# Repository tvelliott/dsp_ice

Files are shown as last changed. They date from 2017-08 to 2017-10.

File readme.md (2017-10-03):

<html>
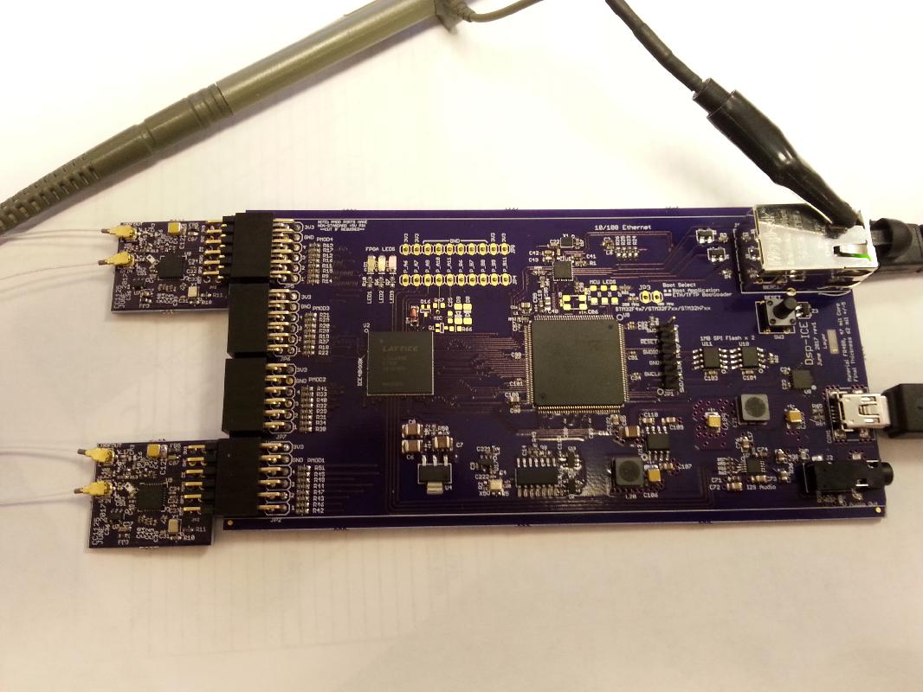
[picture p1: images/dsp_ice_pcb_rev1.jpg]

<BR>
<BR><B>DSP_ICE</B>
<BR>
<B>Project Description</B>
<p>DSP_ICE is an ICE40-8K FPGA dev system that has been developed using gcc and
Project Icestorm toolchains.  The hardware has been fully tested except for the
PDM microphone.  Firmware/HDL examples are provided to test the hardware,
including an 8-channel, multi-waveform audio synthesizer and peak amplitude,
frequency measurement via CMSIS DSP FFT functions utilizing the LTC1420 ADC
expansion module.
</p>
<BR>
<B>Why Develop Another ICE40 Dev Board?</B>
<p>
DSP ICE was developed because other boards didn't have all the features desired.
The ultimate goal is to develop an SDR with swappable analog/RF front-ends.
Desired features that drove the development were:
<BR>1) 10/100 Ethernet
<BR>2) 8K ICE 40 device that could be done with 5mil spaced, 4-layer pcb
<BR>3) I2S audio output
<BR>4) STM32F4 device that is foot-print compatible with F7 and H7 series for future
<BR>5) 16-bit FSMC memory-bus interface between the MCU and FPGA
<BR>6) Low-noise power supplies with plenty of current for expansion modules
<BR>7) Plenty of expansion I/O pins designed to utilize upper limits on frequency with ICE40
</p>

<H3><a href="https://raw.githubusercontent.com/tvelliott/dsp_ice/master/firmware/audio_synth_test/dsp_ice_audio_synth_test.mp3">8-channel audio synth test.mp3</a> audio output from example audio-synth implemented in Verilog</H3> 

<BR>
<BR>
<B>Features:</B>
<BR>
<BR>STM32F417 MCU  (upgradable with drop-in for F7 and H7 series up to 400 MHz)
<BR>ICE40HX8K-CT256 FPGA (largest ICE40 device available)
<BR>16-Bit FSMC interface between MCU <-> FPGA.  Interface clock is running @ 80 MHz
<BR>10-100 Mbps Ethernet interface  (firmware includes iperf3 server for testing bandwidth)
<BR>ST-Link programming header  (can use STM32F4-Discovery as a programming device)
<BR>I2S Audio interface  (firmware includes example of 8-channel audio synth with sawtooth, pulse, noise waveforms and a song playback via I2S)
<BR>4 PMOD-Like ports  (include 5V and 3.3V and 8 I/O pins x 4)
<BR>USB FTDI-based serial interface  (update 8/13/2017 firmware to test the uart interface has been added)
<BR>40 MHz TCXO crystal driving both FPGA and MCU  (MCU clock div/2)

<BR>
<BR>
<B>Verilog Source Is Here</B>
<BR>
<a href="https://github.com/tvelliott/dsp_ice/tree/master/firmware/fpga/src">/firmware/fpga/src</a>
<BR>

<BR>
<B>DSP ICE MCU 16-bit Memory-Mapped FPGA registers</B>
<BR>
<pre>
0x60000000   spi1_ctrl
0x60000002   spi1_data_in
0x60000004   spi1_data_out
0x60000006   spi1_cs_ctrl

0x60000008   spi2_ctrl
0x6000000a   spi2_data_in
0x6000000c   spi2_data_out
0x6000000e   spi2_cs_ctrl

0x60000010   adc_data  (LTC1420 hw module, read-only, bit0 is OF) 

0x60001000   audio_ctrl
0x60001002   left_sample
0x60001004   right_sample
0x60001006   tone1_freq
0x60001008   tone2_freq
0x6000100a   tone3_freq
0x6000100c   tone4_freq
0x6000100e   tone5_freq
0x60001010   tone6_freq
0x60001012   tone7_freq
0x60001014   tone8_freq
0x60001016   waveform_ctrl

0x6000f000   16-bit random number (ro)
</pre>

<B>PCB Design</B>
<BR>4 layers
<BR>Designed for OSH Park 4 layer service.  (5 mil spacing)
<BR>Have assembled 4 boards without any connectivity issues on the 256-pin BGA

<B>Left To Do</B>
<BR>The PDM michrophone has not been tested yet due to trouble getting the part.  
<BR>Digikey has the part in stock, but Cirrus Logic will not allow them to sell 
<BR>it to certain individuals including the author of this project. There were
<BR>no further explanations from Cirrus Logic.
<BR>
<BR>
<B>Building The Firmware</B>
<PRE>
Instructions (tested on Debian 8 system)

1) download GNU ARM Embedded Toolchain from here:

<a href="https://launchpad.net/gcc-arm-embedded"> https://launchpad.net/gcc-arm-embedded </a>

The test firmare was compiled with version:
gcc-arm-none-eabi-5_4-2016q3-20160926-linux.tar.bz2

2) *edit the makedefs_fp and change PRE_PREFIX to point to the absolute path of
the toolchain directory *optionally,  move the uncompressed toolchain folder to
the project folder and rename to gnu_arm_toolchain

3) From the project directory, In order to re-build the FPGA binary image, type
'sh build_fpga_image.sh'  (requires that Project Icestorm tools are installed)

  yosys  (synthesis tool)  <a href="http://www.clifford.at/icestorm/"> http://www.clifford.at/icestorm/</a>
  ice-tools  (tools for maniuplating text/binaries and programming dev boards) 
  arache-pnr  (place-and-route)  <a href="https://github.com/cseed/arachne-pnr"> https://github.com/cseed/arachne-pnr </a>

  Note:  The fpga binary configuration image will be compressed and converted
to a header file for inclusion to the MCU firmware image:  fpga_image.h The
compressed image in fpga_image.h will be included in fpga.c on the next mcu
firmware build  (step 4) The MCU uncompresses and transfers the fpga config
image during startup.

4) From the project directory, type 'make clean' followed by  'make' The
resulting binary will be copied to /tmp folder and also the build_image folder
in the current project directory Note: the prototypes in protos can be
re-generated with 'make genprotos' if cfunctions is installed.

5) An ST-Link programmer can be used to load the resulting binary
(main_image_0x8000000.bin) to address 0x8000000

   A $15 STM32F4 Discovery board with the jumpers set to "ST Link"  (pulled
off) and a straight-thru, 6-pin 0.1" pitch cable will work.

   Follow instructions for compiling OpenOCD  <a href="http://openocd.org/"> http://openocd.org/</a>

   start the debugger:  'sudo src/openocd -s tcl -f tcl/board/stm32f4discovery.cfg'

   'telnet localhost 4444'
    > reset halt
    > flash write_image erase build_image/main_image_0x8000000.bin 0x8000000

6) Test the hardware.
   telnet 192.168.1.240   (default ip address.  edit this in config.c)
   
Trying 192.168.1.240...
Connected to 192.168.1.240.
Escape character is '^]'.

Connected To STM32F417 Running @ 168 MHz
DSP_Ice 192.168.1.240:~$ help

Available commands:

testmem
testsnd
testflash1
testflash2
testadc
reset
exit

DSP_Ice 192.168.1.240:~$ testadc
<B>Example measurement of 500 KHz sine wave, 100mVpp utilize LTC1420 ADC HW module</B>
<B>This example utilizes the CMSIS DSP Co-Processor functions of the MCU for FFT calcs.</B>
<B>Using DMA to transfer ADC results from FPGA BRAM would dramatically improve sample rate</B>
peak signal 502675.781 Hz,  0.107 Volts p-p, elapsed time 3.51 ms  
<a href="https://github.com/tvelliott/dsp_ice/blob/master/hw_modules/ltc1420_adc/fft_plot_500khz_100mVpp.gif">[see fft plot 500khz, 100mV p-p]</a> 
<a href="https://github.com/tvelliott/dsp_ice/blob/master/hw_modules/ltc1420_adc/ltc1420_capture_3.5vpp_no_filter_325khz_freqdomain.gif">[see fft plot 325Khz, 3500mV p-p]</a> 
<a href="https://github.com/tvelliott/dsp_ice/blob/master/hw_modules/ltc1420_adc/ltc1420_capture_3.5vpp_no_filter_500khz_timedomain.gif">[see time-domain plot 500khz, 3500mV p-p]</a> 
 
DSP_Ice 192.168.1.240:~$ testmem   (this tests the 16-bit FSMC memmory-mapped, MCU<->FPGA interface)

x100x (FPGA D-REG), 4015677440 bytes r/w random access, current vals: f3e7,f3e7, errors: 0
0x100x (FPGA D-REG), 4015685632 bytes r/w random access, current vals: 69c4,69c4, errors: 0
0x100x (FPGA D-REG), 4015693824 bytes r/w random access, current vals: af9a,af9a, errors: 0
0x100x (FPGA D-REG), 4015702016 bytes r/w random access, current vals: bc6a,bc6a, errors: 0
0x100x (FPGA D-REG), 4015710208 bytes r/w random access, current vals: 8732,8732, errors: 0
0x100x (FPGA D-REG), 4015718400 bytes r/w random access, current vals: 06f4,06f4, errors: 0
0x100x (FPGA D-REG), 4015726592 bytes r/w random access, current vals: 32af,32af, errors: 0
.....

DSP_Ice 192.168.1.240:~$ sh test_iperf.sh

Connecting to host 192.168.1.240, port 5201
[  4] local 192.168.1.3 port 45612 connected to 192.168.1.240 port 5201
[ ID] Interval           Transfer     Bandwidth       Retr  Cwnd
[  4]   0.00-1.00   sec  8.91 MBytes  74.7 Mbits/sec    0   14.3 KBytes       
[  4]   1.00-2.00   sec  8.88 MBytes  74.5 Mbits/sec    0   14.3 KBytes       
[  4]   2.00-3.00   sec  8.86 MBytes  74.3 Mbits/sec    0   14.3 KBytes       
[  4]   3.00-4.00   sec  8.86 MBytes  74.3 Mbits/sec    0   14.3 KBytes       
[  4]   4.00-5.00   sec  8.88 MBytes  74.5 Mbits/sec    0   14.3 KBytes       
[  4]   5.00-6.00   sec  8.87 MBytes  74.4 Mbits/sec    0   14.3 KBytes       
[  4]   6.00-7.00   sec  8.86 MBytes  74.3 Mbits/sec    0   14.3 KBytes       
[  4]   7.00-8.00   sec  8.86 MBytes  74.3 Mbits/sec    0   14.3 KBytes       
[  4]   8.00-9.00   sec  8.86 MBytes  74.3 Mbits/sec    0   14.3 KBytes       

iperf Done.

....
DSP_Ice 192.168.1.240:~$ testsnd   (song playback via 8-channel audio synth implemented on fpga)

change instrument: ch: 0,  instr: 29, mask: 5555
chan: 0, freq: 554
change instrument: ch: 1,  instr: 37, mask: 5555
chan: 1, freq: 92
change instrument: ch: 2,  instr: 16, mask: 5575
chan: 2, freq: 233
change instrument: ch: 3,  instr: 29, mask: 5575
chan: 3, freq: 370
change instrument: ch: 4,  instr: 16, mask: 5775
chan: 4, freq: 131
change instrument: ch: 5,  instr: 16, mask: 5f75
chan: 5, freq: 131
duration: 91
duration: 91
chan: 0, freq: 494
chan: 3, freq: 330
duration: 91
duration: 91
chan: 2, freq: 208
chan: 0, freq: 554
chan: 3, freq: 370
duration: 91
duration: 91
chan: 0, freq: 494
chan: 3, freq: 330
duration: 91
duration: 91
chan: 0, freq: 554
chan: 3, freq: 370
duration: 91
duration: 91

<B>Images Of LTC1420 HW Module and PCB cad rendering</B>
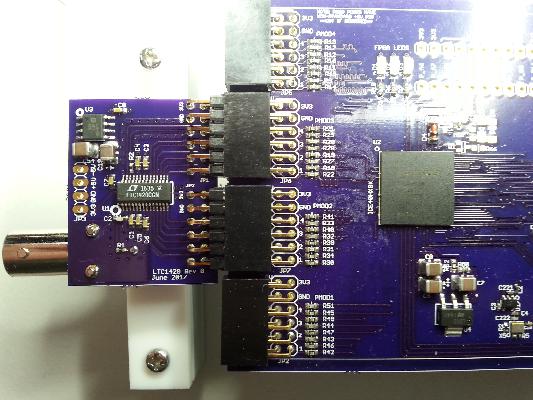
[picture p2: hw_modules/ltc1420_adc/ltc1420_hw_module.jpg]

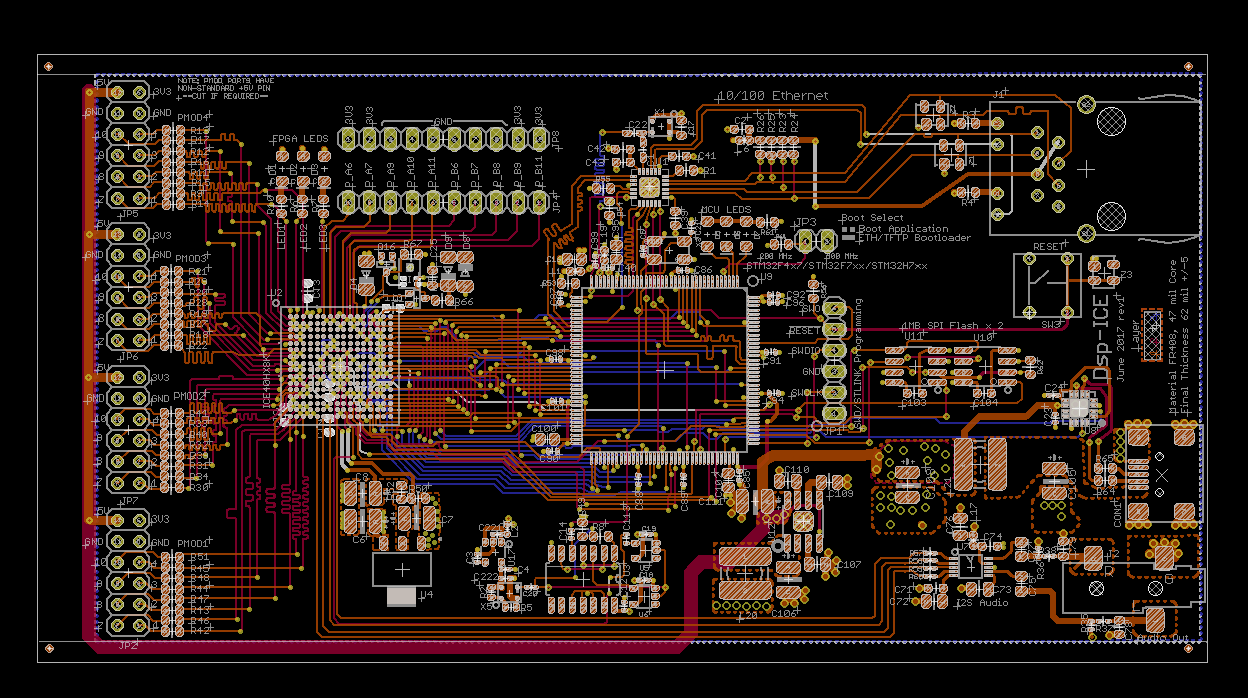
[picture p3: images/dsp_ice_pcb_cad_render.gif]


....
</PRE>

<B>Links To Similar Projects</B>
<BR>
<a href="https://github.com/emeb/iceRadio">https://github.com/emeb/iceRadio</a>
<BR><BR>
<B>Links To Related Resources</B>
<BR>
<BR><a href="https://launchpad.net/gcc-arm-embedded"> https://launchpad.net/gcc-arm-embedded </a>
<BR><a href="http://www.clifford.at/icestorm/"> http://www.clifford.at/icestorm/</a>
<BR><a href="https://github.com/cseed/arachne-pnr"> https://github.com/cseed/arachne-pnr </a>
<BR><a href="http://openocd.org/"> http://openocd.org/</a>

</html>

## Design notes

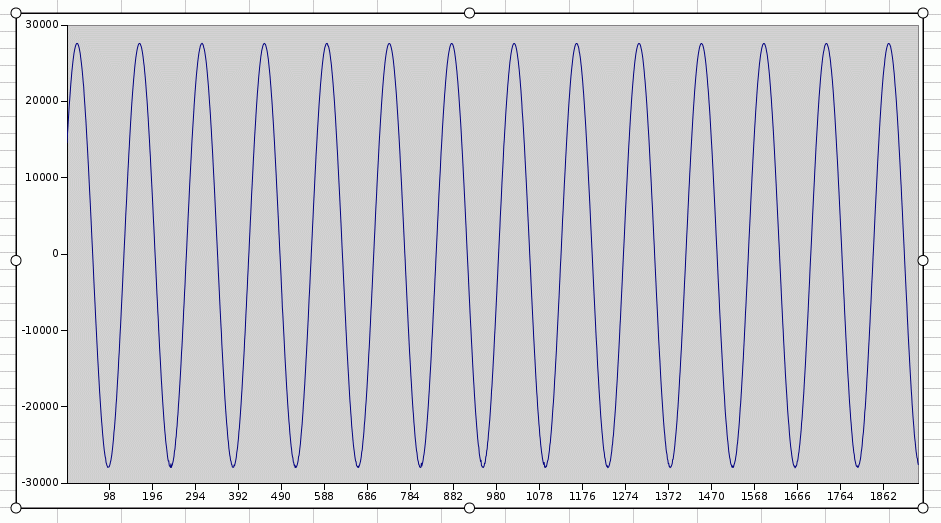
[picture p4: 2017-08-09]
hw_modules/ltc1420_adc/ltc1420_capture_3.5vpp_no_filter_500khz_timedomain.gif

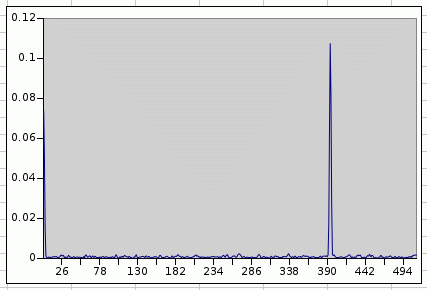
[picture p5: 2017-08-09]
hw_modules/ltc1420_adc/fft_plot_500khz_100mVpp.gif

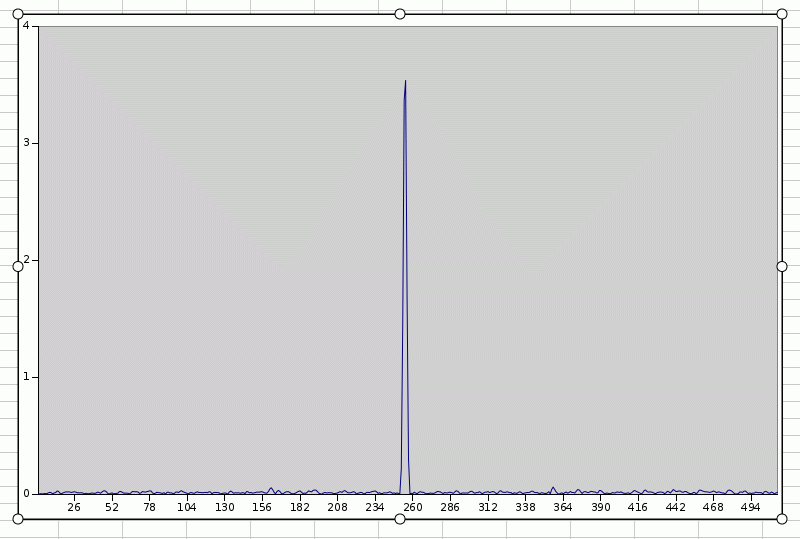
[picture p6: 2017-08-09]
hw_modules/ltc1420_adc/ltc1420_capture_3.5vpp_no_filter_325khz_freqdomain.gif

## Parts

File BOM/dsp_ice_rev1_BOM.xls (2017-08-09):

Qty | Value | MANUFACTURER | MFG PART# | DK PART# | Package | Ref Designator | NOTES | Description
3 |  | Nexperia USA Inc. | BAS85,115 | 1727-2899-1-ND | MINIMELF | D4, D8, D9 |  | Diode Schottky 30V 200mA Surface Mount LLDS; MiniMelf
2 | RED | Kingbright | APT3216LSECK/J3-PRV | 754-1940-1-ND | 1206 | D1, D5 |  | Red 625nm LED Indication - Discrete 1.8V 1206 (3216 Metric)
2 | GREEN | Kingbright | APT3216LZGCK | 754-1944-1-ND | 1206 | D2, D6 |  | Green 525nm LED Indication - Discrete 2.65V 1206 (3216 Metric)
2 | YELLOW | Kingbright | APT3216LSYCK/J3-PRV | 754-1942-1-ND | 1206 | D3, D7 |  | Yellow 590nm LED Indication - Discrete 1.85V 1206 (3216 Metric)
1 |  | Wurth Electronics Inc | 61300611121 | 732-5319-ND | 1X06 | JP1 |  | 6 Positions Header, Unshrouded Connector 0.100" (2.54mm) Through Hole Gold
4 |  | Sullins Connector Solutions | PPPC062LJBN-RC | S5559-ND | 2X06 | JP2, JP5, JP6, JP7 | PMOD CONNECTOR | 12 Position Header Connector 0.100" (2.54mm) Through Hole, Right Angle Gold
1 |  | Taiyo Yuden | BK1005HM102-T | 587-1835-1-ND | 0402 | L2 |  | FERRITE BEAD 1 KOHM 0402 1LN
4 |  | TDK Corporation | MMZ1608S102ATA00 | 445-1550-1-ND | 0603 | L1, L6, L17, L19 |  | FERRITE BEAD 1 KOHM 0603 1LN
1 | .01uF | Murata Electronics North America | GRM155R71H103KA88D | 490-4516-1-ND | 0402 | C3 |  | 10000pF ±10% 50V Ceramic Capacitor X7R 0402 (1005 Metric)
9 | 0.1uF | Yageo | CC0603ZRY5V9BB104 | 311-1343-1-ND | 0603 | C2, C9, C17, C39, C41, C71, C74, C103, C104 |  | 0.1µF -20%, +80% 50V Ceramic Capacitor Y5V (F) 0603 (1608 Metric
14 | 0.1uF | Murata Electronics North America | GRM155R71C104KA88J | 490-6328-1-ND | 0402 | C40, C85, C86, C87, C88, C89, C90, C91, C92, C94, C96, C98, C99, C101 |  | 0.1µF ±10% 16V Ceramic Capacitor X7R 0402 (1005 Metric)
4 | 1.0uF | Taiyo Yuden | JMK105BJ105KV-F | 587-1231-1-ND | 0402 | C4, C221, C23, C24 |  | 1µF ±10% 6.3V Ceramic Capacitor X5R 0402 (1005 Metric)
39 | 10 | Yageo | RC0603FR-0710RL | 311-10.0HRCT-ND | 0603 | R9, R11, R12, R13, R14, R15, R16, R17, R18, R19, R20, R21, R22, R27, R28, R29, R30, R31, R32, R33, R34, R39, R40, R41, R42, R43, R44, R45, R46, R47, R48, R51, R52, R57, R58, R59, R60, R64, R65 |  | 10 Ohm ±1% 0.1W, 1/10W Chip Resistor 0603 (1608 Metric) Moisture Resistant Thick Film
2 | 100pF | Johanson Technology Inc. | 251R14S101JV4T | 712-1310-1-ND | 0603 | C1, C22 |  | 100pF ±5% 250V Ceramic Capacitor C0G, NP0 0603 (1608 Metric)
2 | 10k | Vishay Dale | CRCW040210K0FKED | 541-10.0KLCT-ND | 0402 | R35, R36 |  | 10k Ohm ±1% 0.063W, 1/16W Chip Resistor 0402 (1005 Metric) Automotive AEC-Q200 Thick Film
2 | 10uF | Murata Electronics North America | GRM21BR60J106ME19L | 490-1718-1-ND | 0805 | C72, C73 |  | 10µF ±20% 6.3V Ceramic Capacitor X5R 0805 (2012 Metric)
7 | 12.1k | Yageo | RC0603FR-0712K1L | 311-12.1KHRCT-ND | 0603 | R1, R53, R54, R55,R56, R62, R63 |  | 12.1k Ohm ±1% 0.1W, 1/10W Chip Resistor 0603 (1608 Metric) Moisture Resistant Thick Film
1 | 120 | Yageo | RC0603JR-07120RL | 311-120GRCT-ND | 0603 | R50 |  | 120 Ohm ±5% 0.1W, 1/10W Chip Resistor 0603 (1608 Metric) Moisture Resistant Thick Film
1 |  | TE Connectivity AMP Connectors | 1734035-2 | A31727CT-ND |  | CON1 |  | USB - mini B USB 2.0 Receptacle Connector 5 Position Surface Mount, Right Angle
1 | 18pF | AVX Corporation | 04025A180JAT2A | 478-1073-1-ND | 0402 | C222 |  | 18pF ±5% 50V Ceramic Capacitor C0G, NP0 0402 (1005 Metric)
6 | 1uF | Murata Electronics North America | GRM188R61C105KA93D | 490-1536-1-ND | 0603 | C10, C11, C13, C15, C42, C25 |  | 1µF ±10% 16V Ceramic Capacitor X5R 0603 (1608 Metric)
10 | 2.2uF | Murata Electronics North America | GRM21BR70J225KA01L | 490-1698-1-ND | 0805 | C16, C75, C76, C77, C95, C100, C102, C107, C109, C110 |  | 2.2µF ±10% 6.3V Ceramic Capacitor X7R 0805 (2012 Metric)
4 | 22uF | Taiyo Yuden | JMK325BJ226MM-T | 587-1384-1-ND | 1210 | C6, C7, C8, C111 |  | 22µF ±20% 6.3V Ceramic Capacitor X5R 1210 (3225 Metric)
2 | 22uH_744053220 | Wurth Electronics Inc | 744053220 | 732-1047-1-ND | 2323 | L20, L21 |  | 22µH Shielded Wirewound Inductor 1.15A 120 mOhm Max 2323 (5858 Metric)
6 | 270 | Yageo | RC0603JR-07270RL | 311-270GRCT-ND | 0603 | R3, R4, R6, R7, R10, R61 |  | 270 Ohm ±5% 0.1W, 1/10W Chip Resistor 0603 (1608 Metric) Moisture Resistant Thick Film
4 | 4.87K | Vishay Dale | CRCW06034K87FKEA | 541-4.87KHCT-ND | 0603 | R8, R49, R66, R67 |  | 4.87k Ohm ±1% 0.1W, 1/10W Chip Resistor 0603 (1608 Metric) Automotive AEC-Q200 Thick Film
4 | 470 (Tc=50ppm) | Vishay Dale | CRCW0402470RFKED | 541-470LCT-ND | 0402 | R2, R5, R37, R38 |  | 470 Ohm ±1% 0.063W, 1/16W Chip Resistor 0402 (1005 Metric) Automotive AEC-Q200 Thick Film
1 | 470pF | KEMET | C0603C471F5GACTU | 399-7919-1-ND | 0603 | C43 |  | 470pF ±1% 50V Ceramic Capacitor C0G, NP0 0603 (1608 Metric)
3 | 470uF_tant | AVX Corporation | F950G477MBAAQ2 | 478-8384-1-ND | 1210 | C105, C106, C108 |  | 470µF ±20% Conformal Coated Tantalum Capacitors 4V 1210 (3528 Metric) 400 mOhm
6 | 47nF | Murata Electronics North America | GRM155R71E473KA88D | 490-3254-1-ND | 0402 | C12, C14, C18, C19, C20, C113 |  | 0.047µF ±10% 25V Ceramic Capacitor X7R 0402 (1005 Metric)
4 | 49.9 | Vishay Dale | CRCW060349R9FKEA | 541-49.9HCT-ND | 0603 | R23, R24, R25, R26 |  | 49.9 Ohm ±1% 0.1W, 1/10W Chip Resistor 0603 (1608 Metric) Automotive AEC-Q200 Thick Film
2 |  | Texas Instruments | SN74LVC1G04DBVR | 296-11599-1-ND | SOT23-5 | U5, U6 |  | IC SINGLE INVERTER-GATE SOT-23-5
2 | 8200pF | TDK Corporation | C1608C0G1E822J080AA | 445-2668-1-ND | 0603 | C78, C79 |  | 8200pF ±5% 25V Ceramic Capacitor C0G, NP0 0603 (1608 Metric)
1 |  | Analog Devices Inc. | ADP7156ARDZ-3.3-R7 | ADP7156ARDZ-3.3-R7CT-ND | SO8 | U12 |  | Linear Voltage Regulator IC Positive Fixed 1 Output 3.3V 1.2A 8-SOIC Exposed Pad
1 | 50mhz | Abracon LLC | ASDM1-50.000MHZ-LC-T | 535-9801-1-ND | 2.5mm x 2mm | X1 |  | 50Mhz LVCMOS MEMS (Silicon) Oscillator Surface Mount 3.3V 10mA Standby (Power Down)
1 | 40mhz | Abracon LLC | ASVTX-12-A-40.000MHZ-I15-T | 535-11793-1-ND | 2.5mm x 2mm | X5 |  | 40Mhz Clipped Sine Wave VCTCXO Oscillator Surface Mount 3V 2.5mA
1 |  | Cirrus Logic Inc. | CS4344-DZZ | 598-1634-ND | 10-TSSOP | U7 |  | DAC, Audio 24 bit 192k SPI 10-TSSOP
1 |  | Lattice Semiconductor Corporation | ICE40HX8K-CT256 | 220-1575-ND | CABGA256 | U2 |  | IC FPGA 206 I/O 256CABGA
1 |  | Microchip Technology | LAN8742AI-CZ | LAN8742AI-CZ-ND | QFN-24 | U1 |  | 1/1 Transceiver Full Ethernet 24-SQFN (4x4)
1 |  | STMicroelectronics | LD1117S12TR | 497-4240-1-ND | SOT-223 | U4 |  | Linear Voltage Regulator IC Positive Fixed Output 1.2V 800mA SOT-223
2 |  | Cypress Semiconductor Corp | S25FL116K0XMFI041 | 1274-1106-ND | SO8 | U10, U11 |  | IC FLASH 16MBIT 108MHZ 8SOIC
1 |  | Stewart Connector | SI-50170-F | 380-1103-ND | SI-50170 | J1 |  | 1 Port RJ45 Magjack Connector Through Hole 10/100 Base-T, AutoMDIX
1 |  | CUI Inc | SJ-3523-SMT-TR | CP-3523SJCT-ND | 3523 | J2 |  | 3.50mm (0.141", 1/8", Mini Plug) - Headphone Phone Jack Stereo Connector Solder
1 |  | ON Semiconductor | MC74AC74DR2G | MC74AC74DR2GOSCT-ND | SO14 | U3 |  | IC D-TYPE POS TRG DUAL 14SOIC
3 |  | Semtech Corporation | SR3.3.TCT | SR3.3CT-ND | SR2.8.TCT_1PRIMARY | Z1, Z2, Z3 |  | TVS DIODE 3.3VWM 15VC SOT143
1 |  | STMicroelectronics | STM32F765ZGT6 | 497-16632-ND | TQFP-144 | U9 |  | ARM® Cortex®-M7 STM32 F7 Microcontroller IC 32-Bit 216Mhz 1MB (1M x 8) FLASH, 512KB RAM, 144-LQFP (20x20)
1 |  | Texas Instruments | TPS79930DDCR | 296-39500-1-ND | SOT23-6 | U17 |  | Linear Voltage Regulator IC Positive Fixed Output 3V 200mA SOT-23-5
1 |  | FTDI, Future Technology Devices International Ltd | FT230XQ-R | 768-1130-1-ND | 16-QFN | U8 |  | USB Bridge, USB to UART USB 2.0 UART Interface 16-QFN (4x4)
1 |  | Cirrus Logic Inc. | CS7250B-CAZR | 598-2449-1-ND | BOTTOM PORT | U13 |  | 35Hz ~ 13kHz Digital, PDM Microphone MEMS (Silicon) 1.8V Omnidirectional (-36dB ±1dB @ 94dB SPL)
2 |  | Diodes Incorporated | 2N7002W-7-F | 2N7002W-FDICT-ND | MINIMELF | Q1,Q16 |  | N-Channel 60V 115mA (Ta) 200mW (Ta) Surface Mount SOT-323
DNP |  | JP4, JP8
 |  | X3, C5, C21
Document History
elliott | 2017-05-15 | creation | rev0
elliott | 2017-June-27 | add R57, R58, R59, R60 | rev1
 |  | add R53,R54,R55,R56 | rev1
 |  | change package on C105, C108 | rev1
 |  | add D5, D6, D7 | rev1
 |  | add R61 | rev1
 |  | add X3, C5, C21 DNP | rev1
 |  | add R62 | rev1
 |  | add U8 | rev1
 |  | add R65 | rev1
 |  | add C24 | rev1
 |  | add C23 | rev1
 |  | add R64 | rev1
 |  | add R63 | rev1
 |  | add SW3 | rev1
 |  | add Z3 | rev1
 |  | add U13 | rev1
 |  | add Q1 | rev1
 |  | add Q16 | rev1
 |  | add R67 | rev1
 |  | add R66 | rev1
 |  | add D8 | rev1
 |  | add D9 | rev1
 |  | add C25 | rev1

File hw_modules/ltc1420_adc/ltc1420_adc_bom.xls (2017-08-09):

Qty | Value | MANUFACTURER | MFG PART# | DK PART# | Package | Ref Designator | NOTES | Description
2 |  | Sullins Connector Solutions | PRPC006DBAN-M71RC | S2111EC-06-ND | 2X06 | JP1, JP2 |  | 12 Positions Header, Breakaway Connector 0.100" (2.54mm) Through Hole, Right Angle Gold
1 |  | Molex | 731000105 | WM5524-ND | BNC | J1 |  | BNC Connector Receptacle, Female Socket 50 Ohm Through Hole, Right Angle Solder
7 | 1uF | Murata Electronics North America | GRM188R61C105KA93D | 490-1536-1-ND | 0603 | C1, C3, C4, C5, C6, C7, C8 |  | 1µF ±10% 16V Ceramic Capacitor X5R 0603 (1608 Metric)
2 | 22uF | Taiyo Yuden | JMK325BJ226MM-T | 587-1384-1-ND | 1210K | C19, C54 |  | 22µF ±20% 6.3V Ceramic Capacitor X5R 1210 (3225 Metric)
2 | 30 | Yageo | RC0402JR-0730RL | 311-30JRCT-ND | R0402 | R1, R2 |  | 30 Ohm ±5% 0.063W, 1/16W Chip Resistor 0402 (1005 Metric) Moisture Resistant Thick Film
1 | 470pF | Murata Electronics North America | GRM1885C2A471JA01D | 490-1367-1-ND | C0603 | C2 |  | 470pF ±5% 100V Ceramic Capacitor C0G, NP0 0603 (1608 Metric)
1 | ADM660 | Analog Devices Inc. | ADM660ARZ-REEL7 | ADM660ARZ-REEL7CT-ND | SO8 | U3 |  | Charge Pump Switching Regulator IC Positive or Negative Fixed -Vin, 2Vin 1 Output 100mA 8-SOIC (0.154", 3.90mm Width)
1 | LTC1420CGNPBF | Linear Technology | LTC1420CGN#PBF | LTC1420CGN#PBF-ND | SSOP-28_GN | U1 |  | 12 Bit Analog to Digital Converter 1 Input 1 Pipelined 28-SSOP
 | DNP | JP3
 | HISTORY
 | t.elliott | 2017-06-28 | document creation.

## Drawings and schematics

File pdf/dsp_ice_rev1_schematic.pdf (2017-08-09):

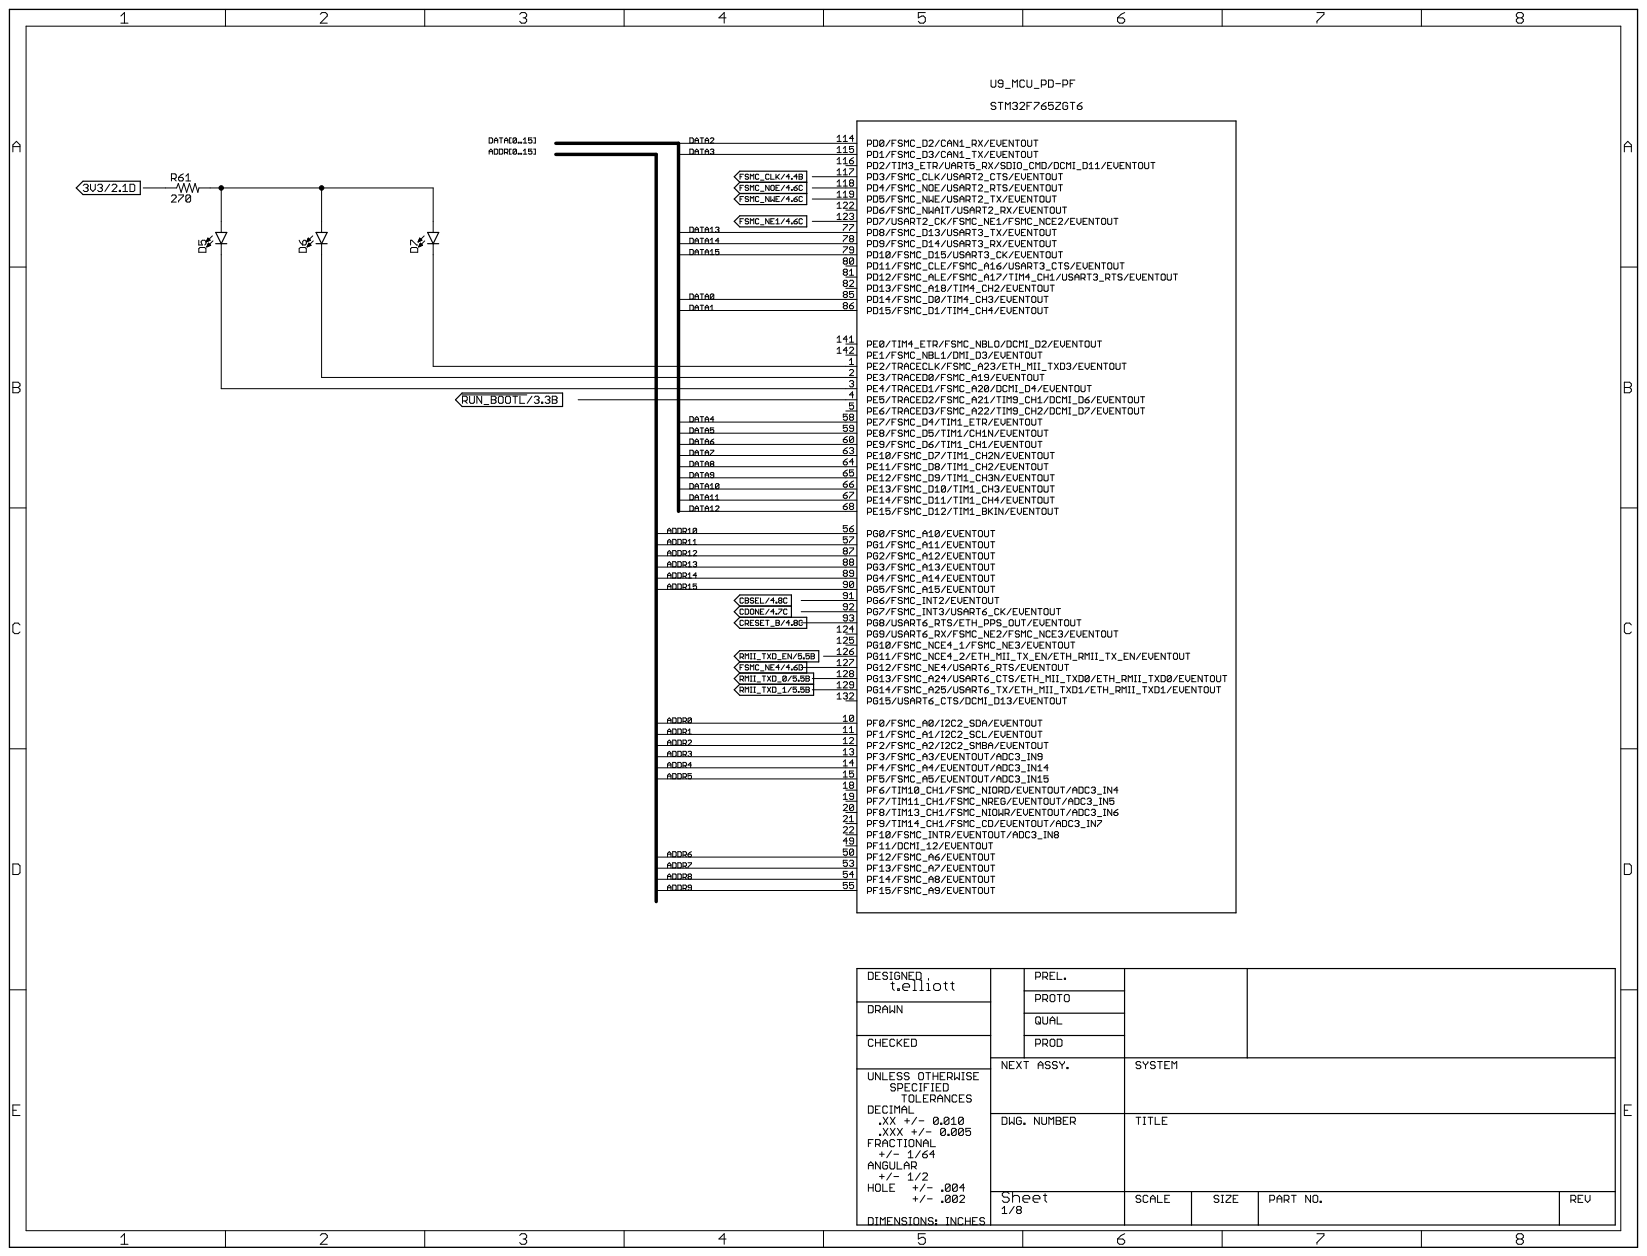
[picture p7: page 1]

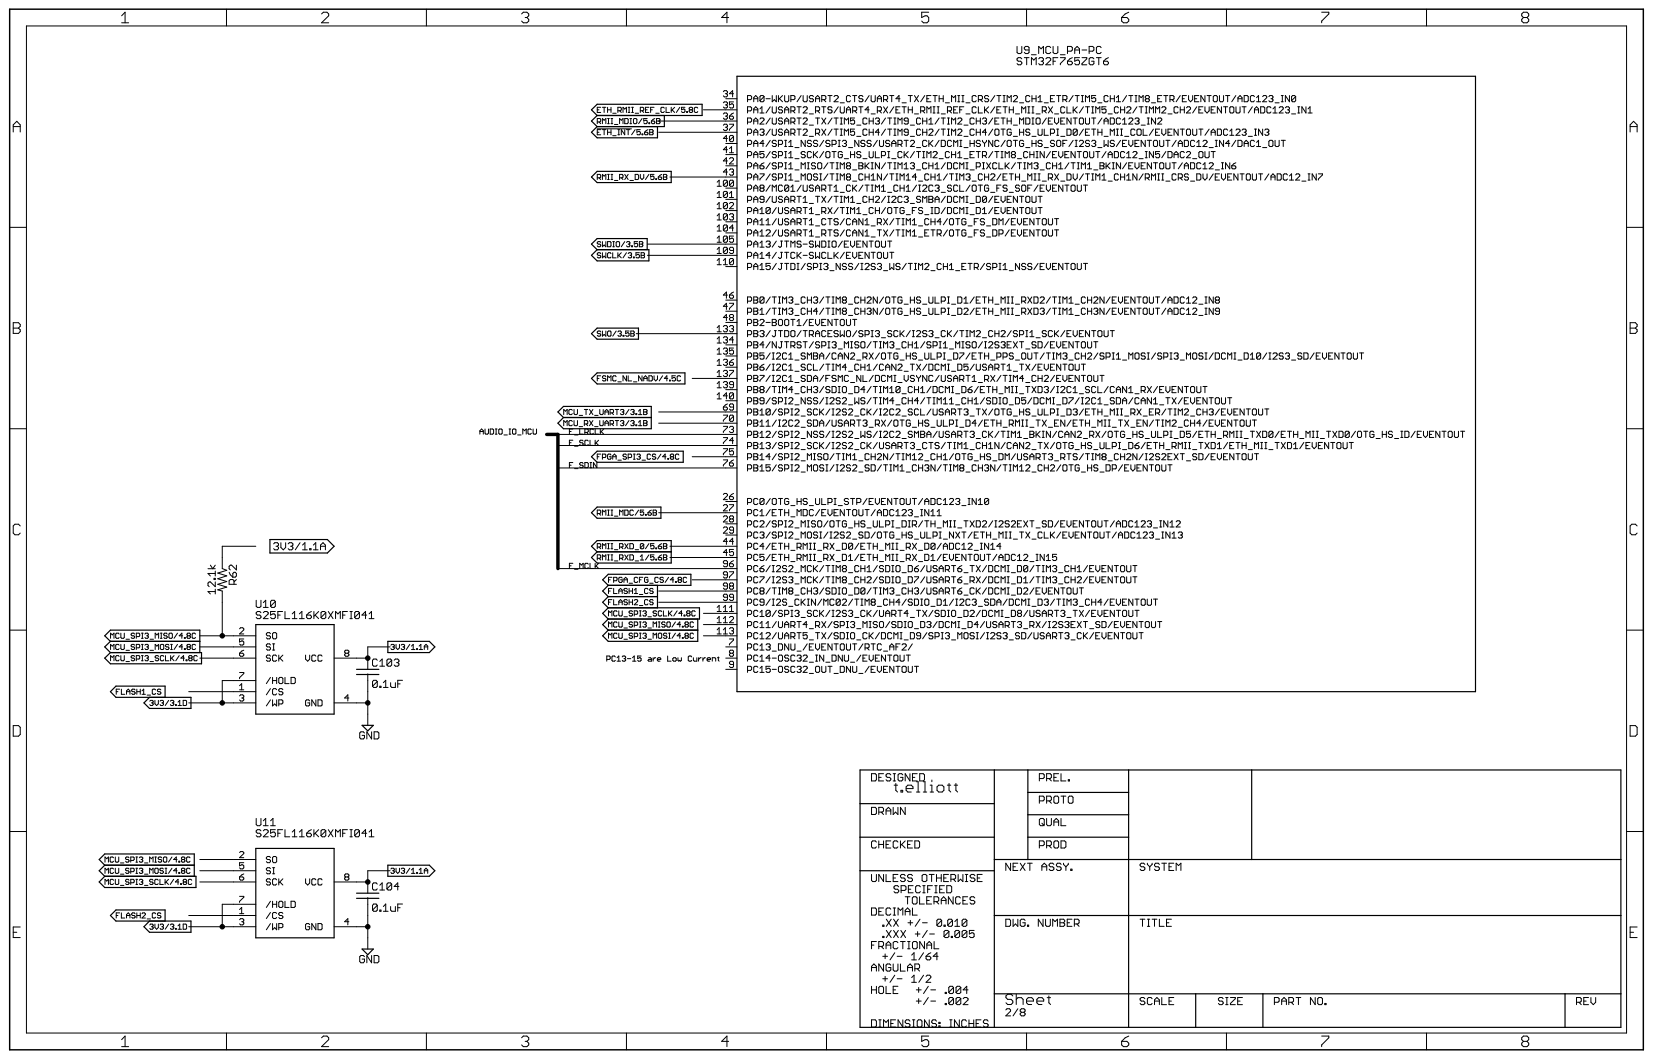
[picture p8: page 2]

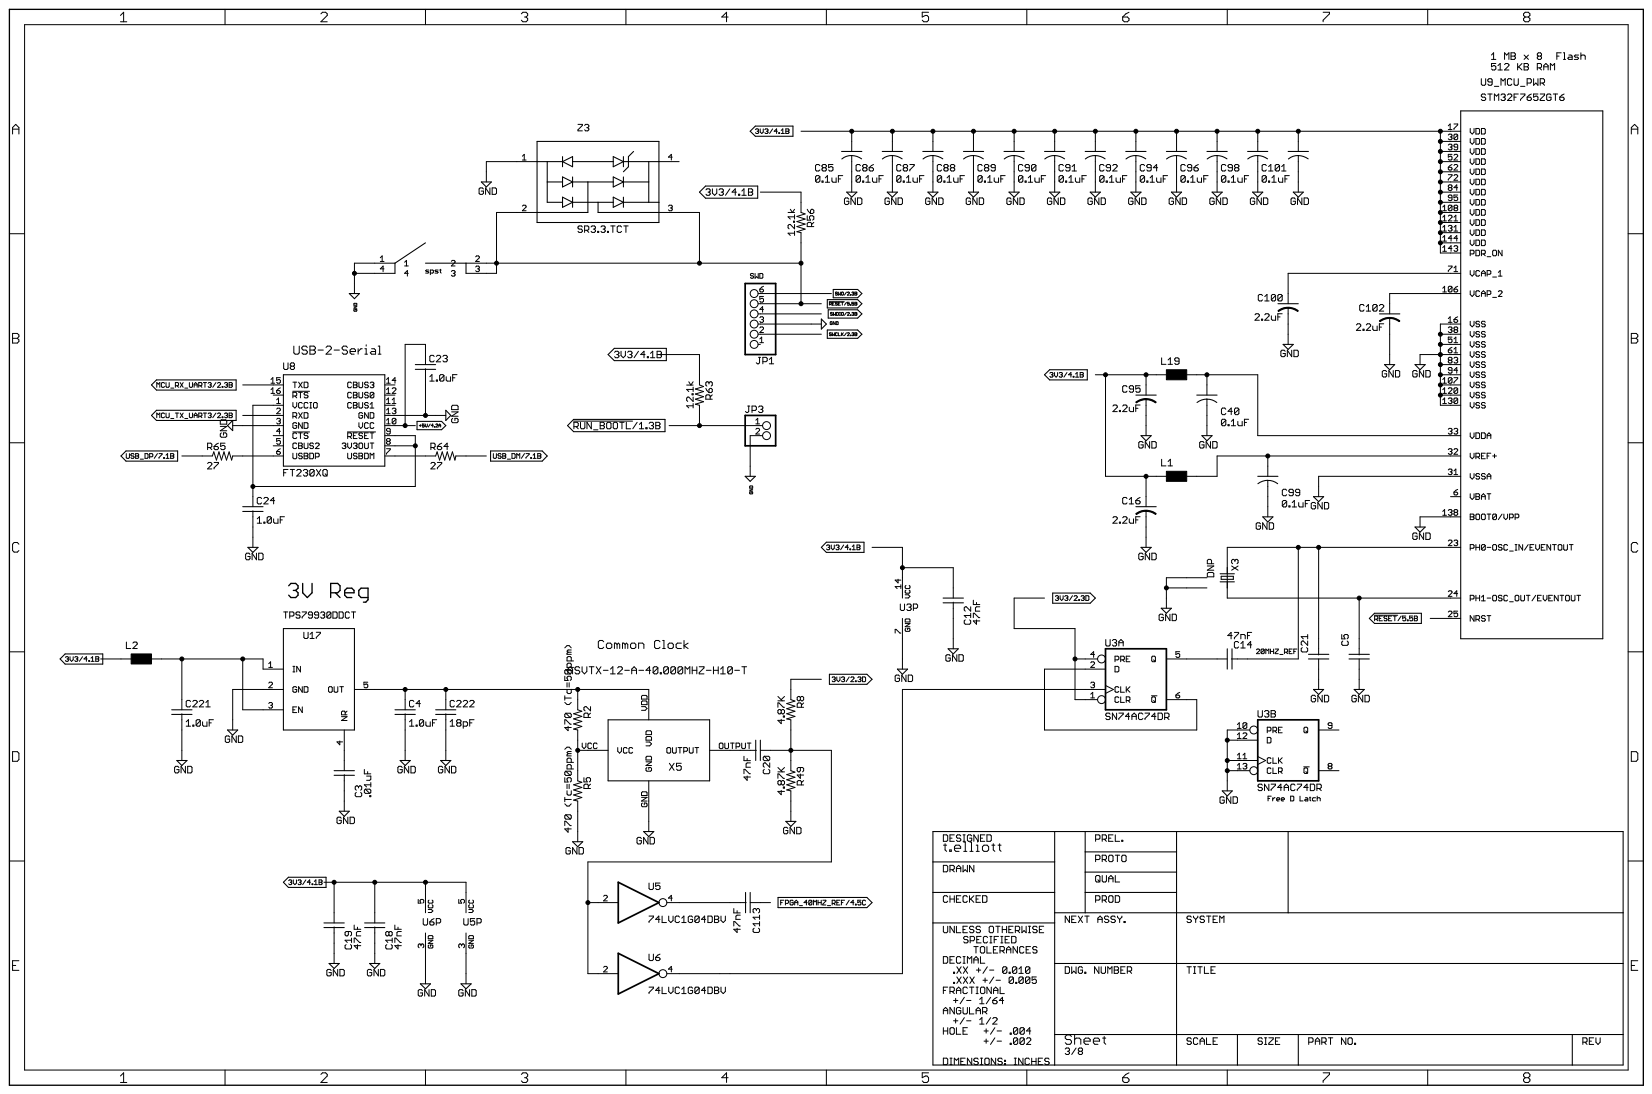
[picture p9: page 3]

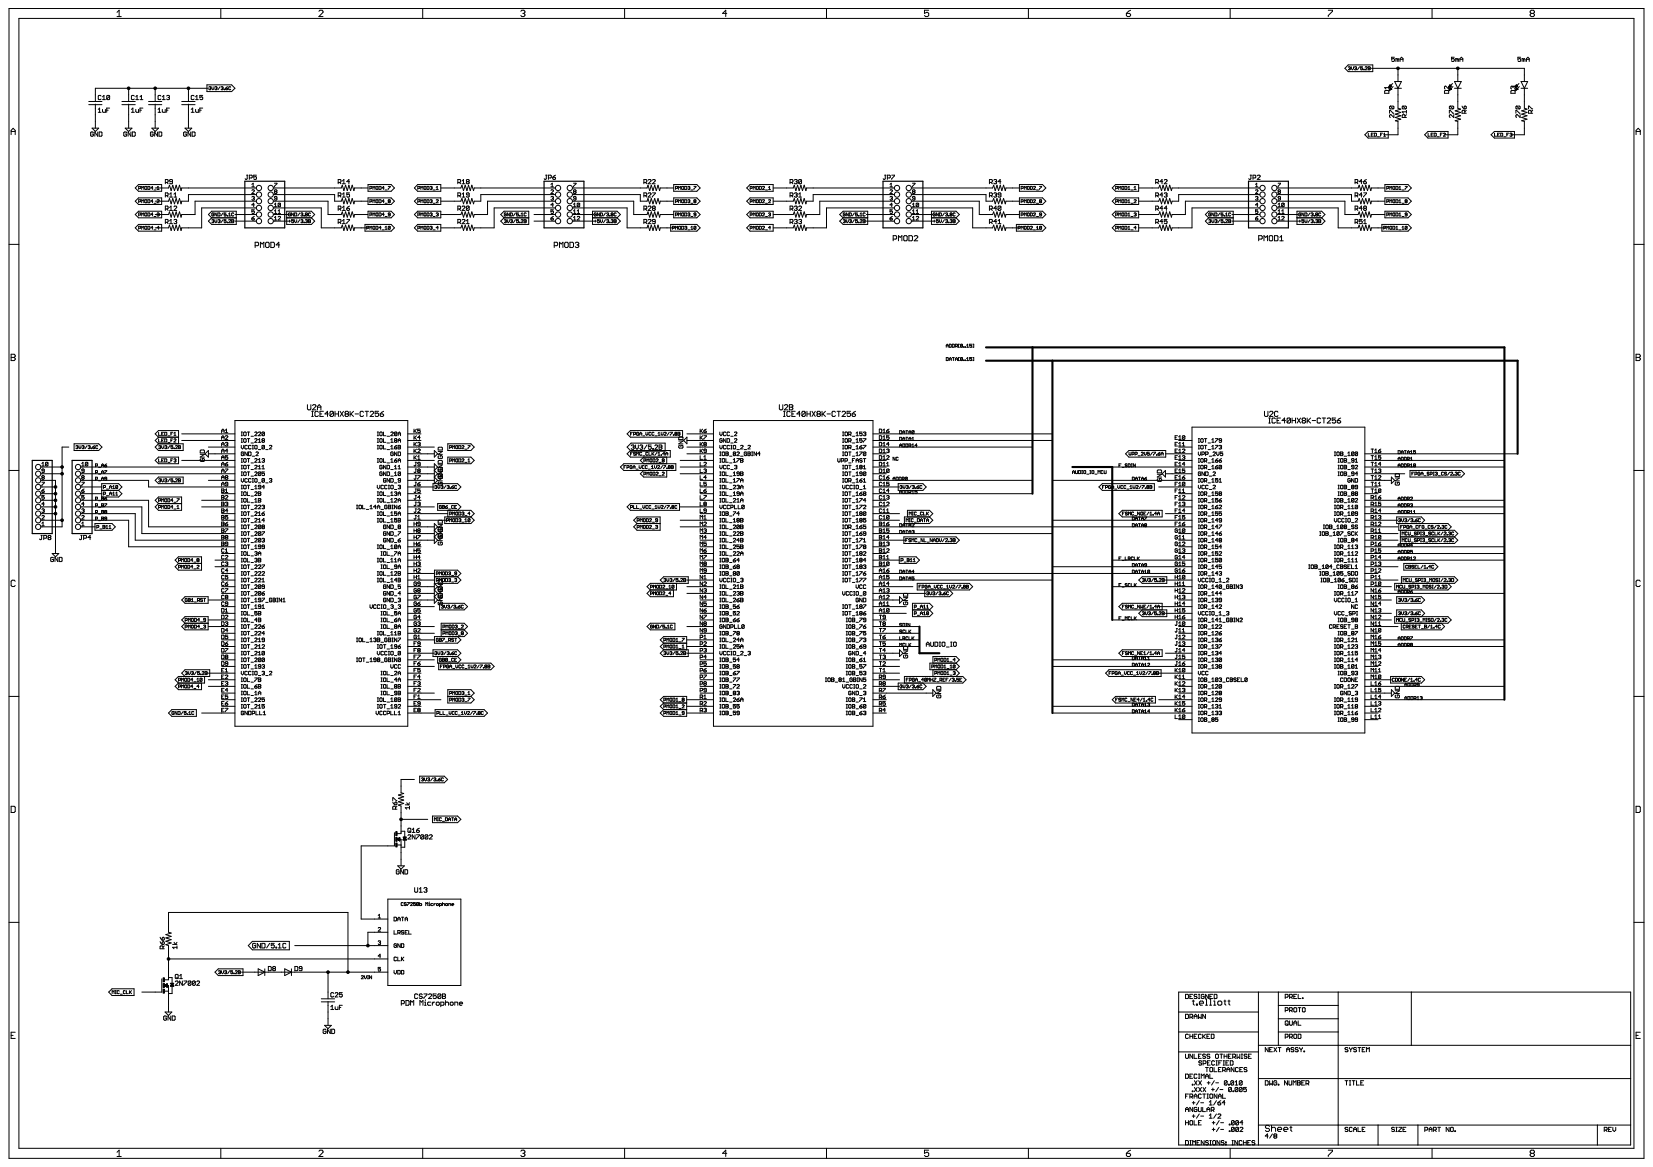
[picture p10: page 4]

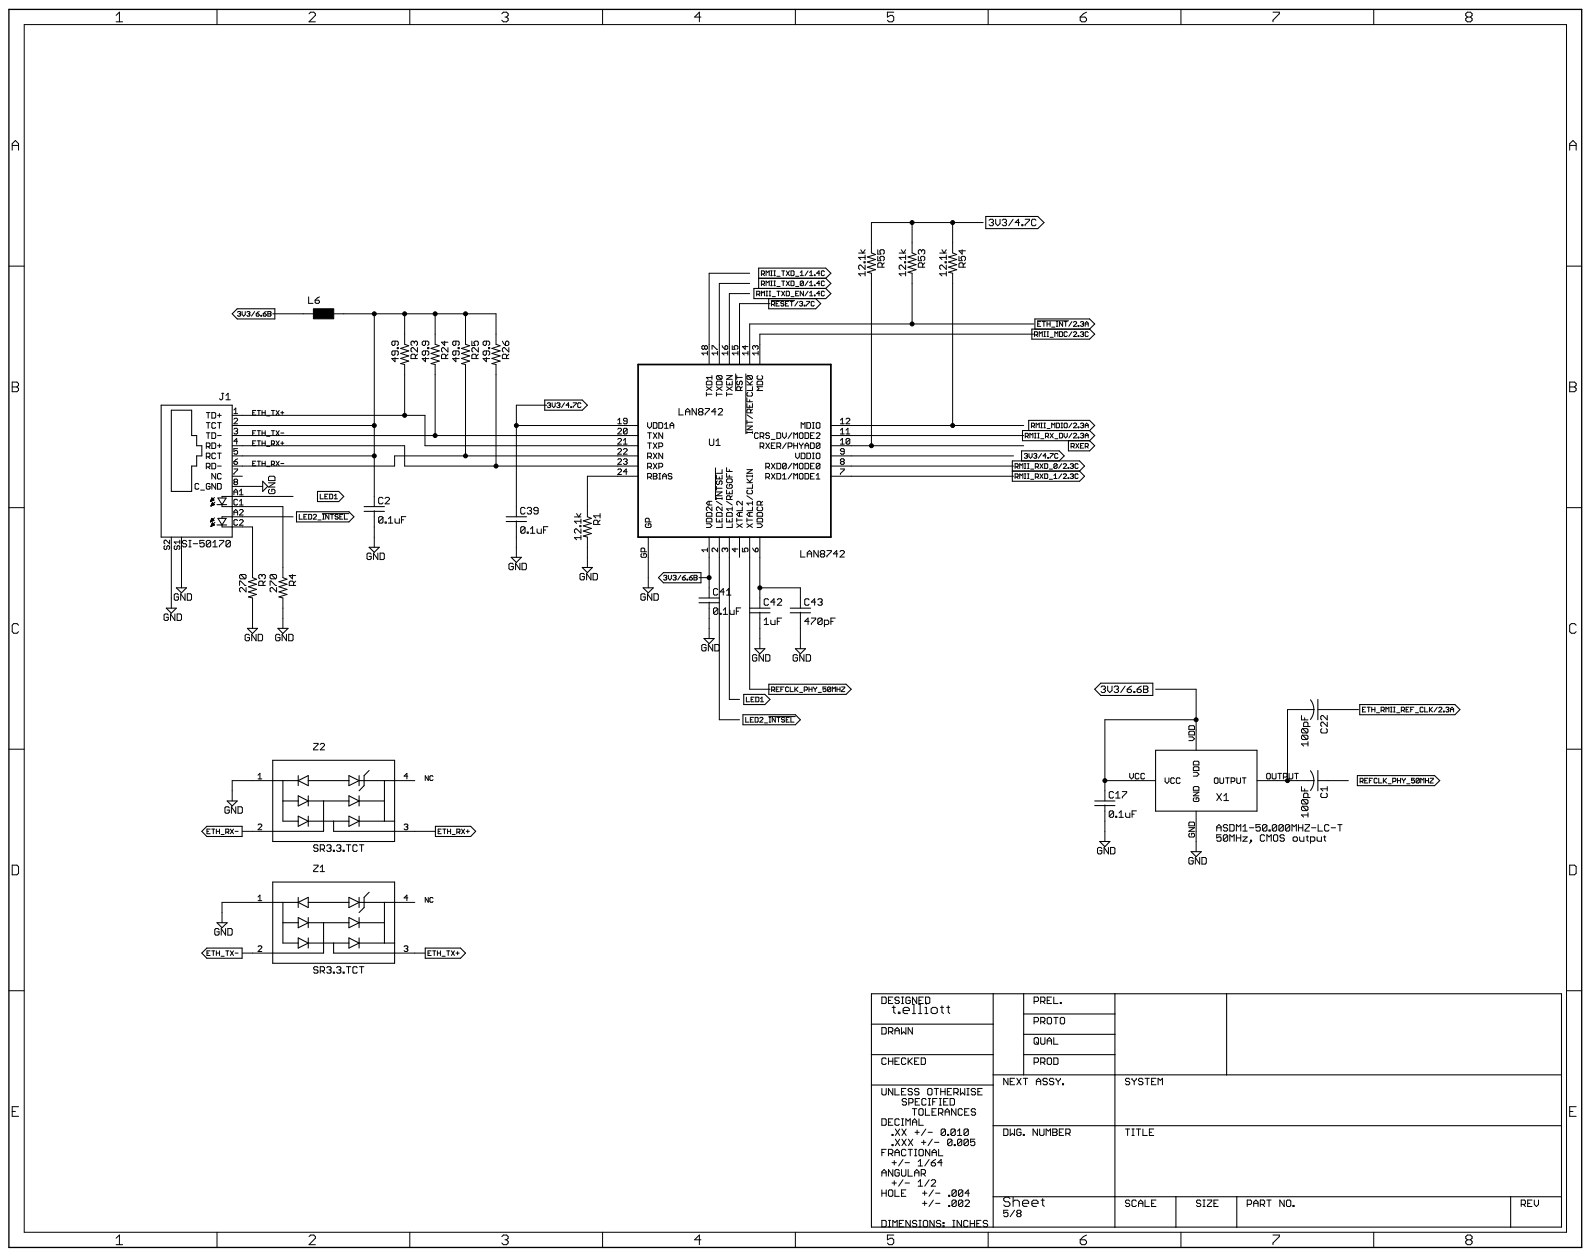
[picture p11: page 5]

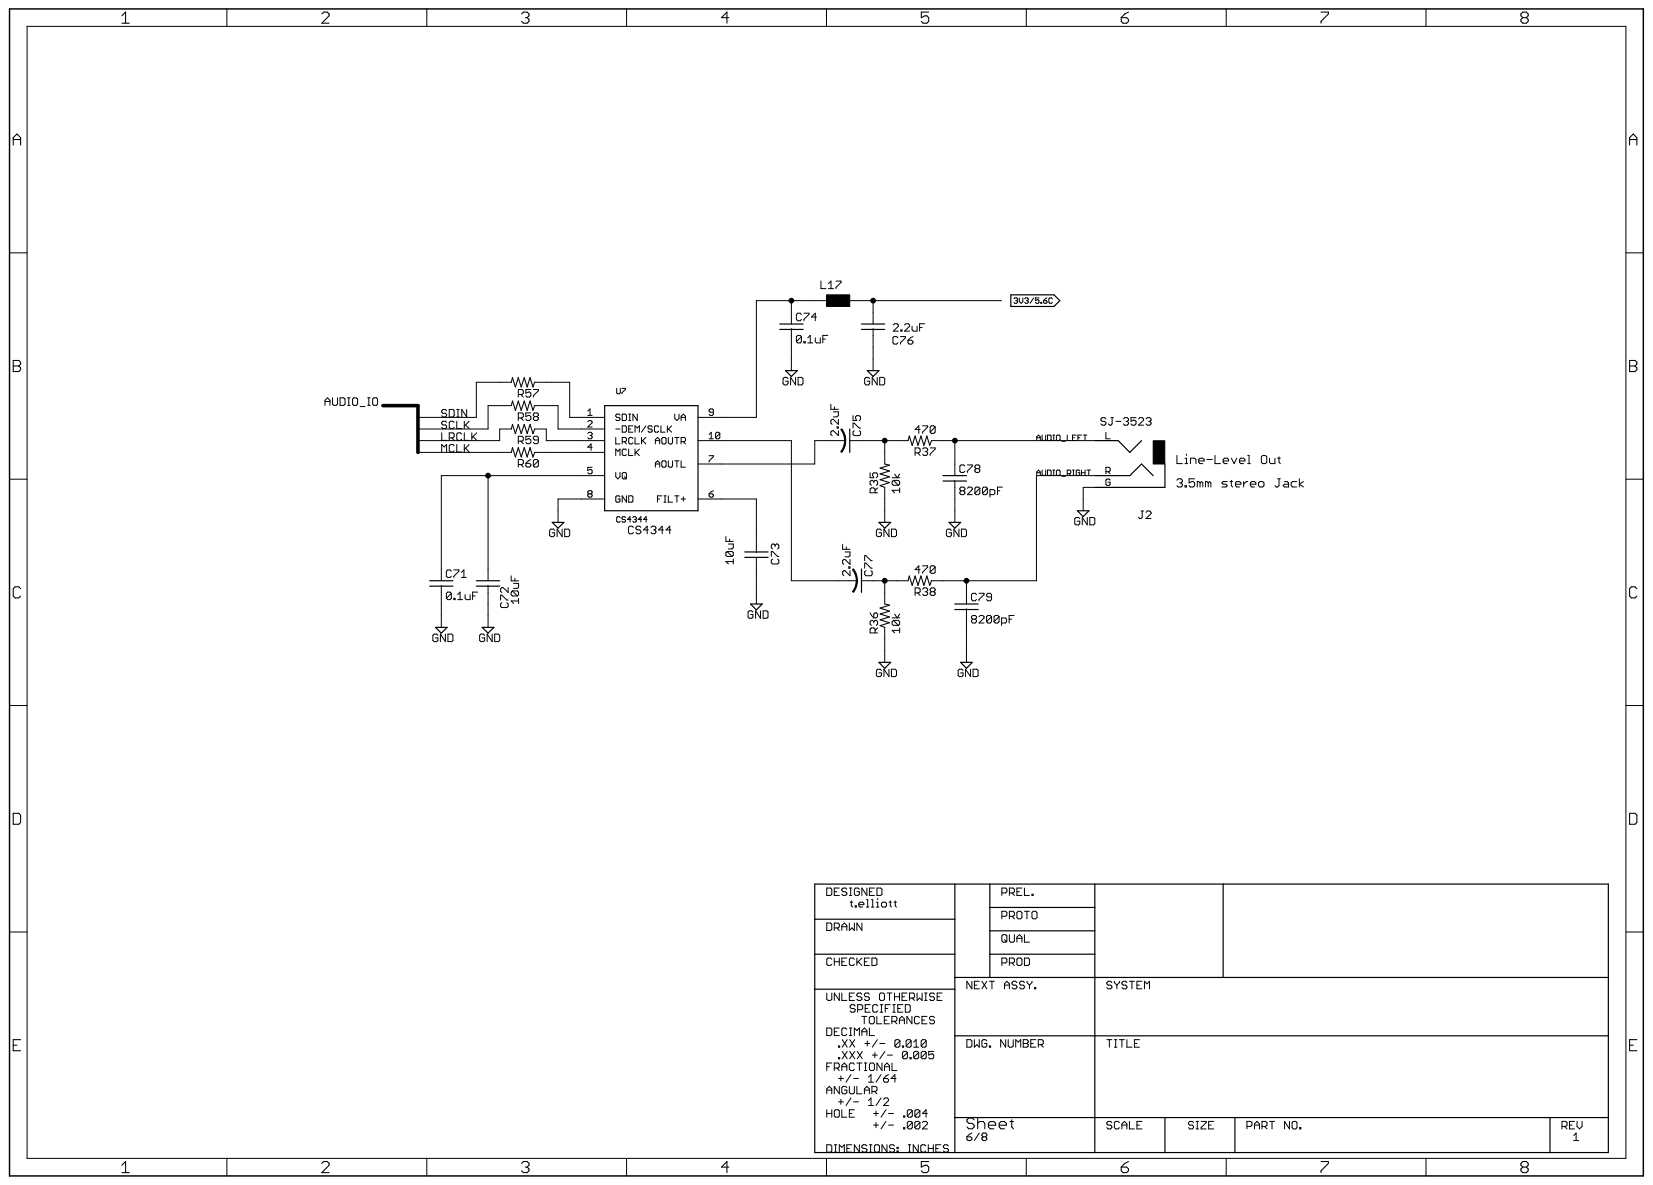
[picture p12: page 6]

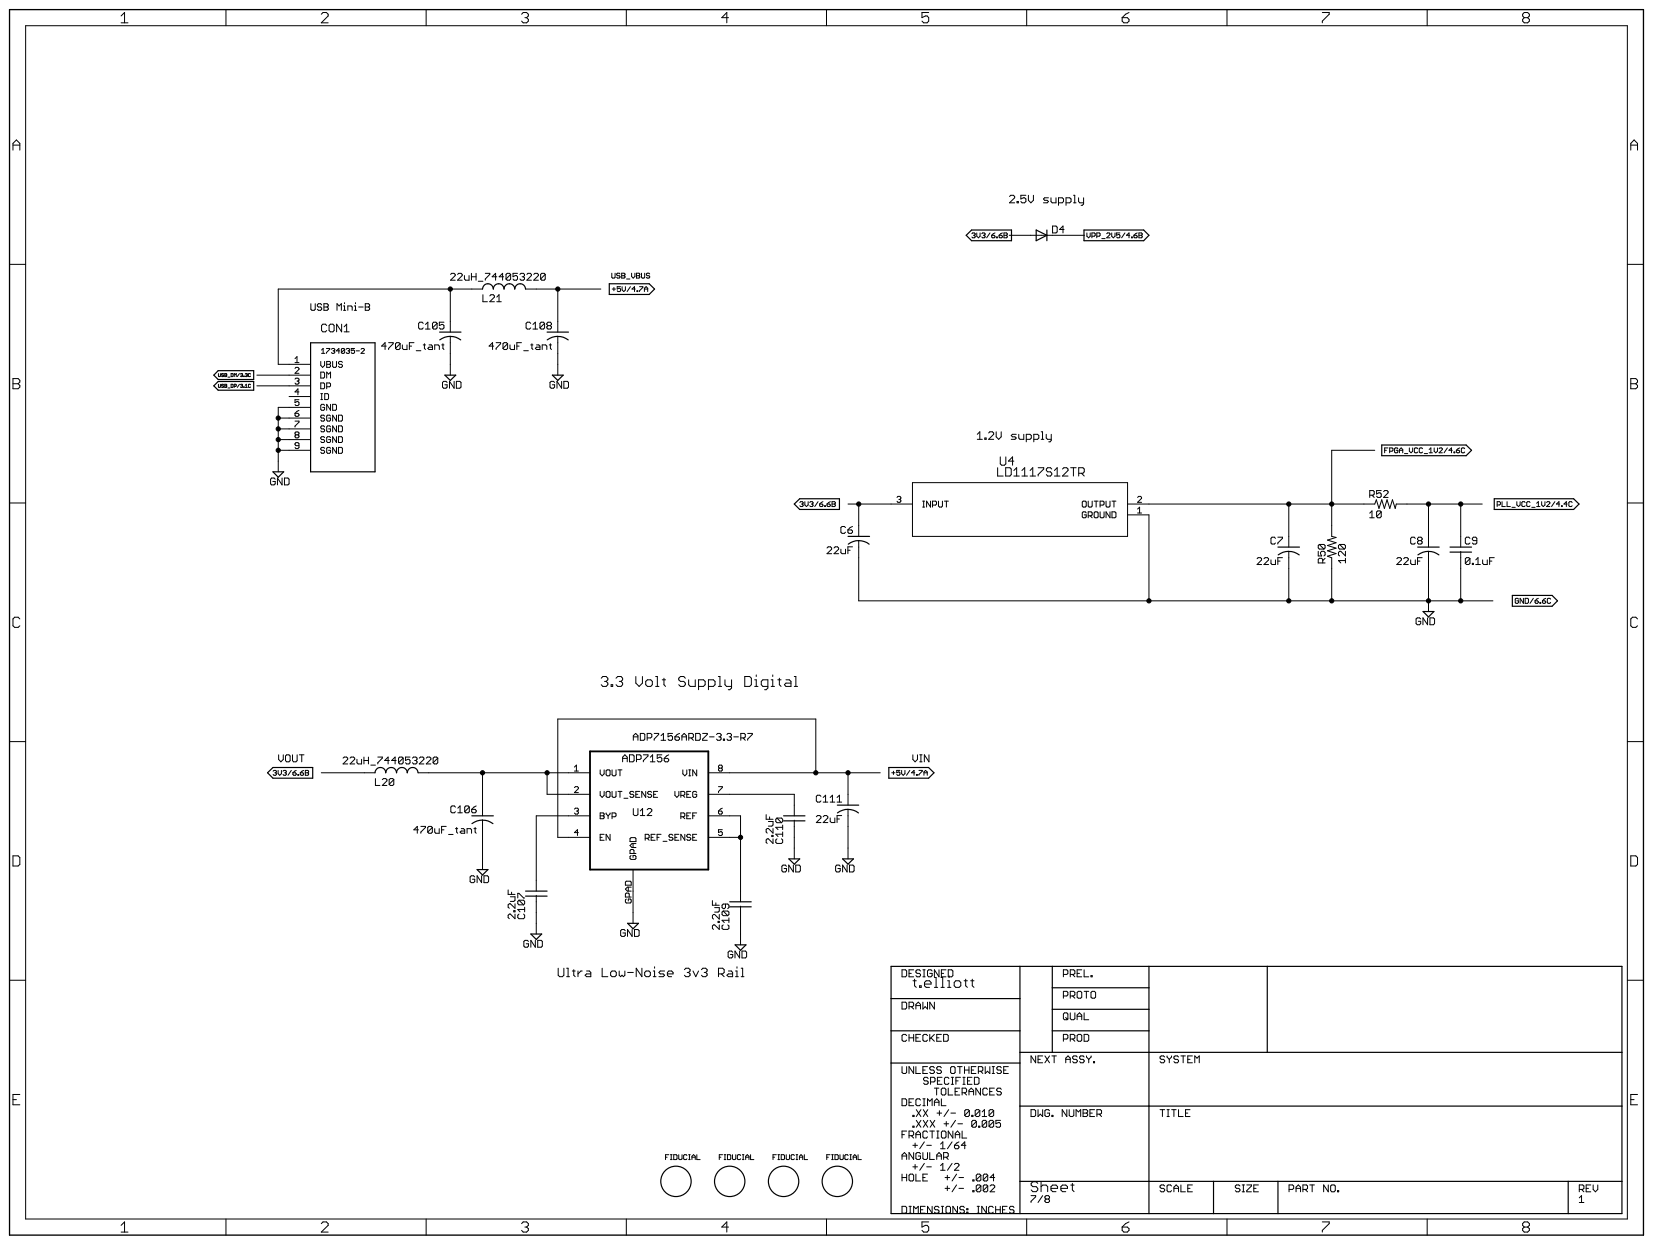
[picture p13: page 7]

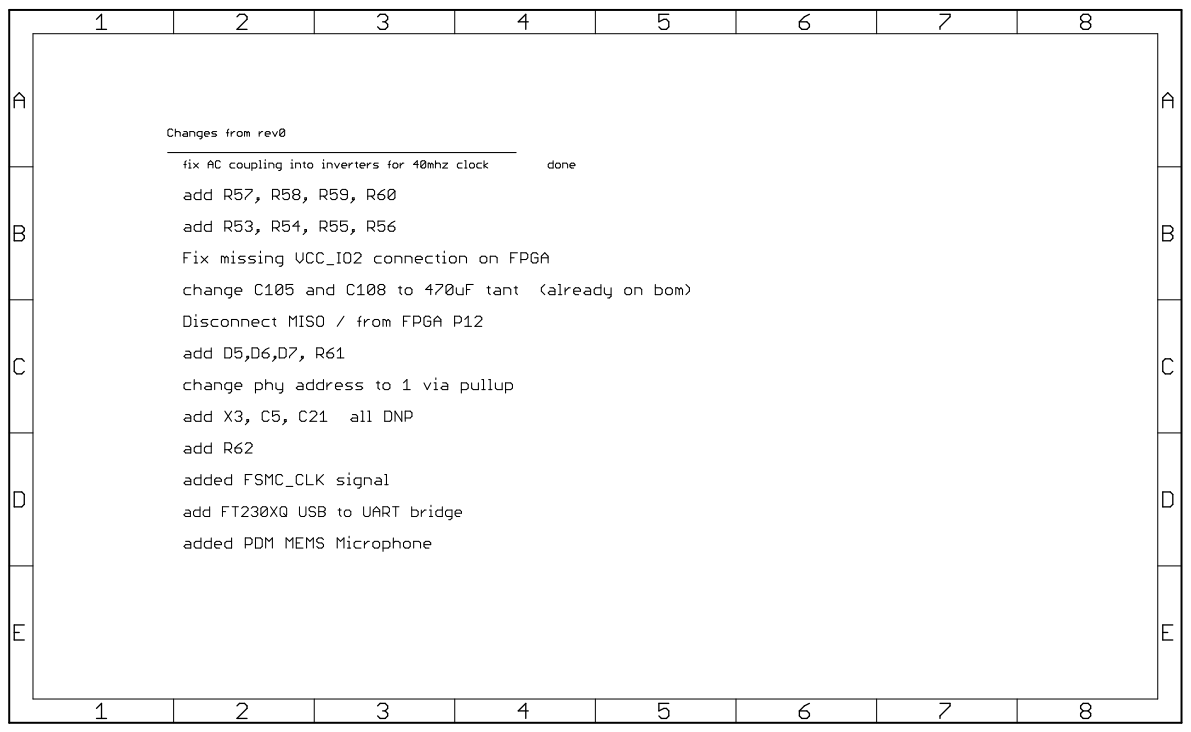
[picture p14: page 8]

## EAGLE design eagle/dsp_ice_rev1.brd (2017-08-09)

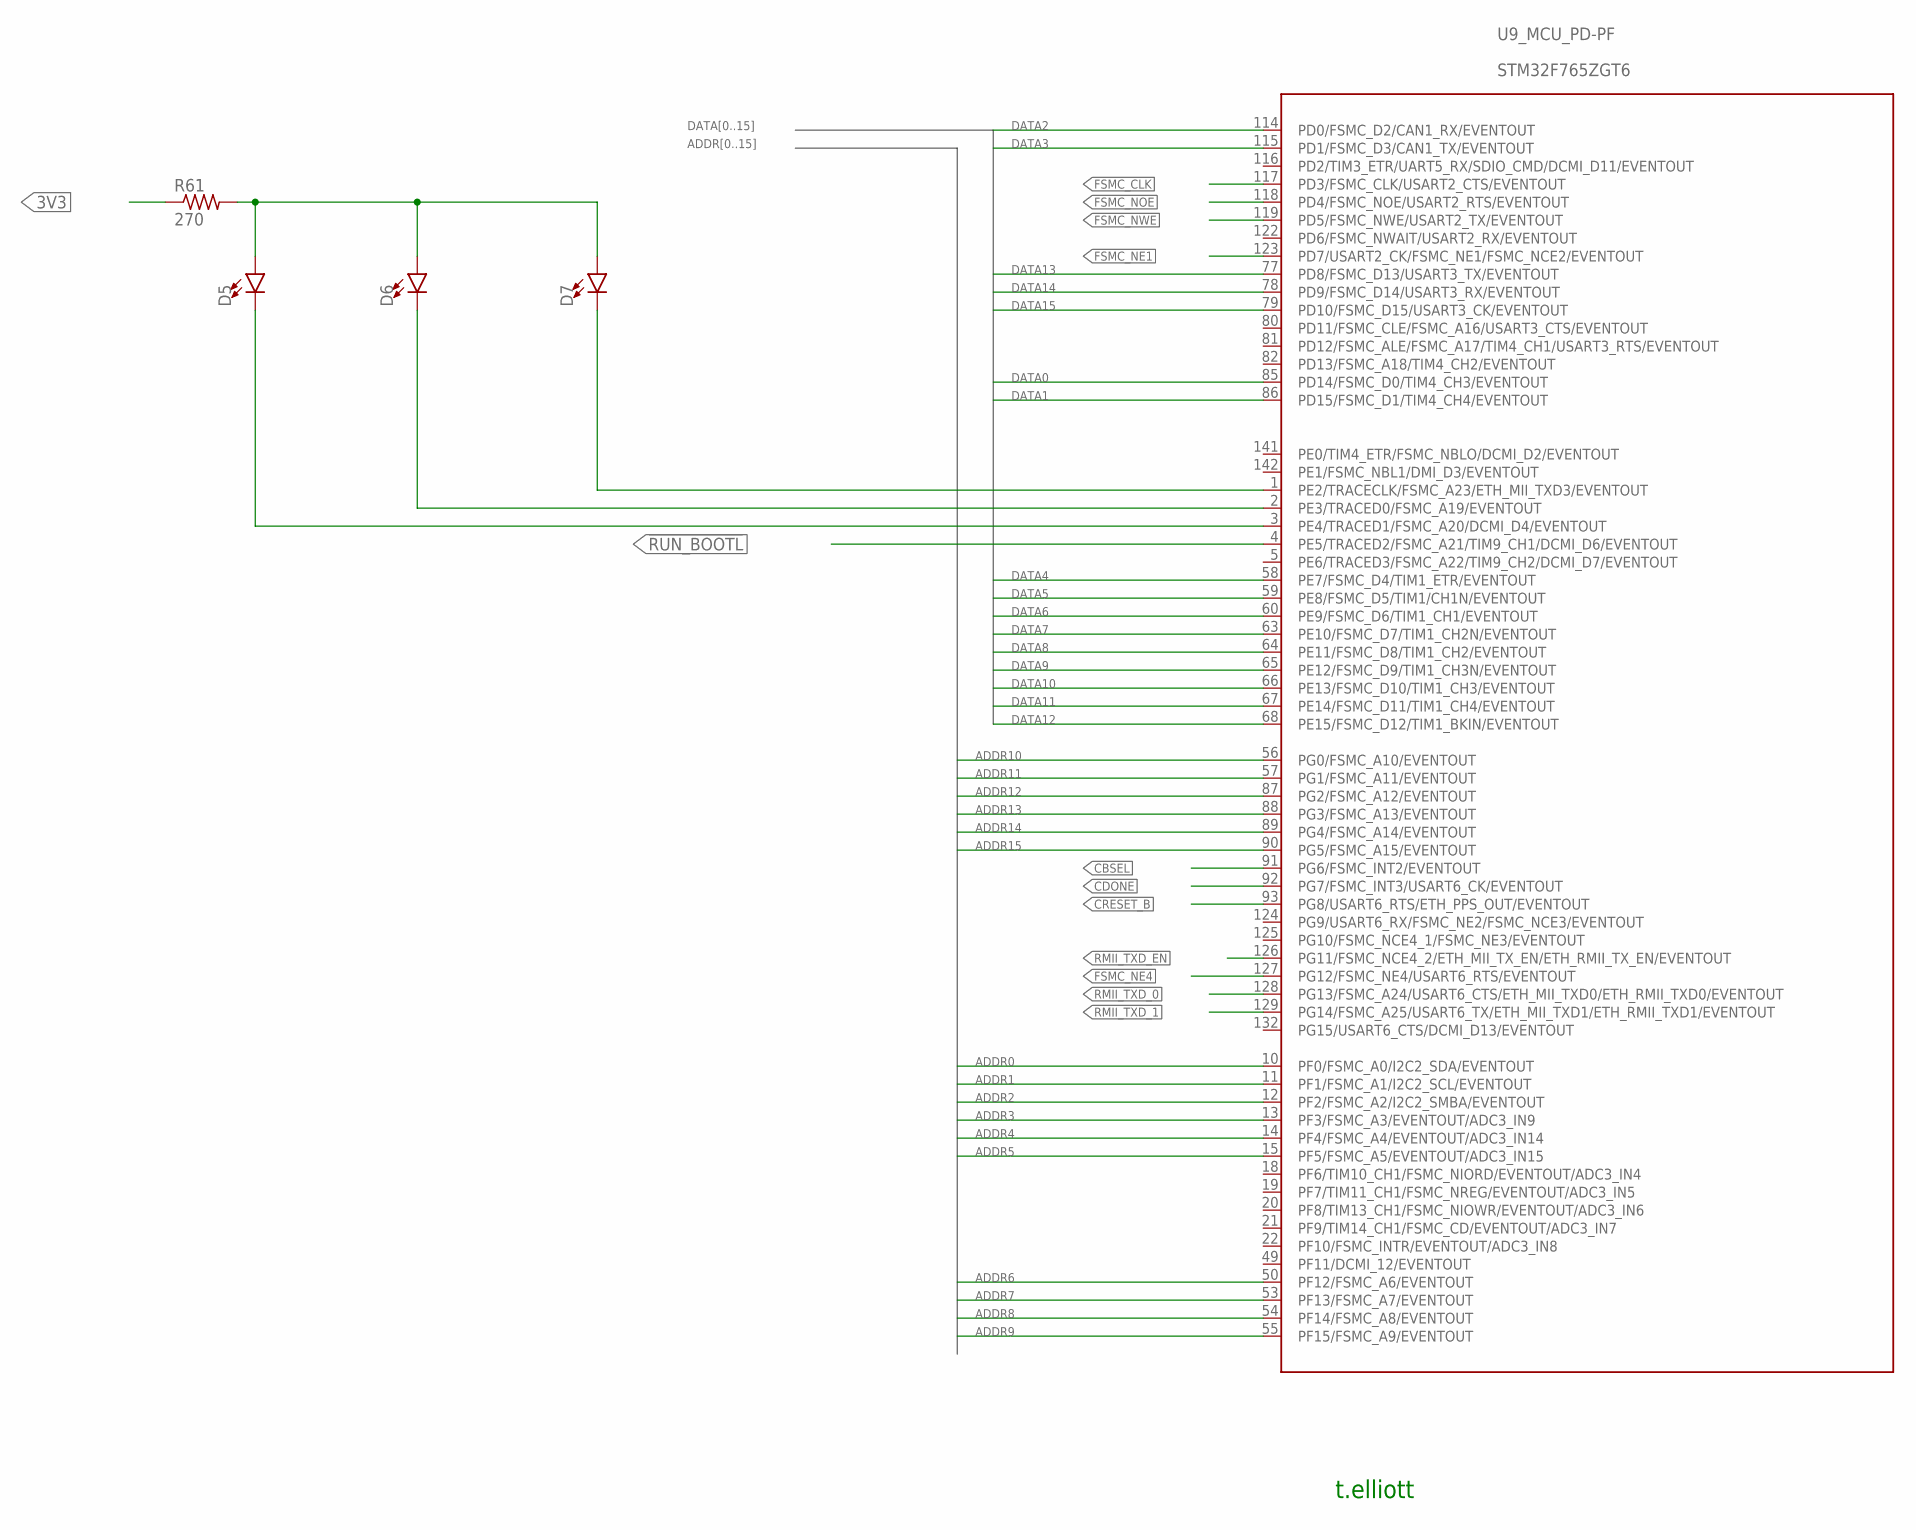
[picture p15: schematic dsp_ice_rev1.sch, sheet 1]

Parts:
D5, D6, D7: LED1206; LED-1206
R61: 270; R0603
U9: STM32F765ZGT6; STM32F407_144

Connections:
3V3: R61.1; also elsewhere on the board
!RUN_BOOTL: U9.4 (PE5/TRACED2/FSMC_A21/TIM9_CH1/DCMI_D6/E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); also elsewhere on the board
ADDR0: U9.10 (PF0/FSMC_A0/I2C2_SDA/EVENTOUT); also elsewhere on the board
ADDR1: U9.11 (PF1/FSMC_A1/I2C2_SCL/EVENTOUT); also elsewhere on the board
ADDR2: U9.12 (PF2/FSMC_A2/I2C2_SMBA/EVENTOUT); also elsewhere on the board
ADDR3: U9.13 (PF3/FSMC_A3/EVENTOUT/ADC3_IN9); also elsewhere on the board
ADDR4: U9.14 (PF4/FSMC_A4/EVENTOUT/ADC3_IN14); also elsewhere on the board
ADDR5: U9.15 (PF5/FSMC_A5/EVENTOUT/ADC3_IN15); also elsewhere on the board
ADDR6: U9.50 (PF12/FSMC_A6/EVENTOUT); also elsewhere on the board
ADDR7: U9.53 (PF13/FSMC_A7/EVENTOUT); also elsewhere on the board
ADDR8: U9.54 (PF14/FSMC_A8/EVENTOUT); also elsewhere on the board
ADDR9: U9.55 (PF15/FSMC_A9/EVENTOUT); also elsewhere on the board
ADDR10: U9.56 (PG0/FSMC_A10/EVENTOUT); also elsewhere on the board
ADDR11: U9.57 (PG1/FSMC_A11/EVENTOUT); also elsewhere on the board
ADDR12: U9.87 (PG2/FSMC_A12/EVENTOUT); also elsewhere on the board
ADDR13: U9.88 (PG3/FSMC_A13/EVENTOUT); also elsewhere on the board
ADDR14: U9.89 (PG4/FSMC_A14/EVENTOUT); also elsewhere on the board
ADDR15: U9.90 (PG5/FSMC_A15/EVENTOUT); also elsewhere on the board
CBSEL: U9.91 (PG6/FSMC_INT2/EVENTOUT); also elsewhere on the board
CDONE: U9.92 (PG7/FSMC_INT3/USART6_CK/EVENTOUT); also elsewhere on the board
CRESET_B: U9.93 (PG8/USART6_RTS/ETH_PPS_OUT/EVENTOUT); also elsewhere on the board
DATA0: U9.85 (PD14/FSMC_D0/TIM4_CH3/EVENTOUT); also elsewhere on the board
DATA1: U9.86 (PD15/FSMC_D1/TIM4_CH4/EVENTOUT); also elsewhere on the board
DATA2: U9.114 (PD0/FSMC_D2/CAN1_RX/EVENTOUT); also elsewhere on the board
DATA3: U9.115 (PD1/FSMC_D3/CAN1_TX/EVENTOUT); also elsewhere on the board
DATA4: U9.58 (PE7/FSMC_D4/TIM1_ETR/EVENTOUT); also elsewhere on the board
DATA5: U9.59 (PE8/FSMC_D5/TIM1/CH1N/EVENTOUT); also elsewhere on the board
DATA6: U9.60 (PE9/FSMC_D6/TIM1_CH1/EVENTOUT); also elsewhere on the board
DATA7: U9.63 (PE10/FSMC_D7/TIM1_CH2N/EVENTOUT); also elsewhere on the board
DATA8: U9.64 (PE11/FSMC_D8/TIM1_CH2/EVENTOUT); also elsewhere on the board
DATA9: U9.65 (PE12/FSMC_D9/TIM1_CH3N/EVENTOUT); also elsewhere on the board
DATA10: U9.66 (PE13/FSMC_D10/TIM1_CH3/EVENTOUT); also elsewhere on the board
DATA11: U9.67 (PE14/FSMC_D11/TIM1_CH4/EVENTOUT); also elsewhere on the board
DATA12: U9.68 (PE15/FSMC_D12/TIM1_BKIN/EVENTOUT); also elsewhere on the board
DATA13: U9.77 (PD8/FSMC_D13/USART3_TX/EVENTOUT); also elsewhere on the board
DATA14: U9.78 (PD9/FSMC_D14/USART3_RX/EVENTOUT); also elsewhere on the board
DATA15: U9.79 (PD10/FSMC_D15/USART3_CK/EVENTOUT); also elsewhere on the board
FSMC_CLK: U9.117 (PD3/FSMC_CLK/USART2_CTS/EVENTOUT); also elsewhere on the board
FSMC_NE1: U9.123 (PD7/USART2_CK/FSMC_NE1/FSMC_NCE2/EVENTO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); also elsewhere on the board
FSMC_NE4: U9.127 (PG12/FSMC_NE4/USART6_RTS/EVENTOUT); also elsewhere on the board
FSMC_NOE: U9.118 (PD4/FSMC_NOE/USART2_RTS/EVENTOUT); also elsewhere on the board
FSMC_NWE: U9.119 (PD5/FSMC_NWE/USART2_TX/EVENTOUT); also elsewhere on the board
unnamed: D5.A, D6.A, D7.A, R61.2
unnamed: D7.C, U9.1 (PE2/TRACECLK/FSMC_A23/ETH_MII_TXD3/EVEN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)
unnamed: D6.C, U9.2 (PE3/TRACED0/FSMC_A19/EVENTOUT)
unnamed: D5.C, U9.3 (PE4/TRACED1/FSMC_A20/DCMI_D4/EVENTOUT)
RMII_TXD_0: U9.128 (PG13/FSMC_A24/USART6_CTS/ETH_MII_TXD0/E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); also elsewhere on the board
RMII_TXD_1: U9.129 (PG14/FSMC_A25/USART6_TX/ETH_MII_TXD1/ET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); also elsewhere on the board
RMII_TXD_EN: U9.126 (PG11/FSMC_NCE4_2/ETH_MII_TX_EN/ETH_RMII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); also elsewhere on the board

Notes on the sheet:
t.elliott

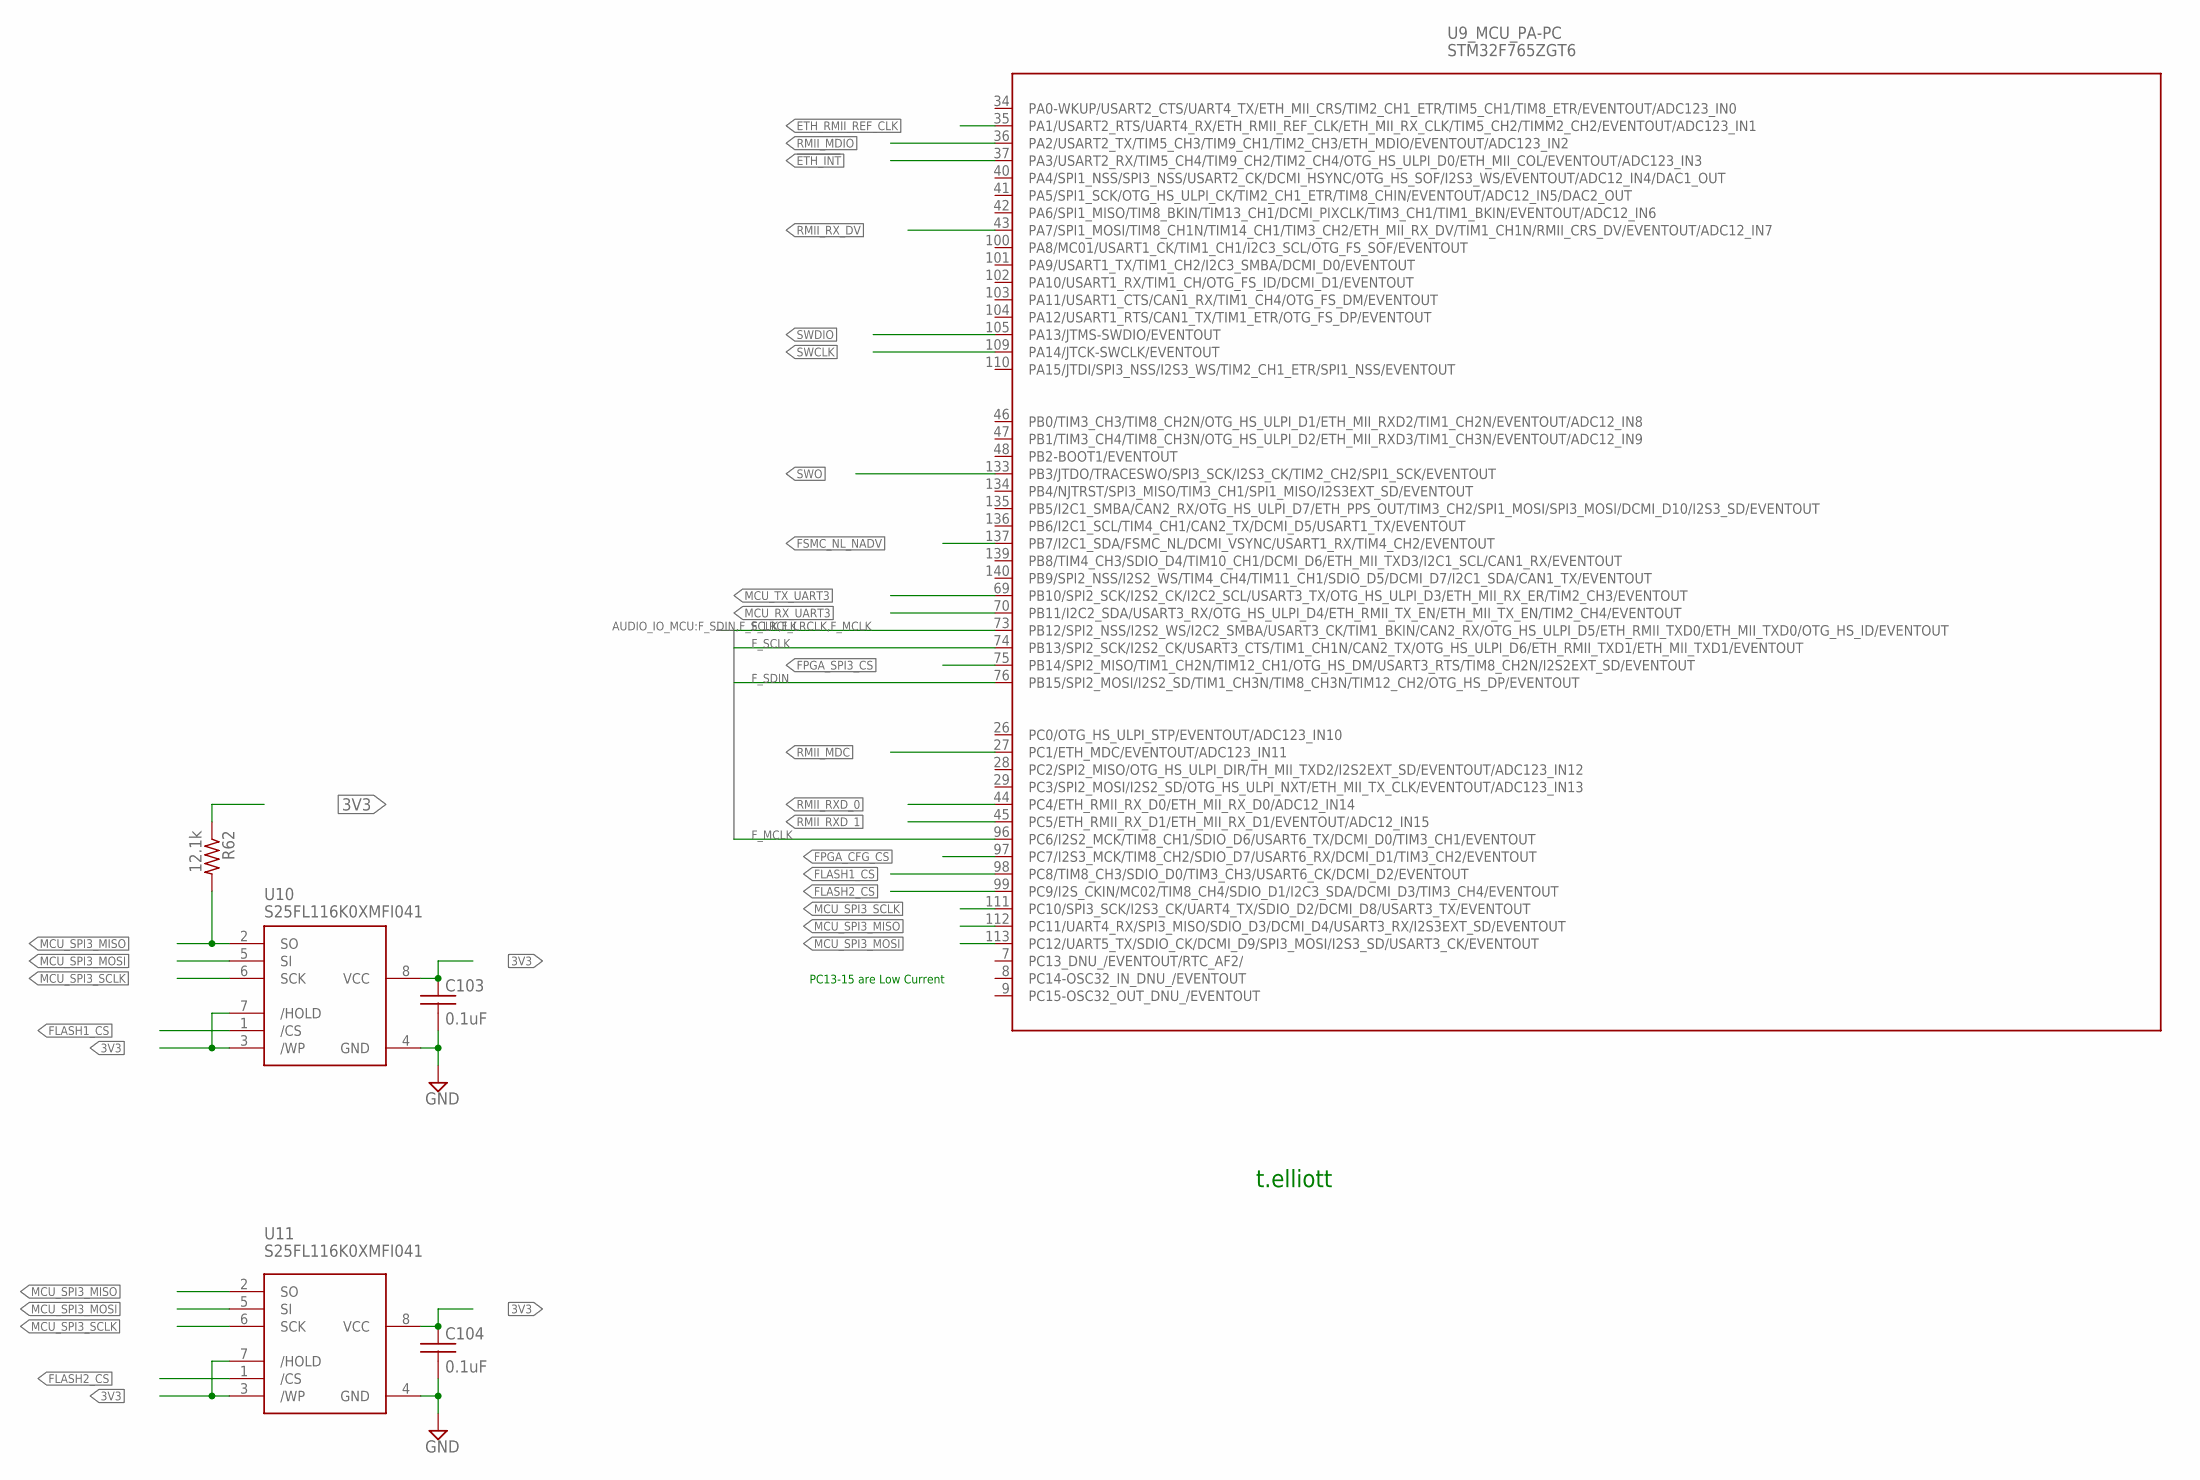
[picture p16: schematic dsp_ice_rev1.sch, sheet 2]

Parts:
C103, C104: 0.1uF; C0603
R62: 12.1k; R0603
U9: STM32F765ZGT6; STM32F407_144
U10, U11: S25FL116K0XMFI041; SO8

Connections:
3V3: C103.1, C104.1, R62.1, U10.3 (/WP), U10.7 (/HOLD), U10.8 (VCC), U11.3 (/WP), U11.7 (/HOLD), U11.8 (VCC); also elsewhere on the board
!ETH_INT: U9.37 (PA3/USART2_RX/TIM5_CH4/TIM9_CH2/TIM2_CH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); also elsewhere on the board
ETH_RMII_REF_CLK: U9.35 (PA1/USART2_RTS/UART4_RX/ETH_RMII_REF_CL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); also elsewhere on the board
FLASH1_CS: U9.98 (PC8/TIM8_CH3/SDIO_D0/TIM3_CH3/USART6_CK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), U10.1 (/CS)
FLASH2_CS: U9.99 (PC9/I2S_CKIN/MC02/TIM8_CH4/SDIO_D1/I2C3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), U11.1 (/CS)
FPGA_CFG_CS: U9.97 (PC7/I2S3_MCK/TIM8_CH2/SDIO_D7/USART6_RX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); also elsewhere on the board
FPGA_SPI3_CS: U9.75 (PB14/SPI2_MISO/TIM1_CH2N/TIM12_CH1/OTG_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); also elsewhere on the board
FSMC_NL_NADV: U9.137 (PB7/I2C1_SDA/FSMC_NL/DCMI_VSYNC/USART1_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); also elsewhere on the board
F_LRCLK: U9.73 (PB12/SPI2_NSS/I2S2_WS/I2C2_SMBA/USART3_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); also elsewhere on the board
F_MCLK: U9.96 (PC6/I2S2_MCK/TIM8_CH1/SDIO_D6/USART6_TX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); also elsewhere on the board
F_SCLK: U9.74 (PB13/SPI2_SCK/I2S2_CK/USART3_CTS/TIM1_C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); also elsewhere on the board
F_SDIN: U9.76 (PB15/SPI2_MOSI/I2S2_SD/TIM1_CH3N/TIM8_C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); also elsewhere on the board
GND: C103.2, C104.2, U10.4 (GND), U11.4 (GND); also elsewhere on the board
MCU_RX_UART3: U9.70 (PB11/I2C2_SDA/USART3_RX/OTG_HS_ULPI_D4/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); also elsewhere on the board
MCU_SPI3_MISO: R62.2, U9.112 (PC11/UART4_RX/SPI3_MISO/SDIO_D3/DCMI_D4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), U10.2 (SO), U11.2 (SO); also elsewhere on the board
MCU_SPI3_MOSI: U9.113 (PC12/UART5_TX/SDIO_CK/DCMI_D9/SPI3_MOSI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), U10.5 (SI), U11.5 (SI); also elsewhere on the board
MCU_SPI3_SCLK: U9.111 (PC10/SPI3_SCK/I2S3_CK/UART4_TX/SDIO_D2/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), U10.6 (SCK), U11.6 (SCK); also elsewhere on the board
MCU_TX_UART3: U9.69 (PB10/SPI2_SCK/I2S2_CK/I2C2_SCL/USART3_T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); also elsewhere on the board
RMII_MDC: U9.27 (PC1/ETH_MDC/EVENTOUT/ADC123_IN11); also elsewhere on the board
RMII_MDIO: U9.36 (PA2/USART2_TX/TIM5_CH3/TIM9_CH1/TIM2_CH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); also elsewhere on the board
RMII_RXD_0: U9.44 (PC4/ETH_RMII_RX_D0/ETH_MII_RX_D0/ADC12_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); also elsewhere on the board
RMII_RXD_1: U9.45 (PC5/ETH_RMII_RX_D1/ETH_MII_RX_D1/EVENTO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); also elsewhere on the board
RMII_RX_DV: U9.43 (PA7/SPI1_MOSI/TIM8_CH1N/TIM14_CH1/TIM3_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); also elsewhere on the board
SWCLK: U9.109 (PA14/JTCK-SWCLK/EVENTOUT); also elsewhere on the board
SWDIO: U9.105 (PA13/JTMS-SWDIO/EVENTOUT); also elsewhere on the board
SWO: U9.133 (PB3/JTDO/TRACESWO/SPI3_SCK/I2S3_CK/TIM2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); also elsewhere on the board

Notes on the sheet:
PC13-15 are Low Current
t.elliott

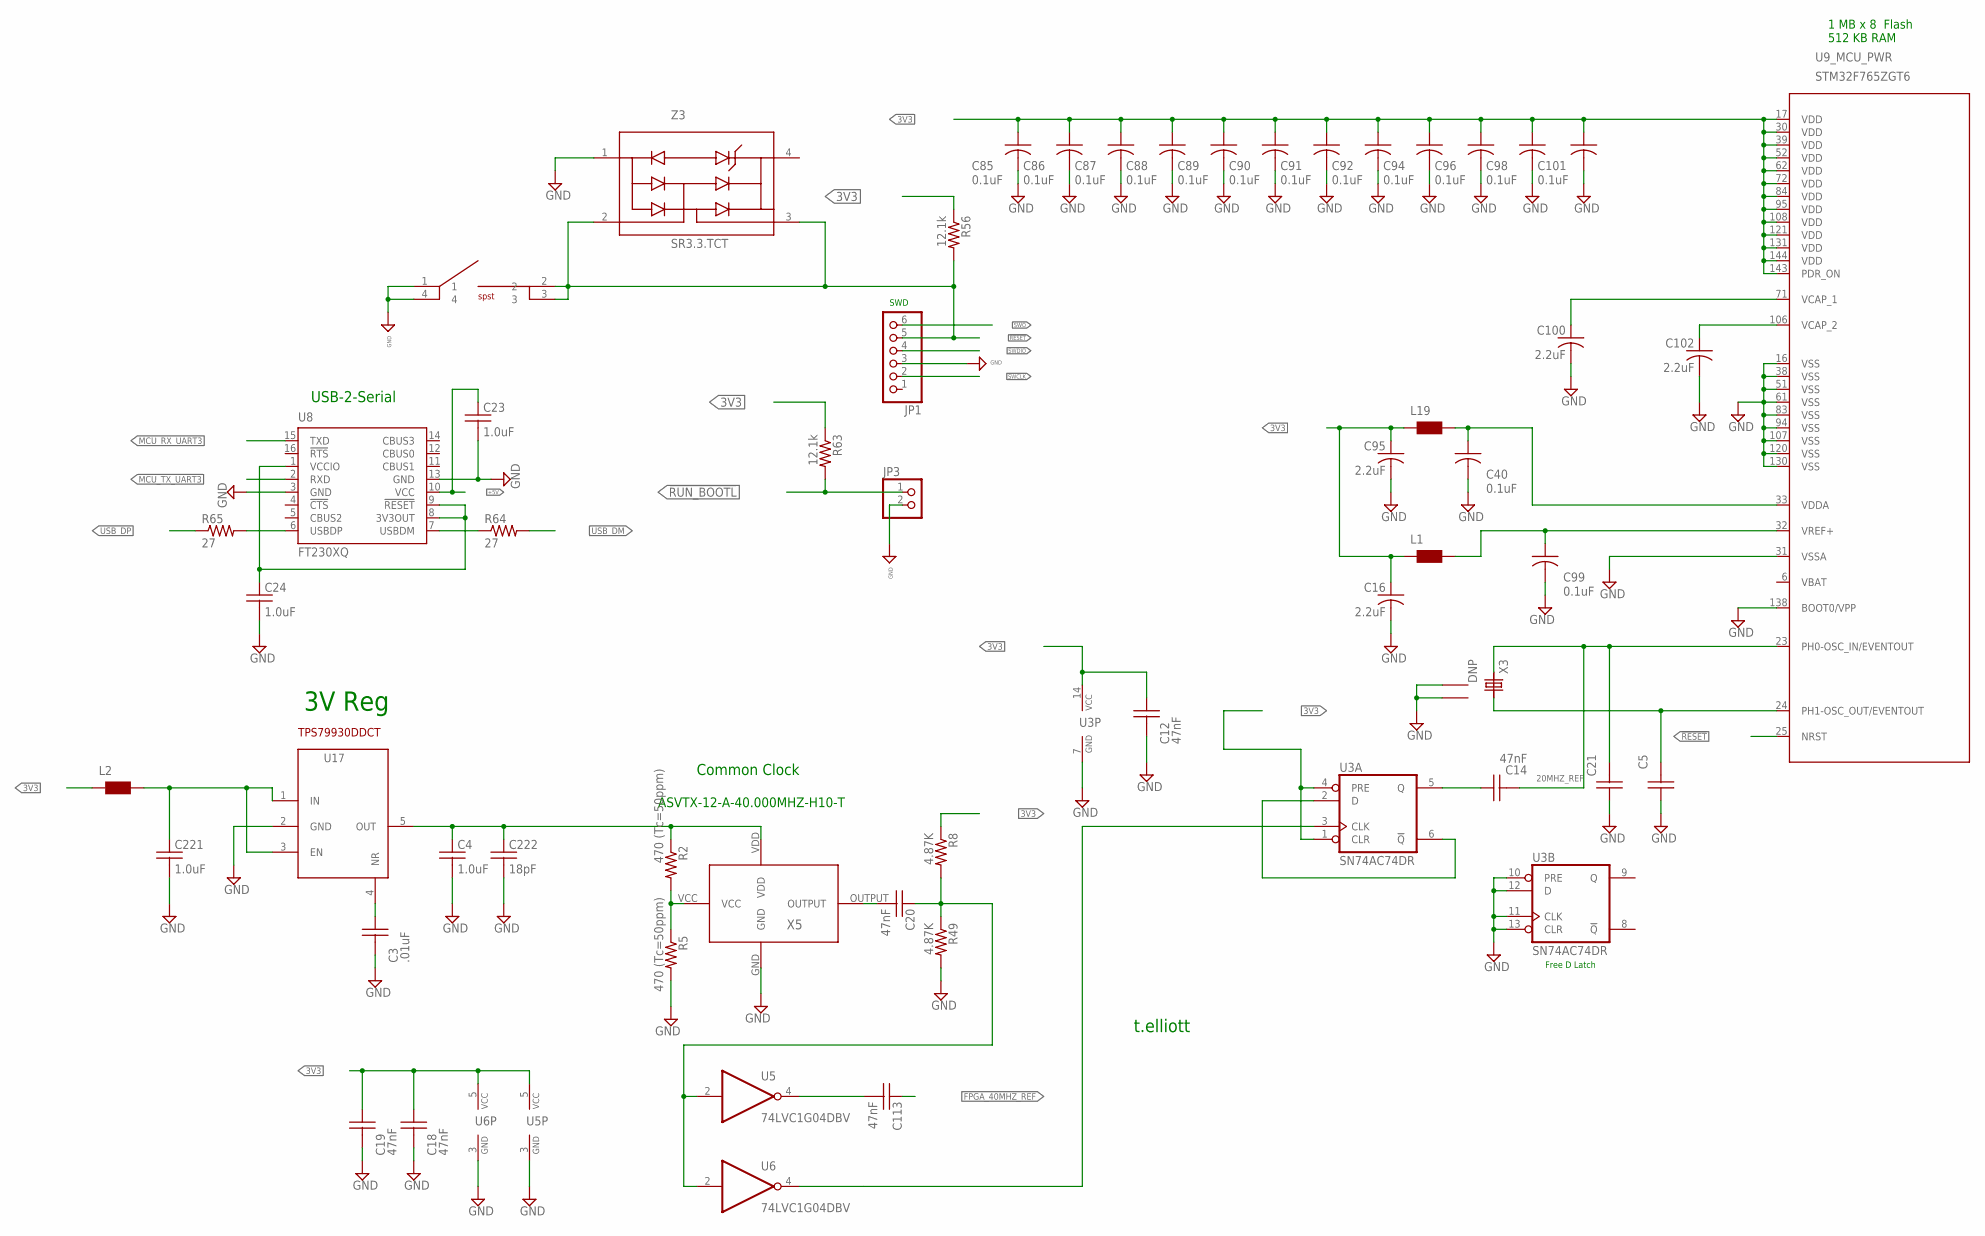
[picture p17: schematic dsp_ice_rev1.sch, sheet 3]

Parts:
C3: .01uF; C0402
C4, C23, C24, C221: 1.0uF; C0402
C5, C21: C-USC0402; C0402
C12, C14, C18, C19, C20, C113: 47nF; C0402
C16, C95, C100, C102: 2.2uF; C0805
C40, C85, C86, C87, C88, C89, C90, C91, C92, C94, C96, C98, C99, C101: 0.1uF; 0402
C222: 18pF; C0402
JP1: PINHD-1X6; 1X06
JP3: PINHD-1X2; 1X02
L1, L19: WE-CBF_0603; 0603
L2: WE-CBF_0402; 0402
R2, R5: 470 (Tc=50ppm); R0402
R8, R49: 4.87K; R0603
R56, R63: 12.1k; R0603
R64, R65: 27; R0603
SW3: HOKURIKU_KSM06_6X6MM_SWITCH1; TACTILE_6X6MM
U3: SN74AC74DR; SO14
U5, U6: 74LVC1G04DBV; SOT23-5
U8: FT230XQ; QFN16
U9: STM32F765ZGT6; STM32F407_144
U17: TPS799X; SOT23-6
X3: DNP; ECS-250-20-30B-DU_CRYSTAL
X5: ASVTX-12-A-40.000MHZ-H10-T; CRYSTAL_2.5_2MM
Z3: SR3.3.TCT; SR2.8.TCT_1PRIMARY

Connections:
3V: C4.1, C222.1, R2.1, U17.5 (OUT), X5.VDD
3V3: C12.1, C16.1, C18.1, C19.1, C85.1 (A), C86.1 (A), C87.1 (A), C88.1 (A), C89.1 (A), C90.1 (A), C91.1 (A), C92.1 (A), C94.1 (A), C95.1, C96.1 (A), C98.1 (A), C101.1 (A), L1.1, L2.1, L19.1, R8.1, R56.1, R63.1, U3.1 (CLR), U3.4 (PRE), U3.14 (VCC), U5.5 (VCC), U6.5 (VCC), U9.17 (VDD), U9.30 (VDD), U9.39 (VDD), U9.52 (VDD), U9.62 (VDD), U9.72 (VDD), U9.84 (VDD), U9.95 (VDD), U9.108 (VDD), U9.121 (VDD), U9.131 (VDD), U9.143 (PDR_ON), U9.144 (VDD); also elsewhere on the board
3V_ANALOG: C99.1 (A), L1.2, U9.32 (VREF+)
20MHZ_REF: C14.2, C21.2, U9.23 (PH0-OSC_IN/EVENTOUT), X3.1
!RESET: JP1.5, R56.2, SW3.2, SW3.3, U9.25 (NRST), Z3.2 (I/O), Z3.3 (I/O); also elsewhere on the board
!RUN_BOOTL: JP3.1, R63.2; also elsewhere on the board
+5V: C23.1, U8.10 (VCC); also elsewhere on the board
FPGA_40MHZ_REF: C113.1; also elsewhere on the board
GND: C3.2, C4.2, C5.1, C12.2, C16.2, C18.2, C19.2, C21.1, C23.2, C24.2, C40.2 (C), C85.2 (C), C86.2 (C), C87.2 (C), C88.2 (C), C89.2 (C), C90.2 (C), C91.2 (C), C92.2 (C), C94.2 (C), C95.2, C96.2 (C), C98.2 (C), C99.2 (C), C100.2, C101.2 (C), C102.2, C221.2, C222.2, JP1.3, JP3.2, R5.2, R49.2, SW3.1, SW3.4, U3.7 (GND), U3.10 (PRE), U3.11 (CLK), U3.12 (D), U3.13 (CLR), U5.3 (GND), U6.3 (GND), U8.3 (GND), U8.13 (GND), U9.16 (VSS), U9.31 (VSSA), U9.38 (VSS), U9.51 (VSS), U9.61 (VSS), U9.83 (VSS), U9.94 (VSS), U9.107 (VSS), U9.120 (VSS), U9.130 (VSS), U9.138 (BOOT0/VPP), U17.2 (GND), X3.GND@1 (1), X3.GND@2 (2), X5.GND, Z3.1 (GND); also elsewhere on the board
MCU_RX_UART3: U8.15 (TXD); also elsewhere on the board
MCU_TX_UART3: U8.2 (RXD); also elsewhere on the board
unnamed: R2.2, R5.1, X5.VCC
unnamed: C221.1, L2.2, U17.1 (IN), U17.3 (EN)
unnamed: U3.2 (D), U3.6 (!Q)
unnamed: C20.2, X5.OUTPUT
unnamed: C113.2, U5.4 (O)
unnamed: U3.3 (CLK), U6.4 (O)
unnamed: C20.1, R8.2, R49.1, U5.2 (I), U6.2 (I)
unnamed: C102.1, U9.106 (VCAP_2)
unnamed: C24.1, U8.1 (VCCIO), U8.8 (3V3OUT), U8.9 (!RESET)
unnamed: C100.1, U9.71 (VCAP_1)
unnamed: C5.2, U9.24 (PH1-OSC_OUT/EVENTOUT), X3.3
unnamed: R64.1, U8.7 (USBDM)
unnamed: R65.2, U8.6 (USBDP)
unnamed: C3.1, U17.4 (NR)
unnamed: C40.1 (A), L19.2, U9.33 (VDDA)
unnamed: C14.1, U3.5 (Q)
SWCLK: JP1.2; also elsewhere on the board
SWDIO: JP1.4; also elsewhere on the board
SWO: JP1.6; also elsewhere on the board
USB_DM: R64.2; also elsewhere on the board
USB_DP: R65.1; also elsewhere on the board

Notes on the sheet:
t.elliott
1 MB x 8 Flash 512 KB RAM
ASVTX-12-A-40.000MHZ-H10-T
3V Reg
SWD
Free D Latch
Common Clock
USB-2-Serial

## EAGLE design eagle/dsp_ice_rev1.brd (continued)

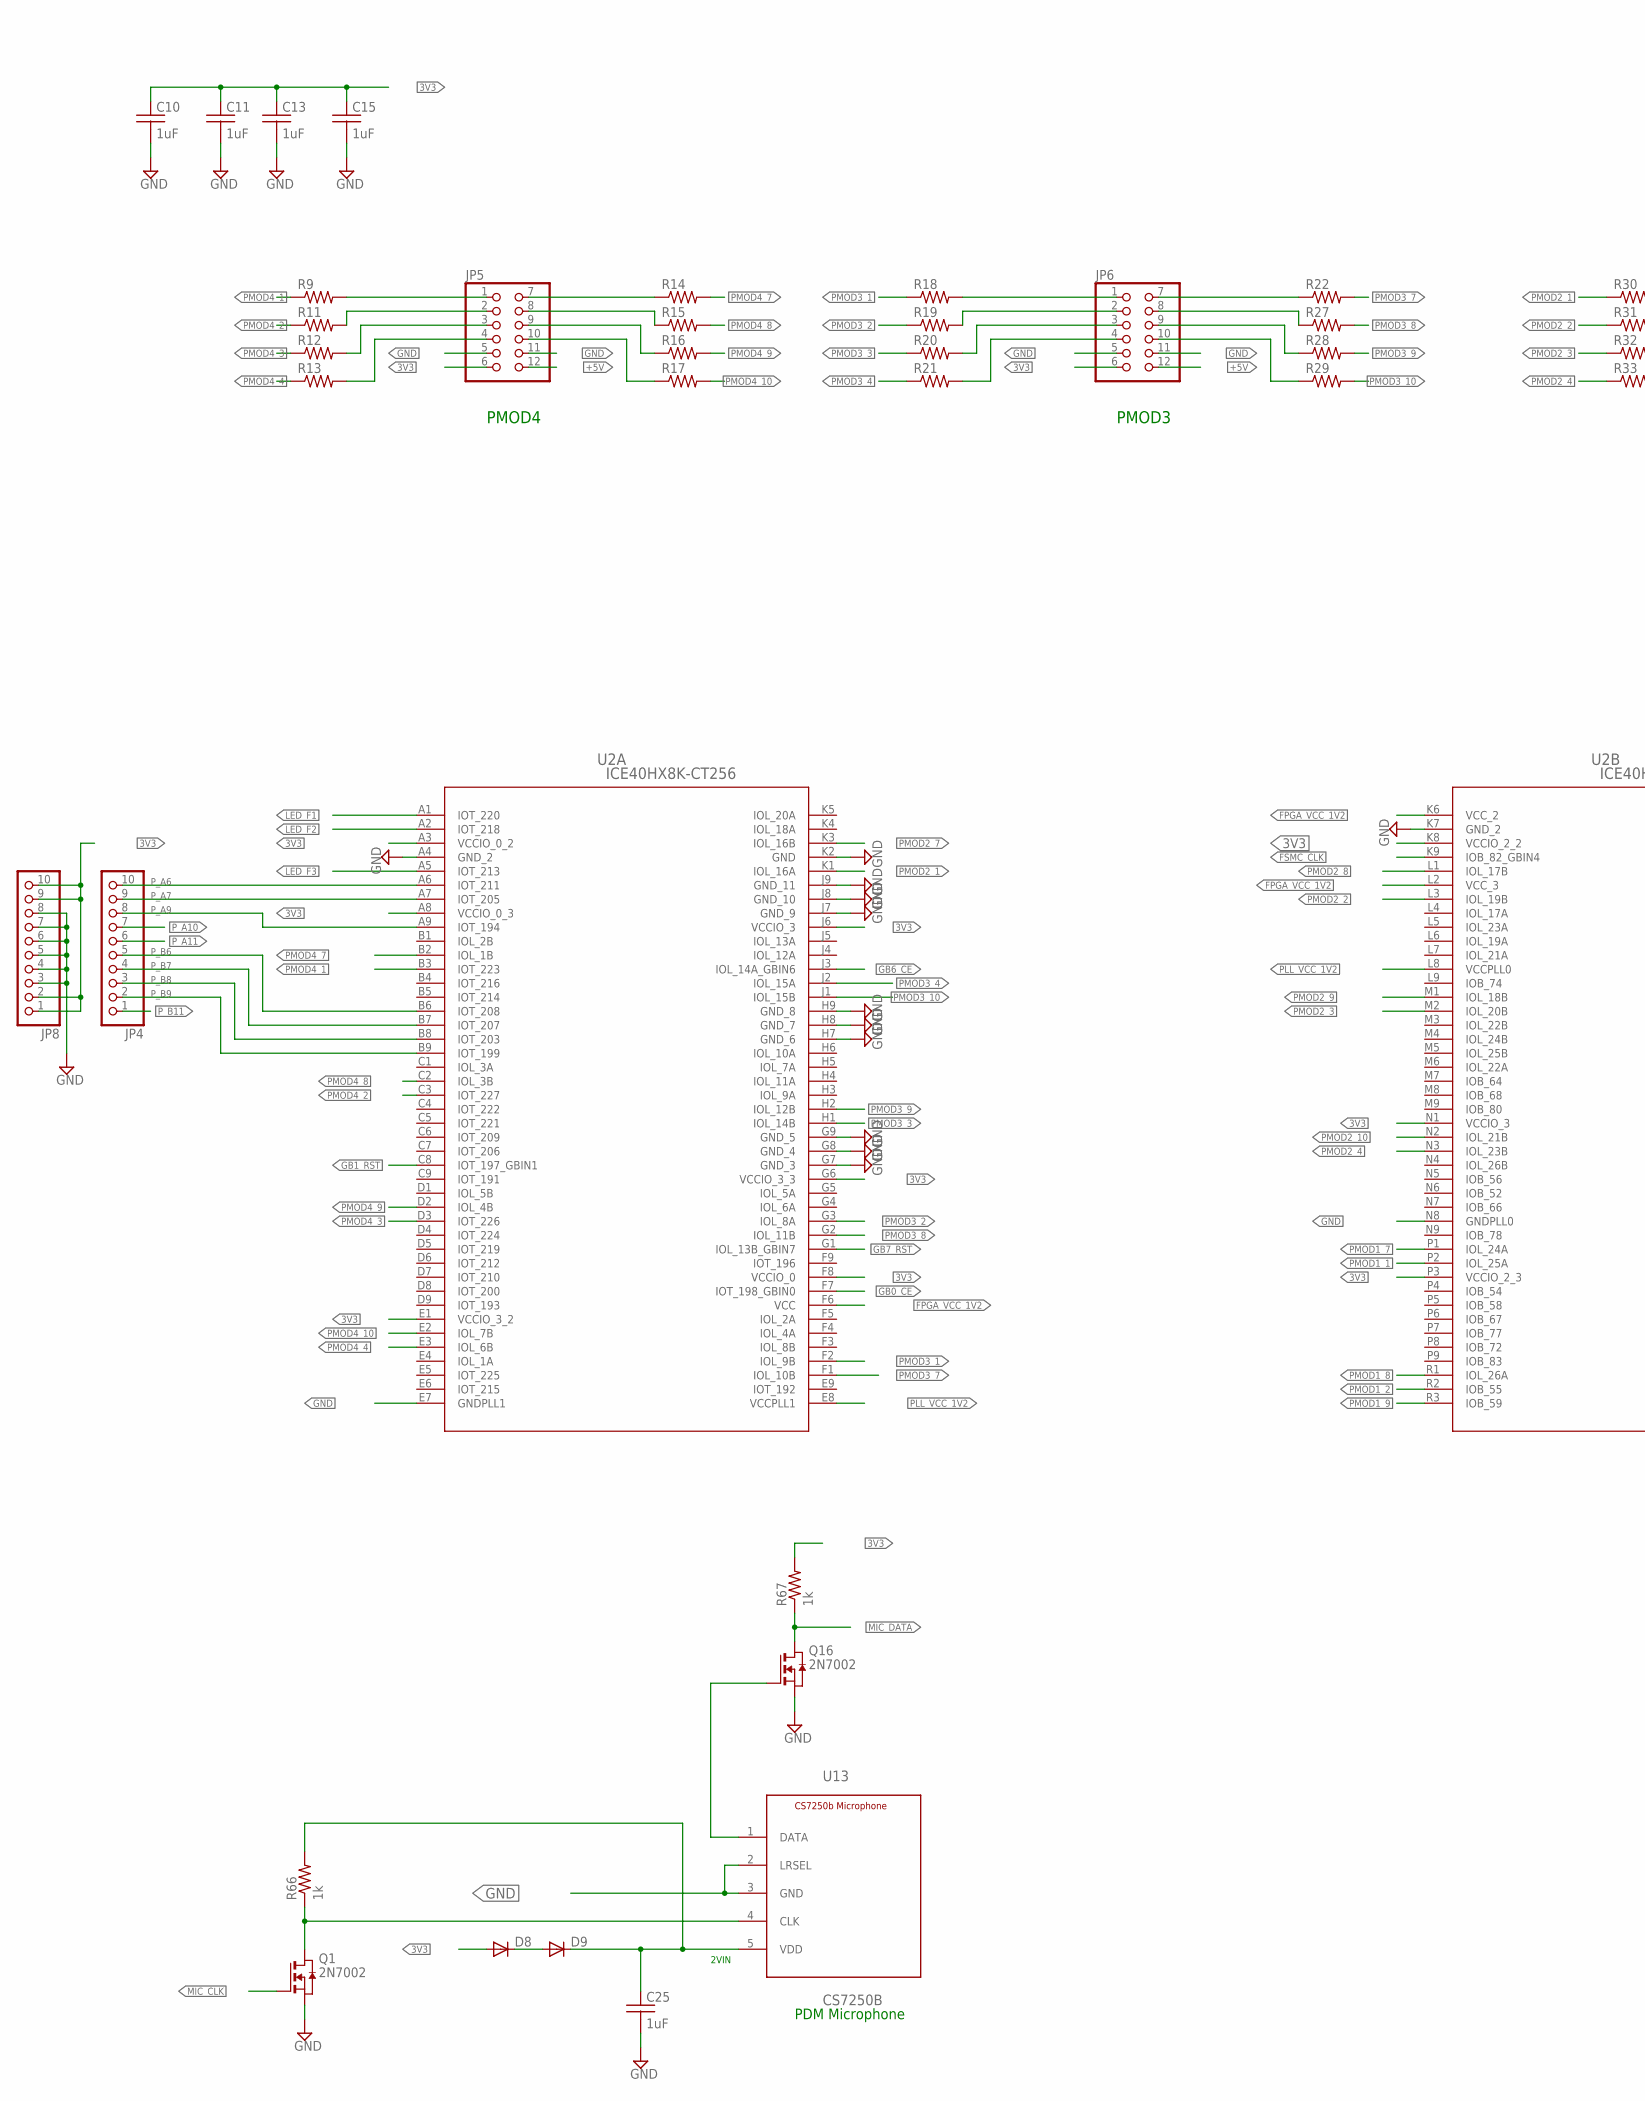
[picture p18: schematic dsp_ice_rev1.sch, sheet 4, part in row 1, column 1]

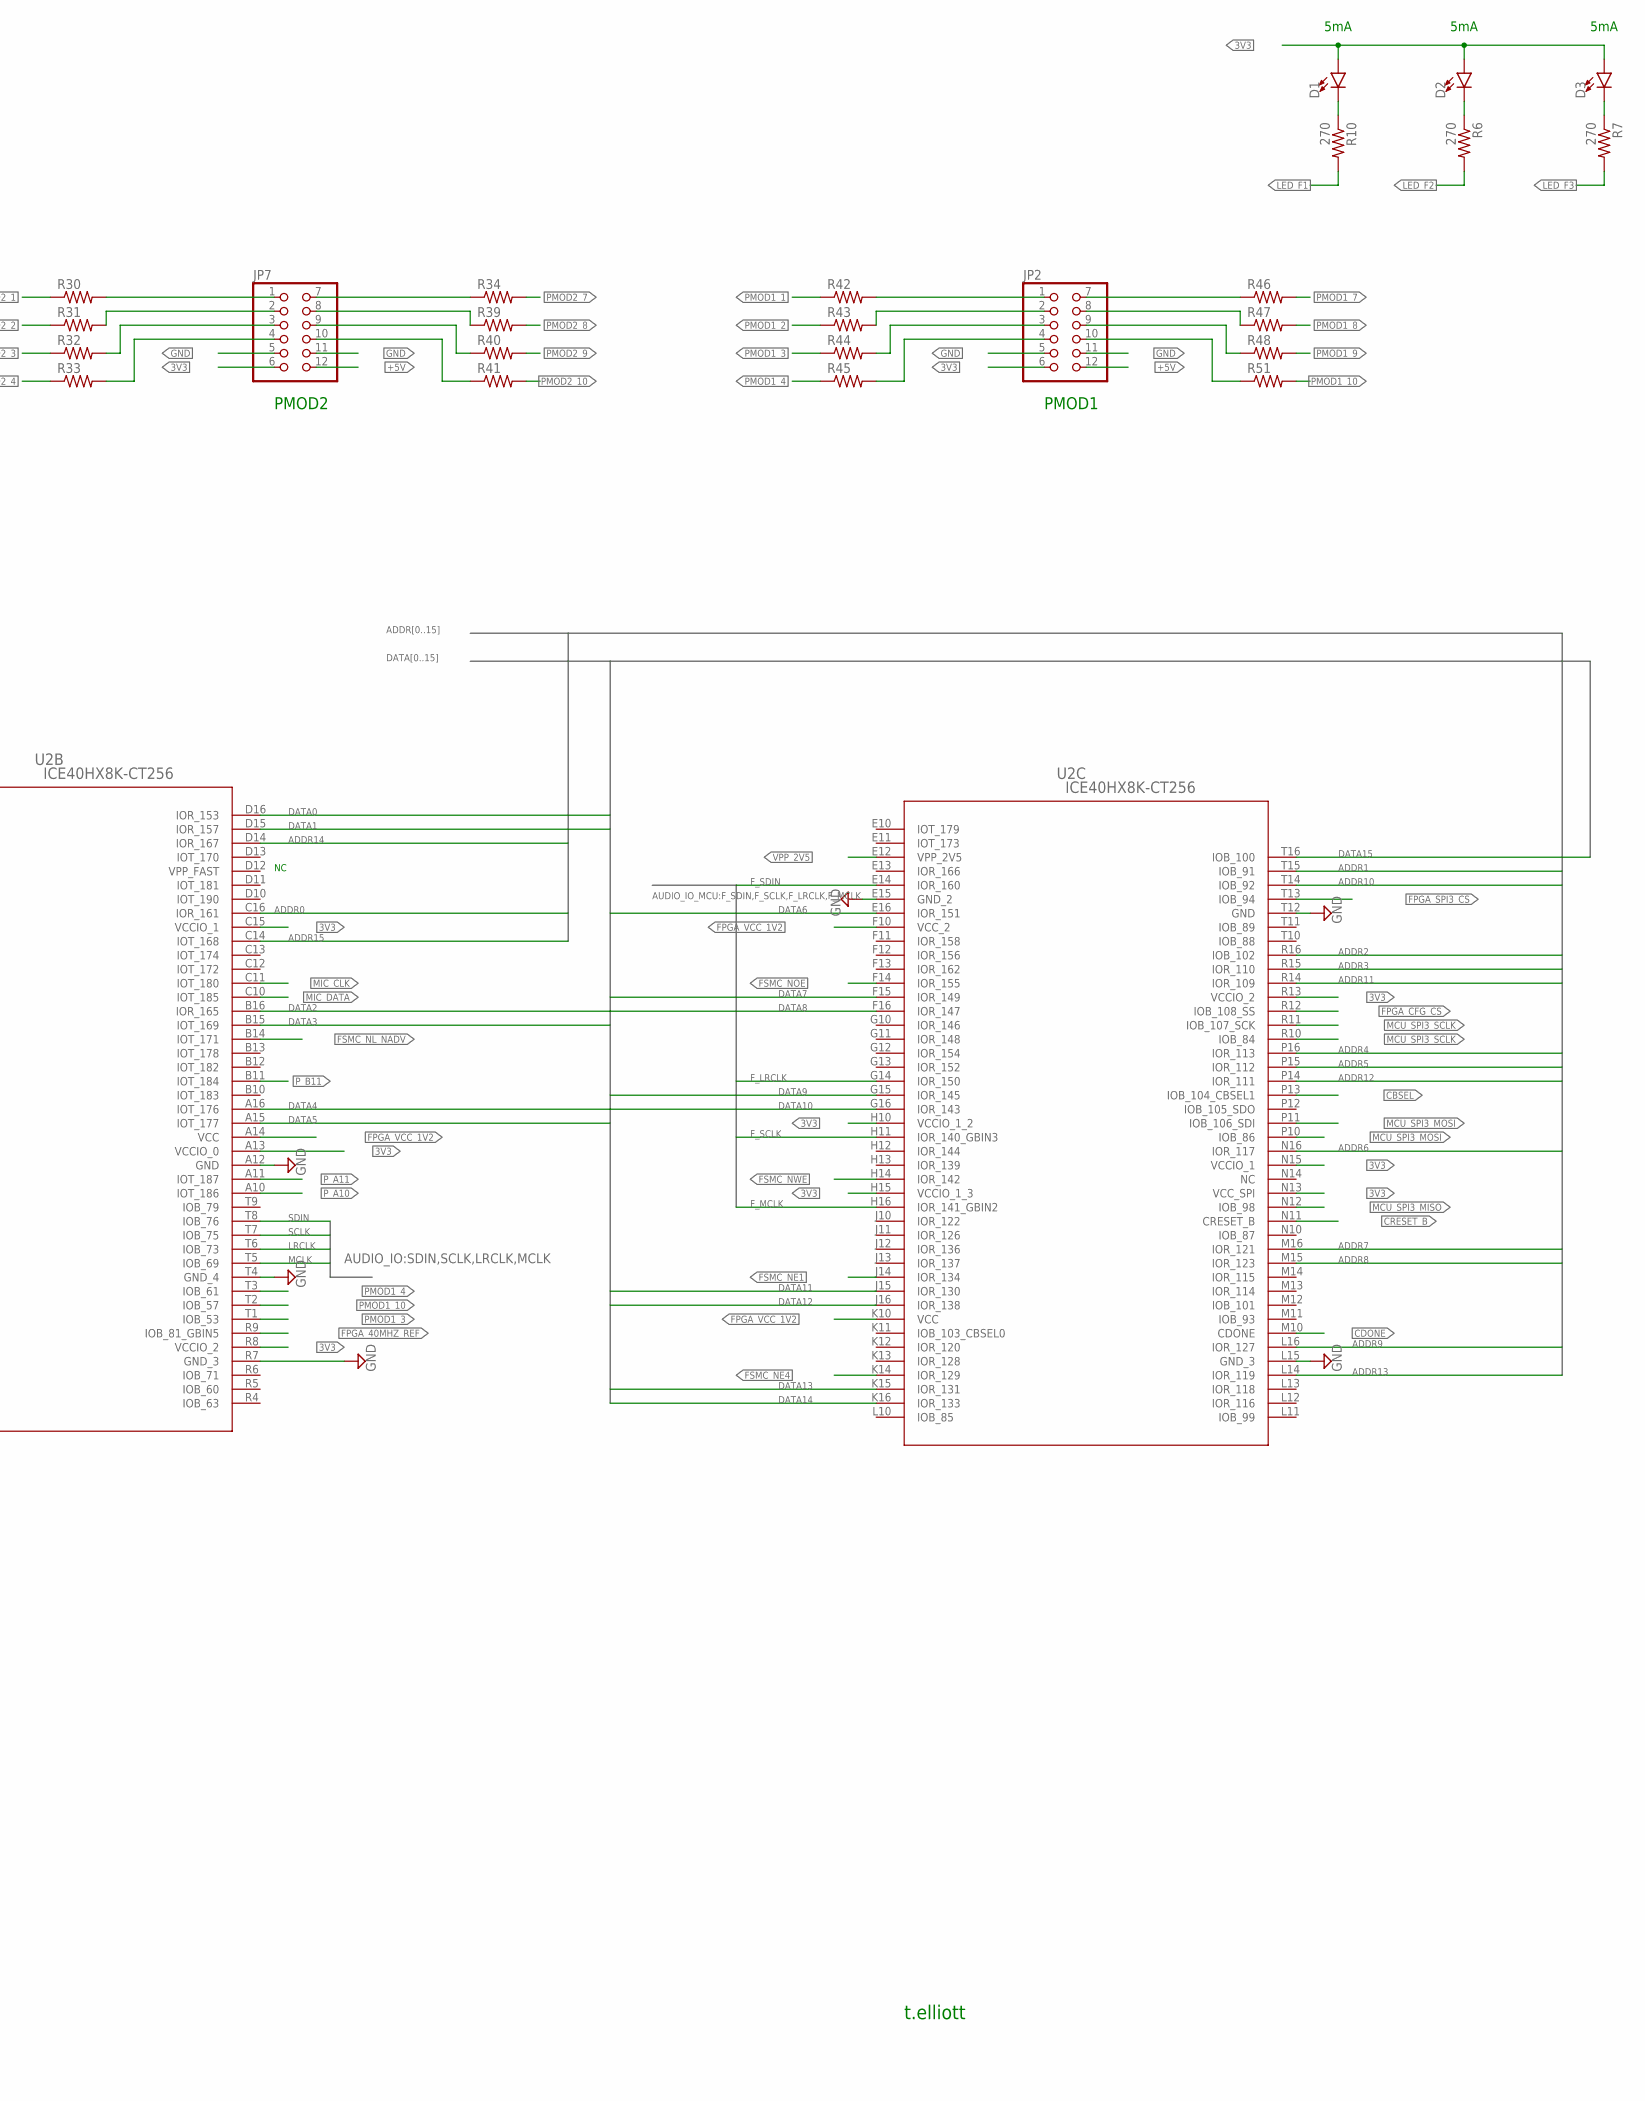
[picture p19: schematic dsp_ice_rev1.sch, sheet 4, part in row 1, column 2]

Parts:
C10, C11, C13, C15, C25: 1uF; C0603
D1, D2, D3: LED1206; LED-1206
D8, D9: DIODE-MINIMELF; MINIMELF
JP2, JP5, JP6, JP7: PINHD-2X6; 2X06
JP4, JP8: PINHD-1X10; 1X10
Q1, Q16: 2N7002; SOT23_2N7002_PACKAGE
R6, R7, R10: 270; R0603
R9, R11, R12, R13, R14, R15, R16, R17, R18, R19, R20, R21, R22, R27, R28, R29, R30, R31, R32, R33, R34, R39, R40, R41, R42, R43, R44, R45, R46, R47, R48, R51: 10; R0603
R66, R67: 1k; R0603
U2: ICE40HX8K-CT256; CABGA256
U13: CS7250B; CS7250B-CAZR

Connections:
3V3: C10.1, C11.1, C13.1, C15.1, D1.A, D2.A, D3.A, D8.A, JP2.6 (11), JP5.6 (11), JP6.6 (11), JP7.6 (11), JP8.1, JP8.2, JP8.9, JP8.10, R67.2, U2.A3 (VCCIO_0_2), U2.A8 (VCCIO_0_3), U2.A13 (VCCIO_0), U2.C15 (VCCIO_1), U2.E1 (VCCIO_3_2), U2.F8 (VCCIO_0), U2.G6 (VCCIO_3_3), U2.H10 (VCCIO_1_2), U2.H15 (VCCIO_1_3), U2.J6 (VCCIO_3), U2.K8 (VCCIO_2_2), U2.N1 (VCCIO_3), U2.N13 (VCC_SPI), U2.N15 (VCCIO_1), U2.P3 (VCCIO_2_3), U2.R8 (VCCIO_2), U2.R13 (VCCIO_2); also elsewhere on the board
+5V: JP2.12, JP5.12, JP6.12, JP7.12; also elsewhere on the board
ADDR0: U2.C16 (IOR_161); also elsewhere on the board
ADDR1: U2.T15 (IOB_91); also elsewhere on the board
ADDR2: U2.R16 (IOB_102); also elsewhere on the board
ADDR3: U2.R15 (IOR_110); also elsewhere on the board
ADDR4: U2.P16 (IOR_113); also elsewhere on the board
ADDR5: U2.P15 (IOR_112); also elsewhere on the board
ADDR6: U2.N16 (IOR_117); also elsewhere on the board
ADDR7: U2.M16 (IOR_121); also elsewhere on the board
ADDR8: U2.M15 (IOR_123); also elsewhere on the board
ADDR9: U2.L16 (IOR_127); also elsewhere on the board
ADDR10: U2.T14 (IOB_92); also elsewhere on the board
ADDR11: U2.R14 (IOR_109); also elsewhere on the board
ADDR12: U2.P14 (IOR_111); also elsewhere on the board
ADDR13: U2.L14 (IOR_119); also elsewhere on the board
ADDR14: U2.D14 (IOR_167); also elsewhere on the board
ADDR15: U2.C14 (IOT_168); also elsewhere on the board
CBSEL: U2.P13 (IOB_104_CBSEL1); also elsewhere on the board
CDONE: U2.M10 (CDONE); also elsewhere on the board
CRESET_B: U2.N11 (CRESET_B); also elsewhere on the board
DATA0: U2.D16 (IOR_153); also elsewhere on the board
DATA1: U2.D15 (IOR_157); also elsewhere on the board
DATA2: U2.B16 (IOR_165); also elsewhere on the board
DATA3: U2.B15 (IOT_169); also elsewhere on the board
DATA4: U2.A16 (IOT_176); also elsewhere on the board
DATA5: U2.A15 (IOT_177); also elsewhere on the board
DATA6: U2.E16 (IOR_151); also elsewhere on the board
DATA7: U2.F15 (IOR_149); also elsewhere on the board
DATA8: U2.F16 (IOR_147); also elsewhere on the board
DATA9: U2.G15 (IOR_145); also elsewhere on the board
DATA10: U2.G16 (IOR_143); also elsewhere on the board
DATA11: U2.J15 (IOR_130); also elsewhere on the board
DATA12: U2.J16 (IOR_138); also elsewhere on the board
DATA13: U2.K15 (IOR_131); also elsewhere on the board
DATA14: U2.K16 (IOR_133); also elsewhere on the board
DATA15: U2.T16 (IOB_100); also elsewhere on the board
FPGA_40MHZ_REF: U2.R9 (IOB_81_GBIN5); also elsewhere on the board
FPGA_CFG_CS: U2.R12 (IOB_108_SS); also elsewhere on the board
FPGA_SPI3_CS: U2.T13 (IOB_94); also elsewhere on the board
FPGA_VCC_1V2: U2.A14 (VCC), U2.F6 (VCC), U2.F10 (VCC_2), U2.K6 (VCC_2), U2.K10 (VCC), U2.L2 (VCC_3); also elsewhere on the board
FSMC_CLK: U2.K9 (IOB_82_GBIN4); also elsewhere on the board
FSMC_NE1: U2.J14 (IOR_134); also elsewhere on the board
FSMC_NE4: U2.K14 (IOR_129); also elsewhere on the board
FSMC_NL_NADV: U2.B14 (IOT_171); also elsewhere on the board
FSMC_NOE: U2.F14 (IOR_155); also elsewhere on the board
FSMC_NWE: U2.H14 (IOR_142); also elsewhere on the board
F_LRCLK: U2.G14 (IOR_150); also elsewhere on the board
F_MCLK: U2.H16 (IOR_141_GBIN2); also elsewhere on the board
F_SCLK: U2.H11 (IOR_140_GBIN3); also elsewhere on the board
F_SDIN: U2.E14 (IOR_160); also elsewhere on the board
GB0_CE: U2.F7 (IOT_198_GBIN0)
GB1_RST: U2.C8 (IOT_197_GBIN1)
GB6_CE: U2.J3 (IOL_14A_GBIN6)
GB7_RST: U2.G1 (IOL_13B_GBIN7)
GND: C10.2, C11.2, C13.2, C15.2, C25.2, JP2.5 (9), JP2.11 (10), JP5.5 (9), JP5.11 (10), JP6.5 (9), JP6.11 (10), JP7.5 (9), JP7.11 (10), JP8.3, JP8.4, JP8.5, JP8.6, JP8.7, JP8.8, Q1.2 (S), Q16.2 (S), U2.A4 (GND_2), U2.A12 (GND), U2.E7 (GNDPLL1), U2.E15 (GND_2), U2.G7 (GND_3), U2.G8 (GND_4), U2.G9 (GND_5), U2.H7 (GND_6), U2.H8 (GND_7), U2.H9 (GND_8), U2.J7 (GND_9), U2.J8 (GND_10), U2.J9 (GND_11), U2.K2 (GND), U2.K7 (GND_2), U2.L15 (GND_3), U2.N8 (GNDPLL0), U2.R7 (GND_3), U2.T4 (GND_4), U2.T12 (GND), U13.2 (LRSEL), U13.3 (GND); also elsewhere on the board
LED_F1: R10.2, U2.A1 (IOT_220)
LED_F2: R6.2, U2.A2 (IOT_218)
LED_F3: R7.2, U2.A5 (IOT_213)
LRCLK: U2.T6 (IOB_73); also elsewhere on the board
MCLK: U2.T5 (IOB_69); also elsewhere on the board
MCU_SPI3_MISO: U2.N12 (IOB_98); also elsewhere on the board
MCU_SPI3_MOSI: U2.P10 (IOB_86), U2.P11 (IOB_106_SDI); also elsewhere on the board
MCU_SPI3_SCLK: U2.R10 (IOB_84), U2.R11 (IOB_107_SCK); also elsewhere on the board
MIC_CLK: Q1.1 (G), U2.C11 (IOT_180)
MIC_DATA: Q16.3 (D), R67.1, U2.C10 (IOT_185)
unnamed: D1.C, R10.1
unnamed: D2.C, R6.1
unnamed: D3.C, R7.1
unnamed: JP5.1, R9.2
unnamed: JP5.2 (3), R11.2
unnamed: JP5.3 (5), R12.2
unnamed: JP5.4 (7), R13.2
unnamed: JP5.10 (8), R17.1
unnamed: JP5.9 (6), R16.1
unnamed: JP5.8 (4), R15.1
unnamed: JP5.7 (2), R14.1
unnamed: JP6.1, R18.2
unnamed: JP6.2 (3), R19.2
unnamed: JP6.3 (5), R20.2
unnamed: JP6.4 (7), R21.2
unnamed: D8.C, D9.A
unnamed: JP6.7 (2), R22.1
unnamed: JP6.8 (4), R27.1
unnamed: JP6.9 (6), R28.1
unnamed: JP6.10 (8), R29.1
unnamed: C25.1, D9.C, R66.2, U13.5 (VDD)
unnamed: Q1.3 (D), R66.1, U13.4 (CLK)
unnamed: Q16.1 (G), U13.1 (DATA)
unnamed: JP7.1, R30.2
unnamed: JP7.2 (3), R31.2
unnamed: JP7.3 (5), R32.2
unnamed: JP7.4 (7), R33.2
unnamed: JP7.7 (2), R34.1
unnamed: JP7.8 (4), R39.1
unnamed: JP7.9 (6), R40.1
unnamed: JP7.10 (8), R41.1
unnamed: JP2.1, R42.2
unnamed: JP2.2 (3), R43.2
unnamed: JP2.3 (5), R44.2
unnamed: JP2.4 (7), R45.2
unnamed: JP2.7 (2), R46.1
unnamed: JP2.8 (4), R47.1
unnamed: JP2.9 (6), R48.1
unnamed: JP2.10 (8), R51.1
PLL_VCC_1V2: U2.E8 (VCCPLL1), U2.L8 (VCCPLL0); also elsewhere on the board
PMOD1_1: R42.1, U2.P2 (IOL_25A)
PMOD1_2: R43.1, U2.R2 (IOB_55)
PMOD1_3: R44.1, U2.T1 (IOB_53)
PMOD1_4: R45.1, U2.T3 (IOB_61)
PMOD1_7: R46.2, U2.P1 (IOL_24A)
PMOD1_8: R47.2, U2.R1 (IOL_26A)
PMOD1_9: R48.2, U2.R3 (IOB_59)
PMOD1_10: R51.2, U2.T2 (IOB_57)
PMOD2_1: R30.1, U2.K1 (IOL_16A)
PMOD2_2: R31.1, U2.L3 (IOL_19B)
PMOD2_3: R32.1, U2.M2 (IOL_20B)
PMOD2_4: R33.1, U2.N3 (IOL_23B)
PMOD2_7: R34.2, U2.K3 (IOL_16B)
PMOD2_8: R39.2, U2.L1 (IOL_17B)
PMOD2_9: R40.2, U2.M1 (IOL_18B)
PMOD2_10: R41.2, U2.N2 (IOL_21B)
PMOD3_1: R18.1, U2.F2 (IOL_9B)
PMOD3_2: R19.1, U2.G3 (IOL_8A)
PMOD3_3: R20.1, U2.H1 (IOL_14B)
PMOD3_4: R21.1, U2.J2 (IOL_15A)
PMOD3_7: R22.2, U2.F1 (IOL_10B)
PMOD3_8: R27.2, U2.G2 (IOL_11B)
PMOD3_9: R28.2, U2.H2 (IOL_12B)
PMOD3_10: R29.2, U2.J1 (IOL_15B)
PMOD4_1: R9.1, U2.B3 (IOT_223)
PMOD4_2: R11.1, U2.C3 (IOT_227)
PMOD4_3: R12.1, U2.D3 (IOT_226)
PMOD4_4: R13.1, U2.E3 (IOL_6B)
PMOD4_7: R14.2, U2.B2 (IOL_1B)
PMOD4_8: R15.2, U2.C2 (IOL_3B)
PMOD4_9: R16.2, U2.D2 (IOL_4B)
PMOD4_10: R17.2, U2.E2 (IOL_7B)
P_A6: JP4.10, U2.A6 (IOT_211)
P_A7: JP4.9, U2.A7 (IOT_205)
P_A9: JP4.8, U2.A9 (IOT_194)
P_A10: JP4.7, U2.A10 (IOT_186)
P_A11: JP4.6, U2.A11 (IOT_187)
P_B6: JP4.5, U2.B6 (IOT_208)
P_B7: JP4.4, U2.B7 (IOT_207)
P_B8: JP4.3, U2.B8 (IOT_203)
P_B9: JP4.2, U2.B9 (IOT_199)
P_B11: JP4.1, U2.B11 (IOT_184)
SCLK: U2.T7 (IOB_75); also elsewhere on the board
SDIN: U2.T8 (IOB_76); also elsewhere on the board
VPP_2V5: U2.E12 (VPP_2V5); also elsewhere on the board
VPP_FAST: U2.D12 (VPP_FAST)

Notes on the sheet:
5mA
PMOD4
PMOD3
PMOD2
PMOD1
t.elliott
PDM Microphone
2VIN

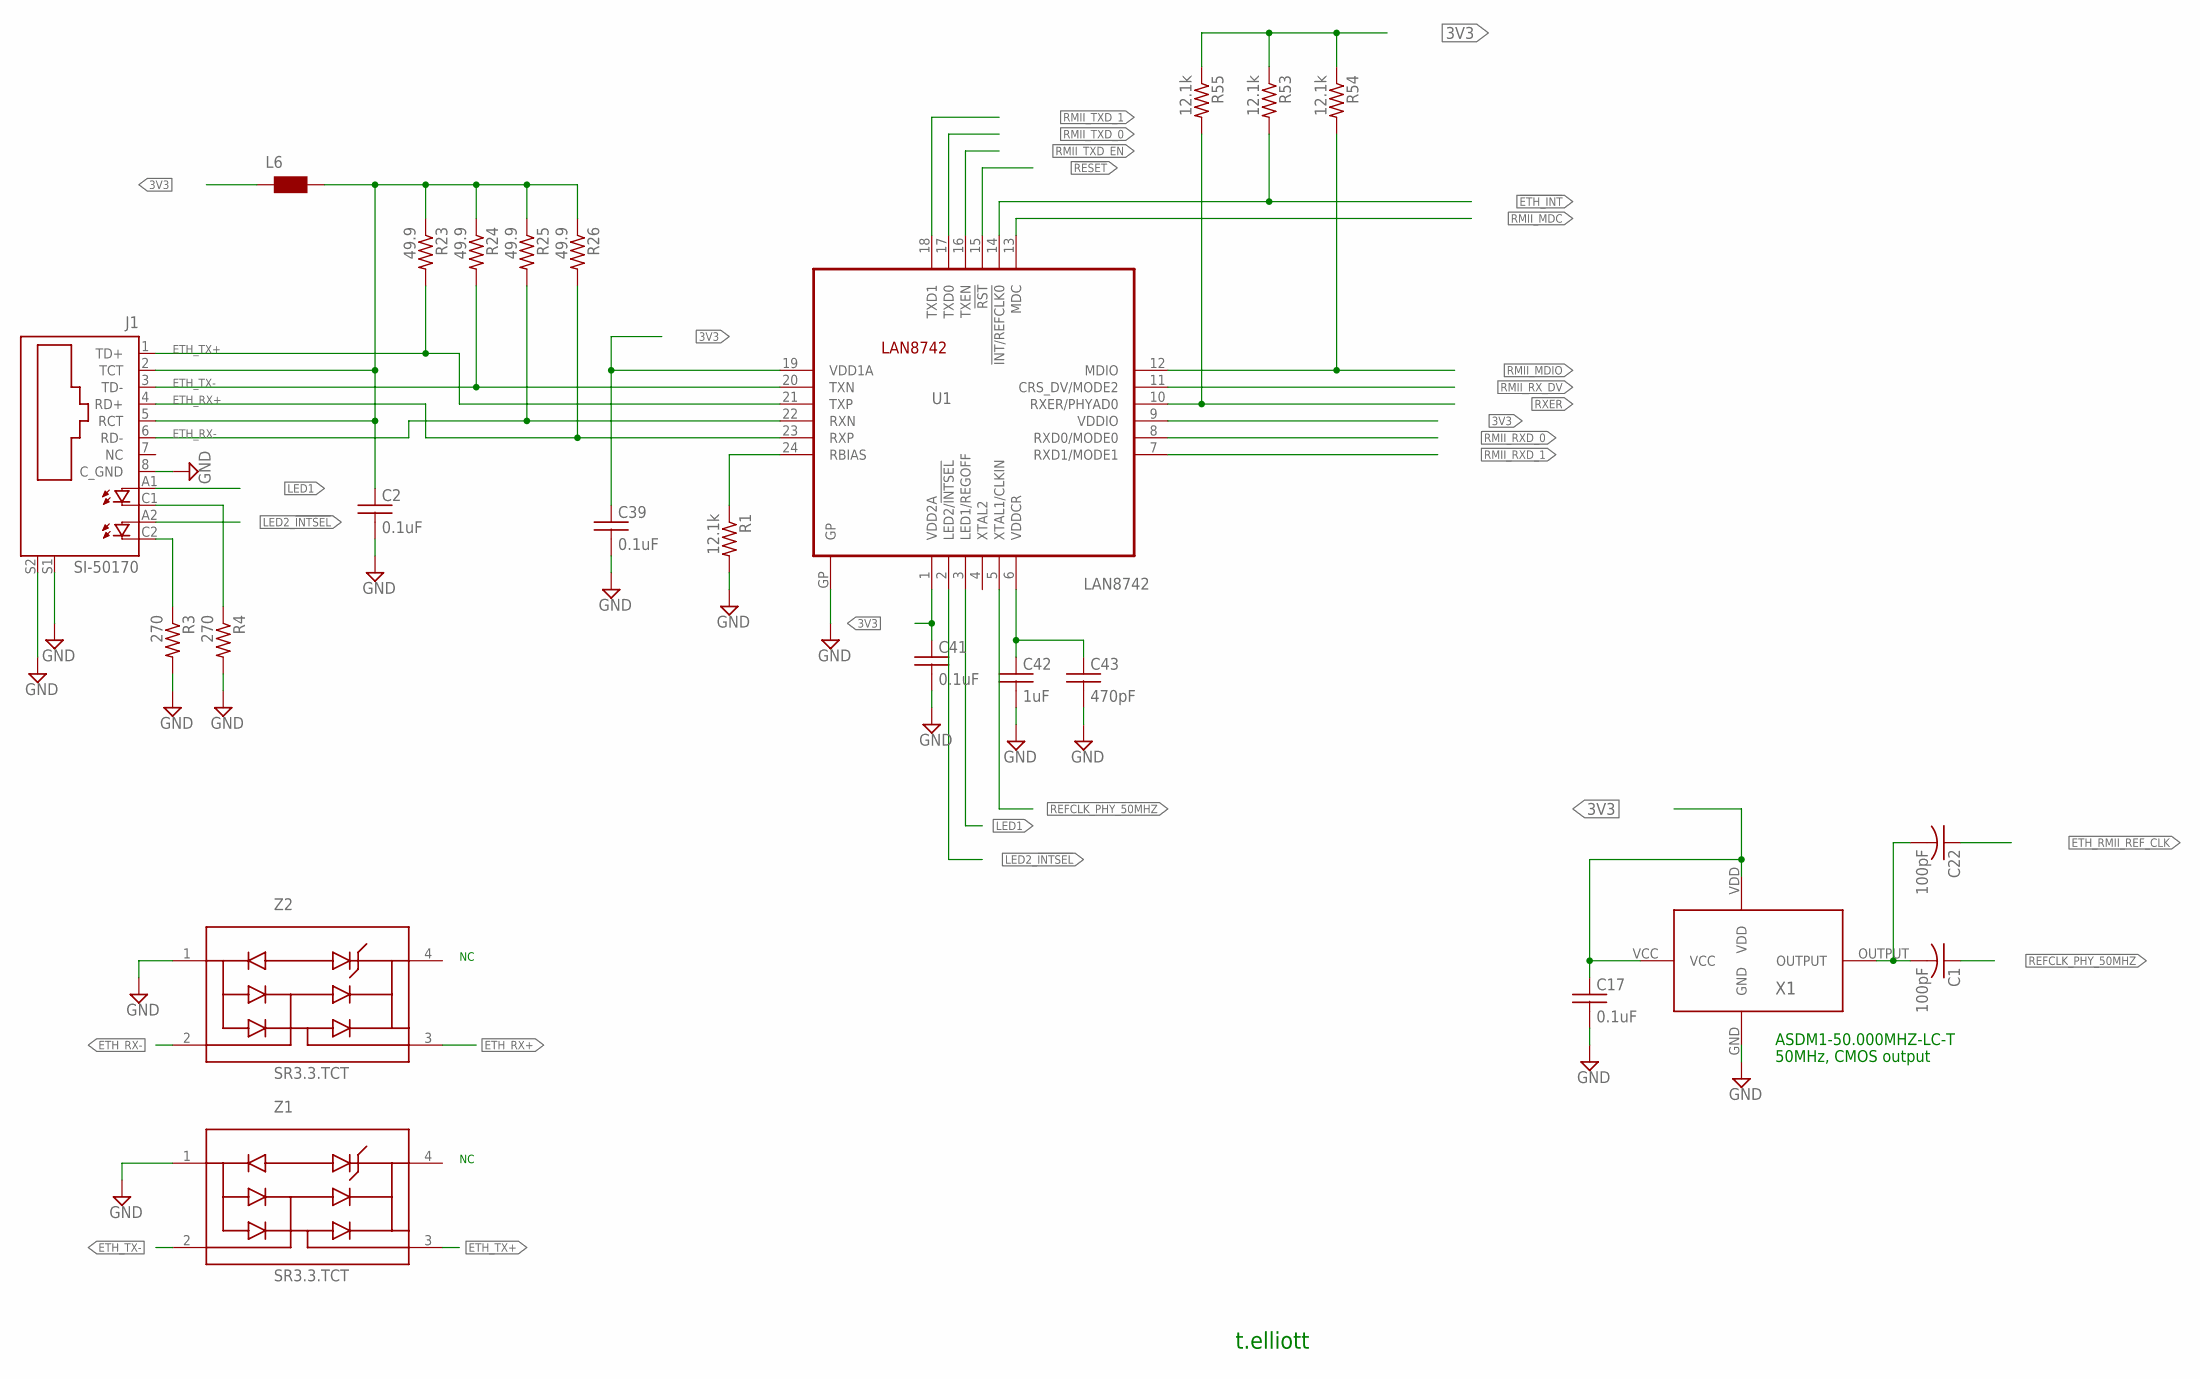
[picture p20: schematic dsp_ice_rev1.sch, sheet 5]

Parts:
C1, C22: 100pF; C0603
C2, C17, C39, C41: 0.1uF; C0603
C42: 1uF; C0603
C43: 470pF; C0603
J1: SI-50170
L6: WE-CBF_0603; 0603
R1, R53, R54, R55: 12.1k; R0603
R3, R4: 270; R0603
R23, R24, R25, R26: 49.9; R0603
U1: LAN8742; QFN-24
X1: ASDM1-50.000MHZ-LC-T; CRYSTAL_2.5_2MM
Z1, Z2: SR3.3.TCT; SR2.8.TCT_1PRIMARY

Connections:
3V3: C17.1, C39.1, C41.1, L6.1, R53.1, R54.1, R55.1, U1.1 (VDD2A), U1.9 (VDDIO), U1.19 (VDD1A), X1.VCC, X1.VDD; also elsewhere on the board
!ETH_INT: R53.2, U1.14 (!INT/REFCLK0); also elsewhere on the board
!RESET: U1.15 (!RST); also elsewhere on the board
ETH_RMII_REF_CLK: C22.1; also elsewhere on the board
ETH_RX+: J1.4 (RD+), R26.2, U1.23 (RXP), Z2.3 (I/O)
ETH_RX-: J1.6 (RD-), R25.2, U1.22 (RXN), Z2.2 (I/O)
ETH_TX+: J1.1 (TD+), R23.2, U1.21 (TXP), Z1.3 (I/O)
ETH_TX-: J1.3 (TD-), R24.2, U1.20 (TXN), Z1.2 (I/O)
GND: C2.2, C17.2, C39.2, C41.2, C42.2, C43.2, J1.8 (C_GND), J1.S1, J1.S2, R1.2, R3.2, R4.2, U1.GP, X1.GND, Z1.1 (GND), Z2.1 (GND); also elsewhere on the board
LED1: J1.A1 (A), U1.3 (LED1/REGOFF)
LED2_!INTSEL: J1.A2 (A1), U1.2 (LED2/!INTSEL)
unnamed: C1.2, C22.2, X1.OUTPUT
unnamed: C42.1, C43.1, U1.6 (VDDCR)
unnamed: J1.C2 (C1), R3.1
unnamed: R1.1, U1.24 (RBIAS)
unnamed: C2.1, J1.2 (TCT), J1.5 (RCT), L6.2, R23.1, R24.1, R25.1, R26.1
unnamed: J1.C1 (C), R4.1
REFCLK_PHY_50MHZ: C1.1, U1.5 (XTAL1/CLKIN)
RMII_MDC: U1.13 (MDC); also elsewhere on the board
RMII_MDIO: R54.2, U1.12 (MDIO); also elsewhere on the board
RMII_RXD_0: U1.8 (RXD0/MODE0); also elsewhere on the board
RMII_RXD_1: U1.7 (RXD1/MODE1); also elsewhere on the board
RMII_RX_DV: U1.11 (CRS_DV/MODE2); also elsewhere on the board
RMII_TXD_0: U1.17 (TXD0); also elsewhere on the board
RMII_TXD_1: U1.18 (TXD1); also elsewhere on the board
RMII_TXD_EN: U1.16 (TXEN); also elsewhere on the board
RXER: R55.2, U1.10 (RXER/PHYAD0)

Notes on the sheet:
ASDM1-50.000MHZ-LC-T
50MHz, CMOS output
t.elliott

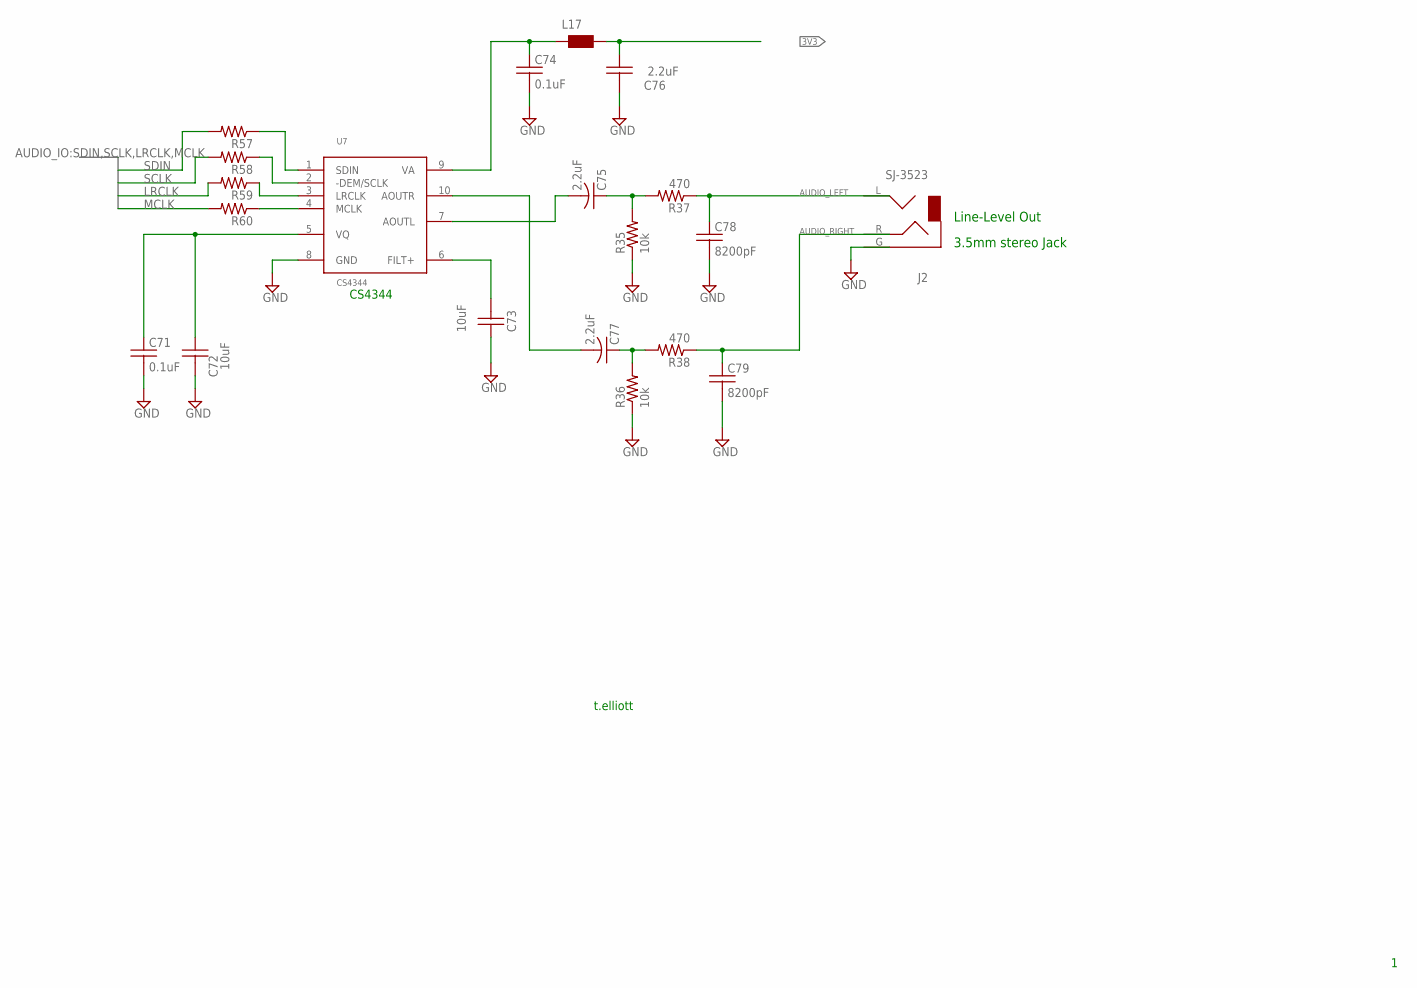
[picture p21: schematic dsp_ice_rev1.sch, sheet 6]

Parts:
C71, C74: 0.1uF; C0603
C72, C73: 10uF; C0805
C75, C76, C77: 2.2uF; C0805
C78, C79: 8200pF; C0603
J2: SJ-3523
L17: WE-CBF_0603; 0603
R35, R36: 10k; R0402
R37, R38, R57, R58, R59, R60: 470; R0402
U7: CS4344; MSOP10

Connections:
3V3: C76.1, L17.2; also elsewhere on the board
AUDIO_LEFT: C79.1, J2.R, R38.1
AUDIO_RIGHT: C78.1, J2.L, R37.1
GND: C71.2, C72.2, C73.1, C74.2, C76.2, C78.2, C79.2, J2.G, R35.1, R36.1, U7.8 (GND); also elsewhere on the board
LRCLK: R59.2; also elsewhere on the board
MCLK: R60.2; also elsewhere on the board
unnamed: C77.2, U7.10 (AOUTR)
unnamed: R60.1, U7.4 (MCLK)
unnamed: R59.1, U7.3 (LRCLK)
unnamed: R58.1, U7.2 (-DEM/SCLK)
unnamed: R57.1, U7.1 (SDIN)
unnamed: C73.2, U7.6 (FILT+)
unnamed: C71.1, C72.1, U7.5 (VQ)
unnamed: C75.2, U7.7 (AOUTL)
unnamed: C75.1, R35.2, R37.2
unnamed: C77.1, R36.2, R38.2
unnamed: C74.1, L17.1, U7.9 (VA)
SCLK: R58.2; also elsewhere on the board
SDIN: R57.2; also elsewhere on the board

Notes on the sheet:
t.elliott
CS4344
Line-Level Out
3.5mm stereo Jack

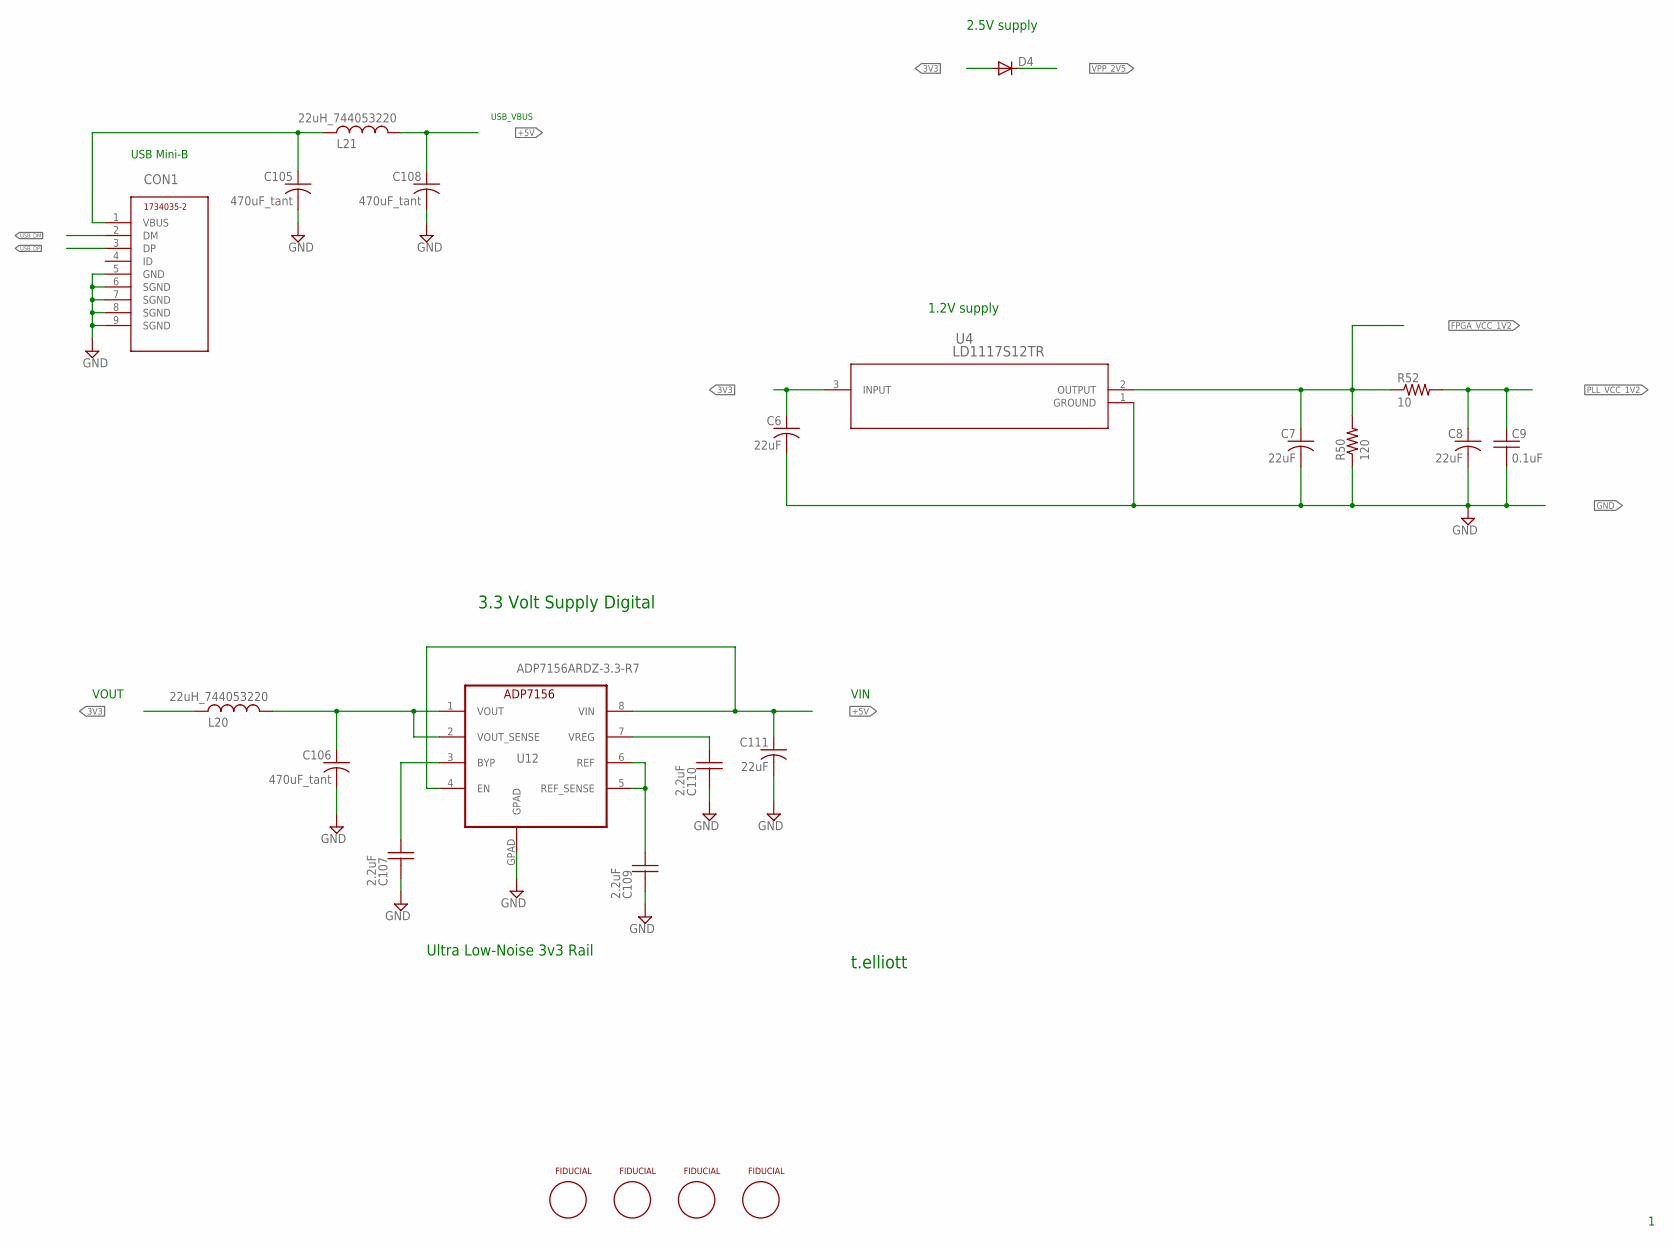
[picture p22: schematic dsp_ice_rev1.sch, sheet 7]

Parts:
C6, C7, C8, C111: 22uF; 1210K
C9: 0.1uF; C0603
C105, C106, C108: 470uF_tant; 1210K
C107, C109, C110: 2.2uF; C0805
CON1: 1734035-2
D4: DIODE-MINIMELF; MINIMELF
FID1, FID2, FID3, FID4: FIDUCIALSMD; FIDUCIAL
L20, L21: 22uH_744053220; POWER-CHOKE_WE-TPC
R50: 120; R0603
R52: 10; R0603
U4: LD1117S12TR; SOT-223
U12: ADP7156ARDZ-3.3-R7; SO8

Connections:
3V3: C6.A, D4.A, L20.2, U4.3 (INPUT); also elsewhere on the board
+5V: C108.A, C111.A, L21.1, U12.4 (EN), U12.8 (VIN); also elsewhere on the board
FPGA_VCC_1V2: C7.A, R50.2, R52.1, U4.2 (OUTPUT); also elsewhere on the board
GND: C6.C, C7.C, C8.C, C9.2, C105.C, C106.C, C107.2, C108.C, C109.2, C110.2, C111.C, CON1.5 (GND), CON1.6 (SGND), CON1.7 (SGND), CON1.8 (SGND), CON1.9 (SGND), R50.1, U4.1 (GROUND), U12.GPAD; also elsewhere on the board
unnamed: C105.A, CON1.1 (VBUS), L21.2
unnamed: C106.A, L20.1, U12.1 (VOUT), U12.2 (VOUT_SENSE)
unnamed: C109.1, U12.5 (REF_SENSE), U12.6 (REF)
unnamed: C110.1, U12.7 (VREG)
unnamed: C107.1, U12.3 (BYP)
PLL_VCC_1V2: C8.A, C9.1, R52.2; also elsewhere on the board
USB_DM: CON1.2 (DM); also elsewhere on the board
USB_DP: CON1.3 (DP); also elsewhere on the board
VPP_2V5: D4.C; also elsewhere on the board

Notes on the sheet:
t.elliott
VIN
VOUT
3.3 Volt Supply Digital
USB Mini-B
USB_VBUS
1.2V supply
2.5V supply
Ultra Low-Noise 3v3 Rail

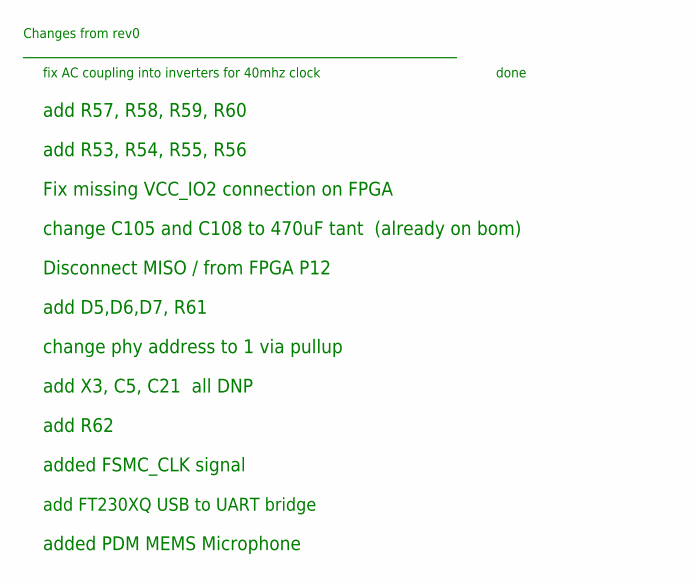
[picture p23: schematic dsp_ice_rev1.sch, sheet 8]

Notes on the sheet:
fix AC coupling into inverters for 40mhz clock
Changes from rev0
done
add R57, R58, R59, R60
add R53, R54, R55, R56
Fix missing VCC_IO2 connection on FPGA
change C105 and C108 to 470uF tant (already on bom)
Disconnect MISO / from FPGA P12
add D5,D6,D7, R61
change phy address to 1 via pullup
add X3, C5, C21 all DNP
add R62
added FSMC_CLK signal
add FT230XQ USB to UART bridge
added PDM MEMS Microphone

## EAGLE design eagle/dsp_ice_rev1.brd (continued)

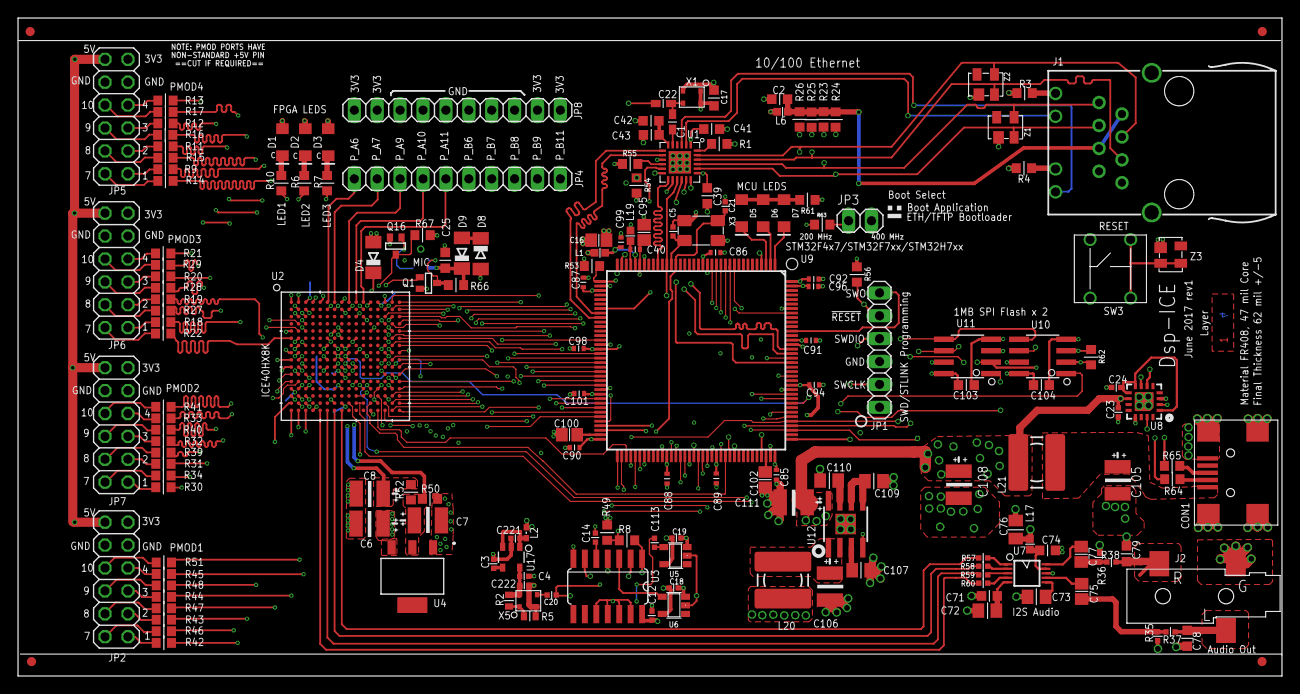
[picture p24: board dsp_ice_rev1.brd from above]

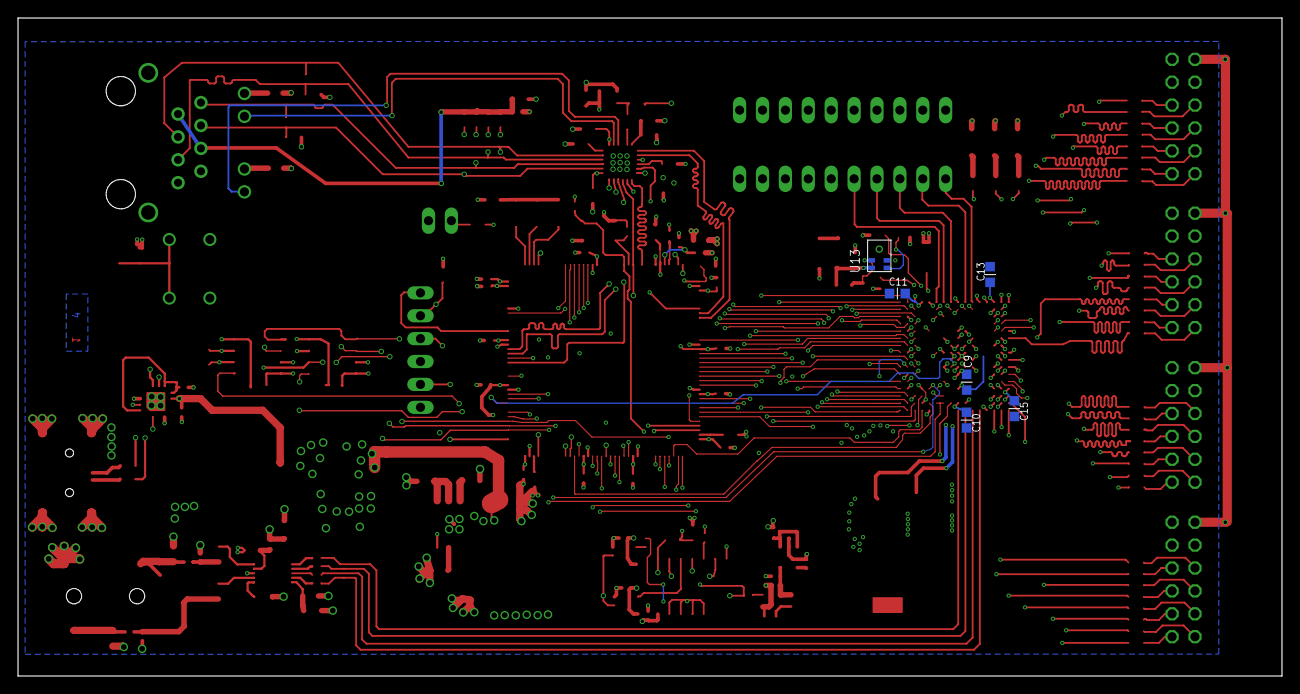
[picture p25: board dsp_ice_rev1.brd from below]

Board: 4 copper layers, 140.2 x 73.0 mm, 188 parts (6 on the bottom side), 223 nets.

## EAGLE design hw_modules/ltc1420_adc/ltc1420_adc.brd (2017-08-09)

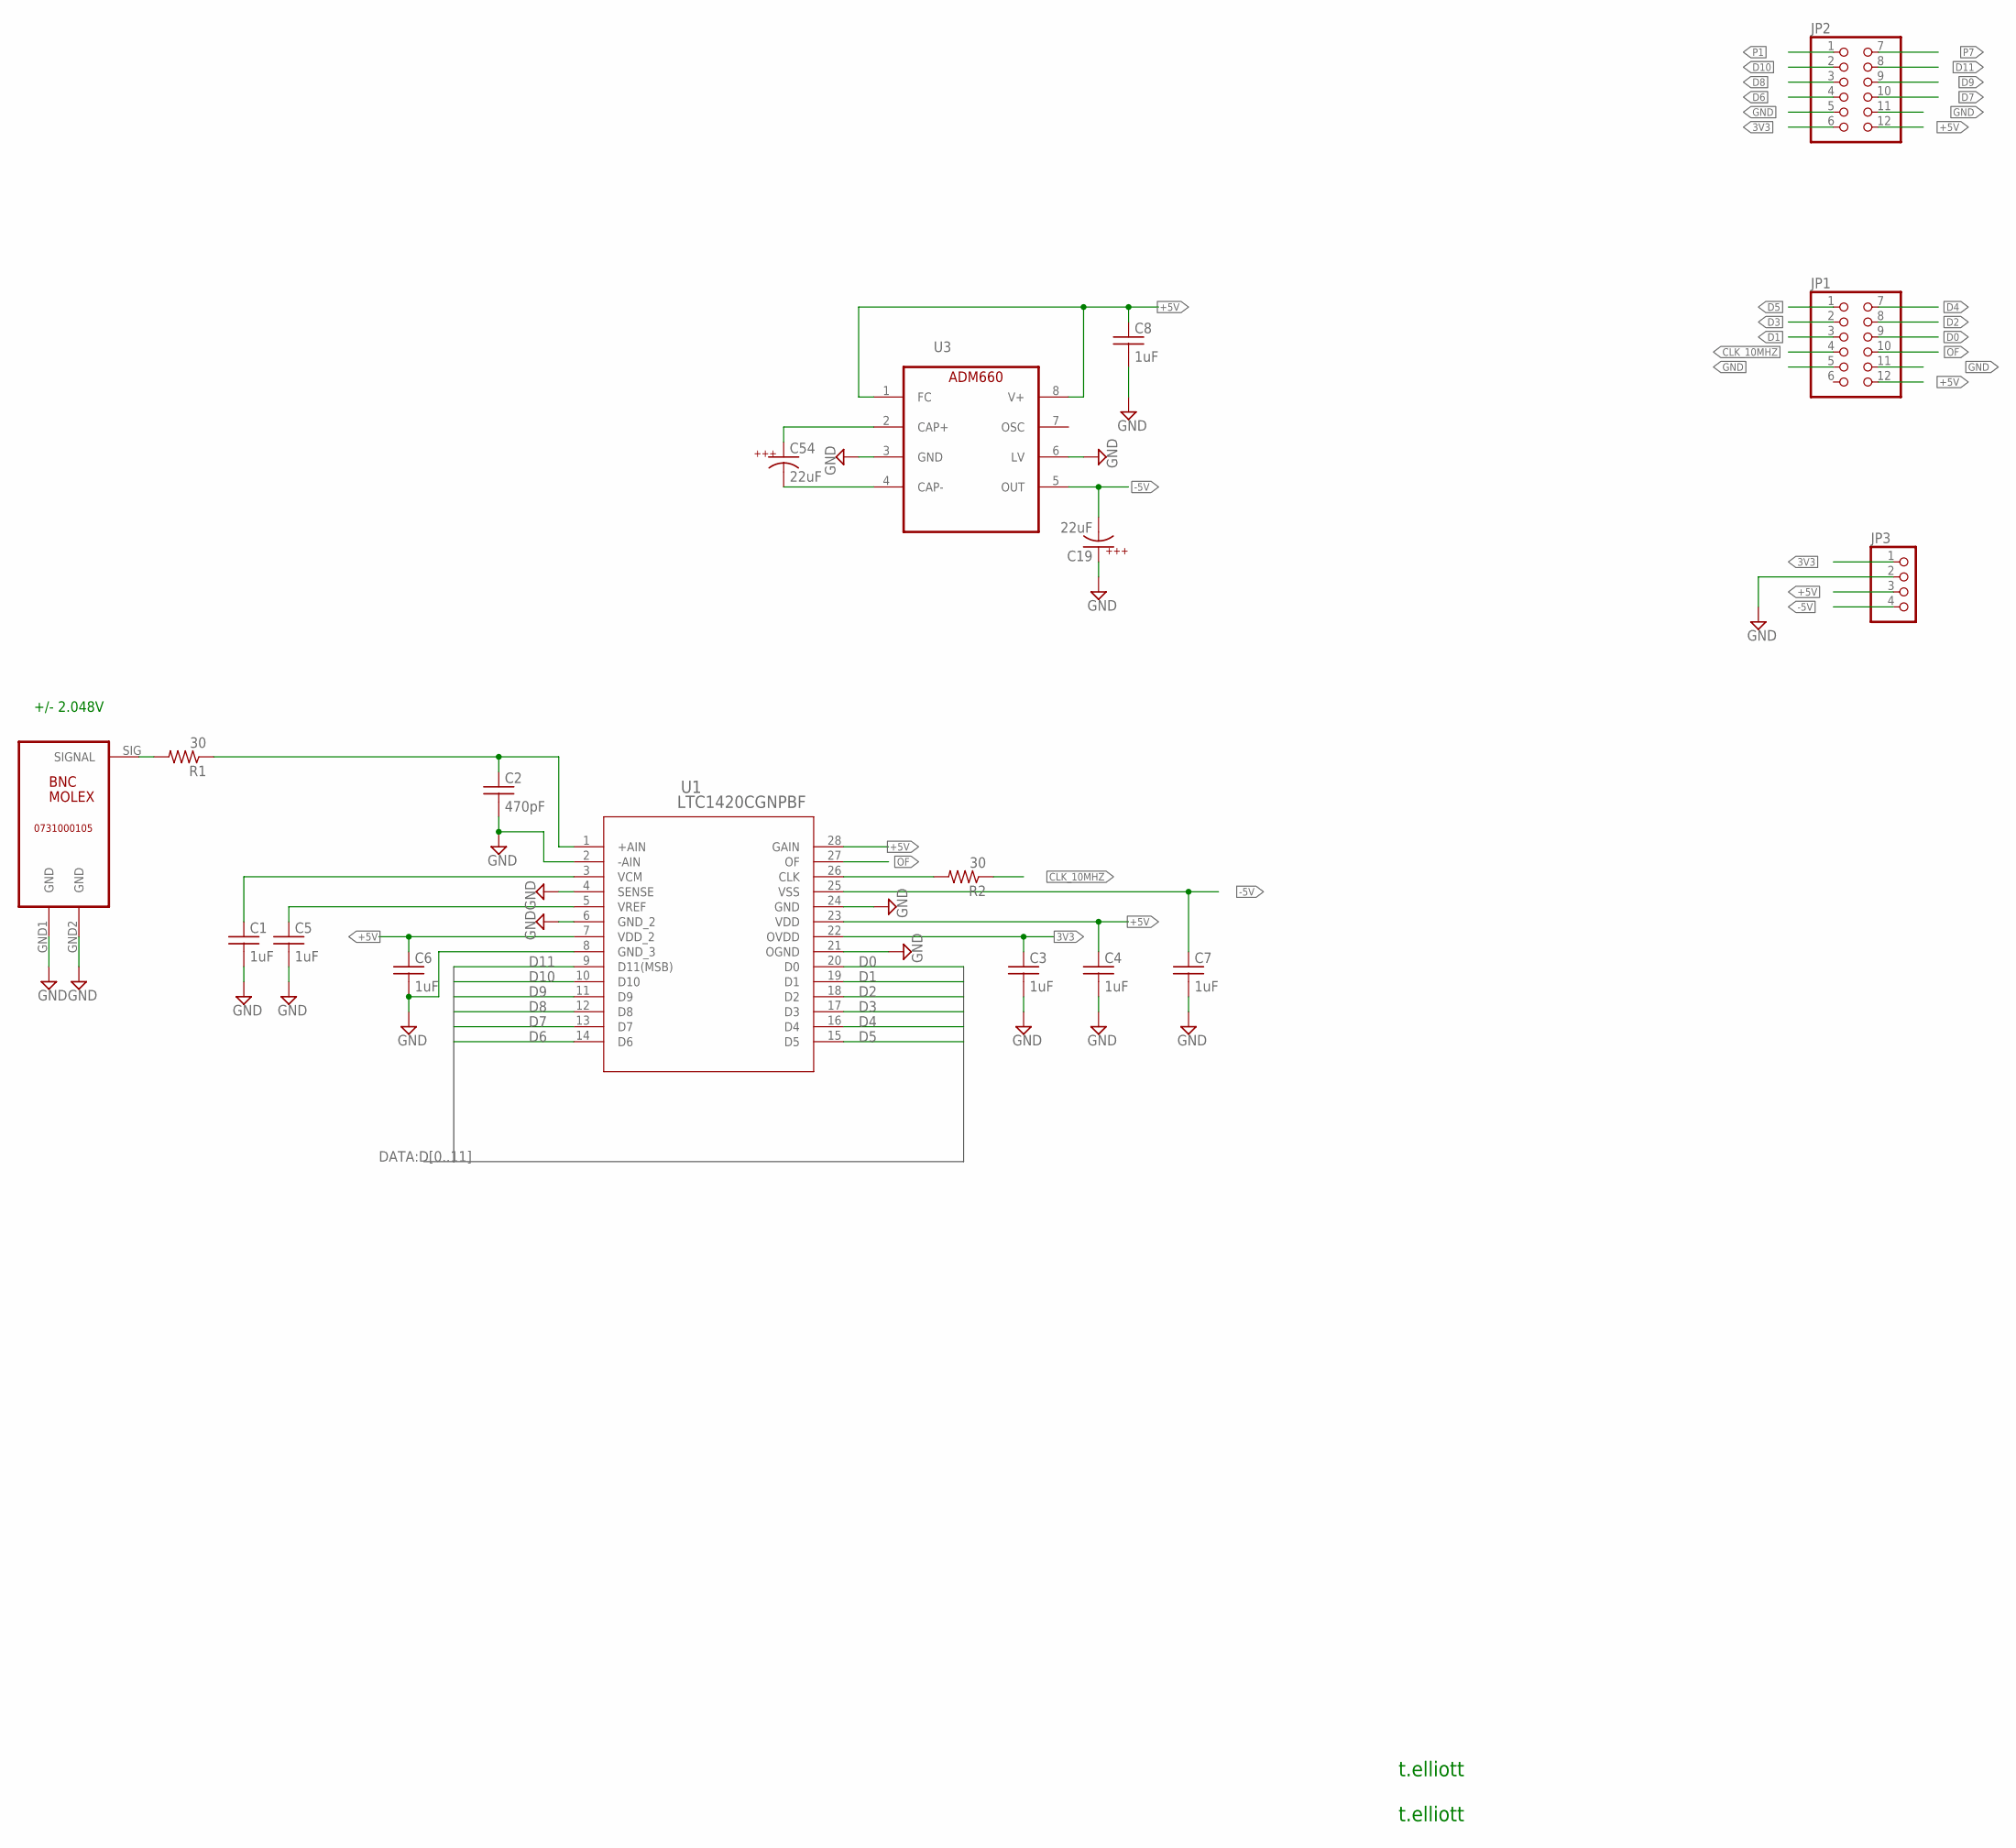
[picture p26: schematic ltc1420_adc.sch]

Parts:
C1, C3, C4, C5, C6, C7, C8: 1uF; C0603
C2: 470pF; C0603
C19, C54: 22uF; 1210K
J1: 0731000105_MOLEX_BNC; BNC
JP1, JP2: PINHD-2X6; 2X06
JP3: PINHD-1X4; 1X04
R1, R2: 30; R0402
U1: LTC1420CGNPBF; SSOP-28_GN
U3: ADM660; SO8

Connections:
3V3: C3.1, JP2.6 (11), JP3.1, U1.22 (OVDD)
+5V: C4.1, C6.1, C8.1, JP1.12, JP2.12, JP3.3, U1.7 (VDD_2), U1.23 (VDD), U1.28 (GAIN), U3.1 (FC), U3.8 (V+)
-5V: C7.1, C19.C, JP3.4, U1.25 (VSS), U3.5 (OUT)
CLK_10MHZ: JP1.4 (7), R2.1
D0: JP1.9 (6), U1.20 (D0)
D1: JP1.3 (5), U1.19 (D1)
D2: JP1.8 (4), U1.18 (D2)
D3: JP1.2 (3), U1.17 (D3)
D4: JP1.7 (2), U1.16 (D4)
D5: JP1.1, U1.15 (D5)
D6: JP2.4 (7), U1.14 (D6)
D7: JP2.10 (8), U1.13 (D7)
D8: JP2.3 (5), U1.12 (D8)
D9: JP2.9 (6), U1.11 (D9)
D10: JP2.2 (3), U1.10 (D10)
D11: JP2.8 (4), U1.9 (D11(MSB))
GND: C1.2, C2.2, C3.2, C4.2, C5.2, C6.2, C7.2, C8.2, C19.A, J1.GND1 (GND), J1.GND2 (GND), JP1.5 (9), JP1.11 (10), JP2.5 (9), JP2.11 (10), JP3.2, U1.2 (-AIN), U1.4 (SENSE), U1.6 (GND_2), U1.8 (GND_3), U1.21 (OGND), U1.24 (GND), U3.3 (GND), U3.6 (LV)
unnamed: C2.1, R1.1, U1.1 (+AIN)
unnamed: C1.1, U1.3 (VCM)
unnamed: J1.SIG (SIGNAL), R1.2
unnamed: C5.1, U1.5 (VREF)
unnamed: R2.2, U1.26 (CLK)
unnamed: C54.A, U3.2 (CAP+)
unnamed: C54.C, U3.4 (CAP-)
OF: JP1.10 (8), U1.27 (OF)
P1: JP2.1
P7: JP2.7 (2)

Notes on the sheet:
t.elliott
+/- 2.048V



Board: 4 copper layers, 28.3 x 35.7 mm, 18 parts (3 on the bottom side), 25 nets.

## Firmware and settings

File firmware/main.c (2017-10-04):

//MIT License
//
//Copyright (c) 2017 tvelliott
//
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
#define ARM_MATH_CM4

#include "arm_math.h"
#include "arm_const_structs.h"
#include "bh_fft_win.c"

#include <stdint.h>
#include <stdlib.h>
#include <string.h>

#include "main.h"

#include "stm32f4xx_flash.h"
#include "stm32f4xx_spi.h"
#include "stm32f4xx_iwdg.h"
#include "stm32f4x7_eth.h"
#include "stm32f4xx_rcc.h"
#include "stm32f4xx_gpio.h"

#include "netconf.h"
#include "global.h"
#include "std_io.h"
#include "telnet.h"
#include "crc.h"
#include <math.h>
#include <ctype.h>
#include <stdio.h>
#include "config.h"
#include "iperf.h"
#include "flash_sst.h"
#include "fpga.h"
#include "Playtune.h"


//FFT stuff
#define SAMPLES                    2048            //real 
#define FFT_SIZE                SAMPLES / 2        // FFT size 1024 
#define DIRECTFFT    0
#define INVERSEFFT   1
#define NOREVERSE    1
#define REVERSE    1

float32_t Input[SAMPLES];
float32_t Output[FFT_SIZE];
arm_cfft_radix2_instance_f32 fftS;    //ARM CFFT module 

RCC_ClocksTypeDef RCC_Clocks;

static int n;
volatile uint32_t prev_ms_timer;
volatile int midi_off_time;

volatile uint32_t local_time_ms;
volatile uint32_t ms_timer;
volatile int8_t all_initialized;

int do_test_mem;
int mem_test_cont;

int8_t do_play_midi;

volatile uint32_t tick_count;
volatile uint32_t LocalTime;

extern int ethernet_link_initialized;
extern int ethernet_post_link_done;

volatile int uptime_seconds;
volatile int prev_uptime_seconds;
volatile int fw_reset_time;
volatile int uptime_mod;
volatile int do_reset_flag=0;

/////////////////////////////////////////////////////////////////////
//variables touched in SysTick Interrupt Handler
/////////////////////////////////////////////////////////////////////
volatile int8_t do_eth_init_tick;
volatile int do_print_prompt;
volatile int lwip_initialized;
volatile int check_firmware_update;
static volatile int8_t do_tcp_poll;

/////////////////////////////////////////////////////////////////
/////////////////////////////////////////////////////////////////
int should_do_tcp_poll()
{
  if(do_tcp_poll) {
    do_tcp_poll=0;
    return 1;
  }

  return 0;
}

///////////////////////////////////////////////////////////////////////////////
///////////////////////////////////////////////////////////////////////////////
void do_system_reset()
{
  int secs=0;

  while(1) {
    handle_ethernet(1);

    do_main_tasks(0);

    if(prev_uptime_seconds!=uptime_seconds) {
      prev_uptime_seconds=uptime_seconds;
      secs++;
    }

    if(secs>1) break;

  } //handle lwip, but don't reset watchdog

  NVIC_SystemReset();
}
///////////////////////////////////////////////////////////////////////////////
///////////////////////////////////////////////////////////////////////////////
void save_config()
{
  uint32_t prim = __get_PRIMASK();
  __disable_irq();

  write_config(&config);

  if(!prim) {
    __enable_irq();
  }
}

///////////////////////////////////////////////////////////////////////////////
///////////////////////////////////////////////////////////////////////////////
int main(void)
{
  int i;
  uint8_t *ptr;
  GPIO_InitTypeDef  GPIO_InitStructure;

  //SystemInit();

  srand(1);
  RCC_APB2PeriphClockCmd(RCC_APB2Periph_SYSCFG, ENABLE);

  RCC_GetClocksFreq(&RCC_Clocks);


  RCC_AHB1PeriphClockCmd(RCC_AHB1Periph_GPIOA | RCC_AHB1Periph_GPIOB | RCC_AHB1Periph_GPIOC | RCC_AHB1Periph_GPIOD
                         | RCC_AHB1Periph_GPIOE | RCC_AHB1Periph_GPIOF | RCC_AHB1Periph_GPIOG, ENABLE);

  SysTick_Config(RCC_Clocks.HCLK_Frequency / 50);


  //enable FPU
  *((volatile unsigned long*)0xE000ED88) = 0xF << 20;


  read_config();
  fpga_init();
  ETH_BSP_Config();

  //do {
  init_flash_sst();

  config_changed(); //leave this after read_pdata, so mur_mode gets updated properly

  uart3_init(115200);

  if(!lwip_initialized) {
    lwip_initialized=1;
    lwip_init();
    telnet_init();
    tcp_iperf_init();
  }



  init_stm_timers();


  all_initialized=1;


  //flush sdi buffers


  set_timer2(0);

  init_fsmc();

  while(1) {

    do_main_tasks(1);


    if(do_reset_flag) {
      do_reset_flag=0;
      close_telnet();
      do_system_reset();
    }

    if(do_test_mem) {
      if(!mem_test_cont) do_test_mem=0;
      test_mem();
    }

    if(do_testflash1) {
      do_testflash1=0;
      test_flash(0);
    }

    if(do_testflash2) {
      do_testflash2=0;
      test_flash(1);
    }

    if(do_testadc) {
      do_testadc=0;
      test_adc();
      print_prompt();
    }

    if(do_eth_init_tick) {
      do_eth_init_tick=0;
      eth_init_tick();
    }


  } //while


}

/////////////////////////////////////////////////////
/////////////////////////////////////////////////////
void fft_shift(float32_t *data, int len) {
float32_t tmp[2048];
int i;
    if(len>2048) len=2048;

    for(i=0;i<len/2;i++) {
        tmp[i] = data[i+len/2]; 
    }
    for(i=0;i<len/2;i++) {
        tmp[i+len/2] = data[i]; 
    }
    for(i=0;i<len;i++) {
      data[i] = tmp[i];
    }
}

///////////////////////////////////////////////////////////////////////////////////////////////////////////
// fft results indicate that Fs is approximately 1.2 MHz in this async direct sample loop
// With system clock of 168 MHz and currently configured FSMC clk (including all delays)
// We could reach the full Fs of 10 MHz by buffering the ADC in BRAM of FPGA and analyzing after DMA transfer
// to the MCU.  The BRAM is currenlty in use by the audio-synth delay effect example
///////////////////////////////////////////////////////////////////////////////////////////////////////////
void test_adc() {
  static int i;
  static int16_t *adc_ptr = 0x60000010;


  //BTR1
  (*((uint32_t *)(0xa0000004))) = BTR_BRAM_RW_FAST; 


  int index=0;
  for(i=0;i<1024;i++) {
    Input[index++] = (float32_t) *adc_ptr;  //real
    Input[index++] = (float32_t) 0;  //complex 
    DelayClk3(7);
  }

  uint32_t stimer = get_timer2();

  //mult by fft blackman harris window
  if(SAMPLES==1024) {
    arm_mult_f32( Input, fft_win_1024, Input, FFT_SIZE*2);
  }
  else if(SAMPLES==512) {
    arm_mult_f32( Input, fft_win_512, Input, FFT_SIZE*2);
  }
  else if(SAMPLES==2048) {
    arm_mult_f32( Input, fft_win_2048, Input, FFT_SIZE*2);
  }

  //initialize FFT  intflag=0  bitreverse=1
  arm_cfft_radix2_init_f32(&fftS, FFT_SIZE, 0, 1);
  //do FFT_SIZE point complex fft 32-bit 
  arm_cfft_radix2_f32(&fftS,Input);

  //calculate magnitude of fft for each bin 
  arm_cmplx_mag_f32(Input, Output, FFT_SIZE);

  //not needed for this application
  //fft_shift(Output, FFT_SIZE/2);

  int32_t total_time_ms = get_timer2() - stimer;
  float32_t tot_time_ms_f = (float32_t) total_time_ms / 42000.0f;

  //NOTE: if the sample rate, delays, etc are changed.  These need to be adjusted
  #define VPP_SCALE 7.530865e-7f 
  #define FREQ_SCALE 1279.07324f 

  printf("\r\n");
  for(i=0;i<512;i++) {  //we throw out the last half of results since input imaginary was zero and results in image in second half.
    printf("%4.5f,", Output[i]*VPP_SCALE);  //scale to voltage peak-to-peak for periodic sine wave input
  }

  float32_t max = -1e6f;
  int max_bin=0;
  //don't look in first few bins to ignore any dc offset
  for(i=5;i<512;i++) {  
    if(Output[i]>max) {
      max = Output[i];
      max_bin=i;
    }
  }

  
  //results should be fairly accurate for 10khz to 650khz, < 2 millivolts p-p,  up to 4 volts p-p with current configuration
  if(max_bin>0) {
    float32_t freq = FREQ_SCALE * (float32_t) max_bin;
    printf("\r\npeak signal %4.3f Hz,  %4.3f Volts p-p, elapsed FFT Mag time %3.2f ms", freq, Output[max_bin]*VPP_SCALE, tot_time_ms_f); 
  }
  

}

///////////////////////////////////////////////////////////////////////////////////////////////////////////
///////////////////////////////////////////////////////////////////////////////////////////////////////////
void check_ms_timer()
{
  uint32_t timer2 = get_timer2();
  uint32_t prim;

  //has millisecond passed yet?
  if(timer2>42000) {
    clear_timer2();
    local_time_ms++;
    LwIP_Periodic_Handle(local_time_ms);

    if(do_play_midi) {
      tune_stepscore();
      if(!tune_playing) do_play_midi=0;
      midi_off_time=0;
    } else {
      //turn delay off
      if(midi_off_time==2) {
        uint16_t *audio_ctrl_ptr = (uint16_t *) 0x60001000;
        *audio_ctrl_ptr&=0xfffd; //turn on waveform generation
      }
    }

    if(prev_uptime_seconds!=uptime_seconds) {
      prev_uptime_seconds=uptime_seconds;
      //printf("\r\nuptime_seconds: %d", uptime_seconds);

      //if(ne4_count!=0) printf("\r\nne4 count: %d", ne4_count);
      //ne4_count=0;
      midi_off_time++;

      puts_u3("\r\ntest uart3", 12);
    }

  }

}

///////////////////////////////////////////////////////////////////////////////
///////////////////////////////////////////////////////////////////////////////
void do_main_tasks(int ltick)
{

  handle_ethernet(ltick);
}

///////////////////////////////////////////////////////////////////////////////
///////////////////////////////////////////////////////////////////////////////
void handle_ethernet(int ltick)
{
  extern void *pdev_device;
  int offset;
  int count;
  int16_t len;
  int i;
  FrameTypeDef frame;

  while( ETH_CheckFrameReceived() ) {
    frame = ETH_Get_Received_Frame();

    // Release descriptors to DMA
    // Check if frame with multiple DMA buffer segments
    if (DMA_RX_FRAME_infos->Seg_Count > 1) {
      DMARxNextDesc = DMA_RX_FRAME_infos->FS_Rx_Desc;
    } else {
      DMARxNextDesc = frame.descriptor;
    }

    // Set Own bit in Rx descriptors: gives the buffers back to DMA
    for (i=0; i<DMA_RX_FRAME_infos->Seg_Count; i++) {
      DMARxNextDesc->Status = ETH_DMARxDesc_OWN;
      DMARxNextDesc = (ETH_DMADESCTypeDef *)(DMARxNextDesc->Buffer2NextDescAddr);
    }

    // Clear Segment_Count
    DMA_RX_FRAME_infos->Seg_Count =0;

    // When Rx Buffer unavailable flag is set: clear it and resume reception
    if ((ETH->DMASR & ETH_DMASR_RBUS) != (u32)RESET) {
      // Clear RBUS ETHERNET DMA flag
      ETH->DMASR = ETH_DMASR_RBUS;
      // Resume DMA reception
      ETH->DMARPDR = 0;
    }

    if( frame.length > 0 && frame.length<=1514) {
      //if raw filter doesn't do anything, then pass on to lwip
      memcpy(Rx_Buff, (uint8_t *) frame.buffer, frame.length);

      lwip_packet_in_eth((uint8_t *) Rx_Buff, frame.length);
    }
  }
  if(ltick) check_ms_timer();

}

///////////////////////////////////////////////////////////////////////////////
///////////////////////////////////////////////////////////////////////////////
void handle_systick(void)
{

  if(++uptime_mod%50==0) uptime_seconds++;

  if(!all_initialized) return;

  if( LocalTime%200==0) {
    do_tcp_poll=1;
  }

  do_eth_init_tick=1;

  if(fw_reset_time>0) fw_reset_time--;

}


///////////////////////////////////////////////////////////////////////////////
///////////////////////////////////////////////////////////////////////////////
void assert_param(int pass)
{
}

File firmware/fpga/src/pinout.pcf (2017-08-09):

set_io LED2 A1 
set_io LED3 A2 
set_io LED4 A5 
set_io clk R9 
set_io AUDIO_SDIN T8 
set_io AUDIO_SCLK T7 
set_io AUDIO_LRCLK T6 
set_io AUDIO_MCLK T5 
set_io CBSEL P13
set_io PMOD1_1 P2
set_io PMOD1_2 R2 
set_io PMOD1_3 T1 
set_io PMOD1_4 T3
set_io PMOD1_7 P1
set_io PMOD1_8 R1
set_io PMOD1_9 R3
set_io PMOD1_10 T2
set_io PMOD2_1 K1 
set_io PMOD2_2 L3
set_io PMOD2_3 M2 
set_io PMOD2_4 N3 
set_io PMOD2_7 K3 
set_io PMOD2_8 L1 
set_io PMOD2_9 M1 
set_io PMOD2_10 N2 
set_io PMOD3_1 F2 
set_io PMOD3_2 G3
set_io PMOD3_3 H1 
set_io PMOD3_4 J2 
set_io PMOD3_7 F1 
set_io PMOD3_8 G2 
set_io PMOD3_9 H2 
set_io PMOD3_10 J1 
set_io PMOD4_1 B3 
set_io PMOD4_2 C3 
set_io PMOD4_3 D3 
set_io PMOD4_4 E3 
set_io PMOD4_7 B2 
set_io PMOD4_8 C2 
set_io PMOD4_9 D2 
set_io PMOD4_10 E2 
set_io P_A6 A6 
set_io P_A7 A7 
set_io P_A9 A9 
set_io P_A10 A10 
set_io P_A11 A11 
set_io P_B6 B6 
set_io P_B7 B7 
set_io P_B8 B8 
set_io P_B9 B9 
set_io P_B11 B11 
set_io A0 C16 
set_io A1 T15 
set_io A2 R16 
set_io A3 R15 
set_io A4 P16 
set_io A5 P15 
set_io A6 N16 
set_io A7 M16 
set_io A8 M15 
set_io A9 L16 
set_io A10 T14 
set_io A11 R14  
set_io A12 P14 
set_io A13 L14 
set_io A14 D14 
set_io A15 C14 
set_io D0 D16 
set_io D1 D15 
set_io D2 B16 
set_io D3 B15 
set_io D4 A16 
set_io D5 A15 
set_io D6 E16 
set_io D7 F15 
set_io D8 F16 
set_io D9 G15 
set_io D10 G16 
set_io D11 J15 
set_io D12 J16 
set_io D13 K15 
set_io D14 K16 
set_io D15 T16 
set_io FSMC_NOE F14 
set_io FSMC_NWE H14 
set_io FSMC_NE1 J14 
set_io FSMC_NE4 K14 
set_io FSMC_NL_NADV B14
set_io FPGA_SPI_SCLK R10
set_io FPGA_SPI_MOSI P10
set_io FPGA_SPI_MISO N12
set_io FPGA_SPI_CS T13
set_io FSMC_CLK K9 

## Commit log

2017-08-13 fixed header file issue with compling fft / dsp example. added USB/serial test firmware
    [main.c, uart3.c]
2017-10-04 fix buffer overflow in test_adc()
    [main.c]

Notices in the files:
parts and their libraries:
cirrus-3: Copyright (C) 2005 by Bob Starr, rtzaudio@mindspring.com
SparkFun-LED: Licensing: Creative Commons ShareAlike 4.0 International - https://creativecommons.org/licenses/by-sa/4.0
